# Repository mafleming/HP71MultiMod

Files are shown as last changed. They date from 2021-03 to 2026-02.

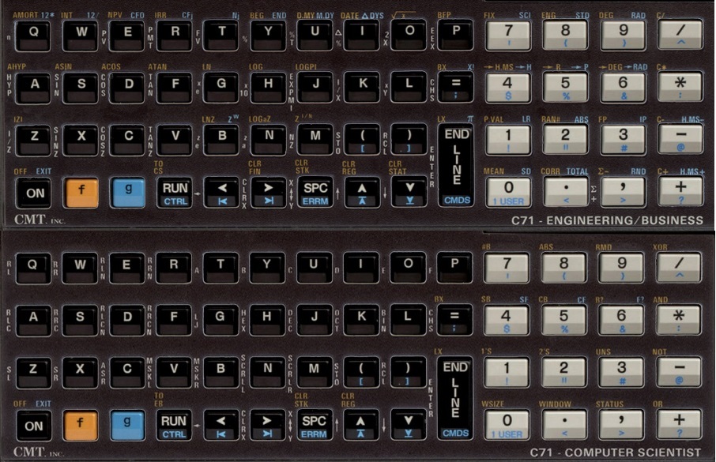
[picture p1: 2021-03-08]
doc/c71_ovl.jpg

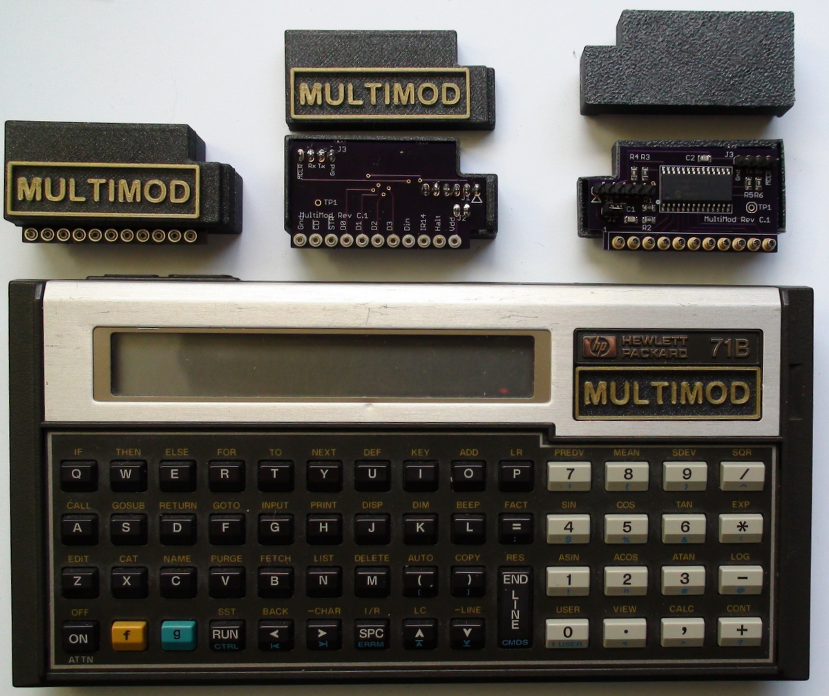
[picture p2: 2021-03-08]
MultiMod Board and Enclosure.JPG

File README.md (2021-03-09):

HP71MultiMod Repository

# A ROM Emulator Board for the HP-71B
This repository contains the source and data files associated with
the MultiMod ROM emulator board. The board fits into the Card Reader
well of the HP-71B and can be used with an optional enclosure.

The emulator is easily programmed using just a USB to TTL Serial cable.
The emulator can enumerate up to 112 KB of ROM images stored in 7 16 KB
"chips" that can be combined to form ROMs of size 16 KB, 32 KB, 48 KB,
or 64 KB.

Further details on the ROM emulator, how it works and how to use it, can
be found in the User Manual.

# Directory structure
- The **BIN** directory will contain ROM images in .BIN format. For the
moment, images of HP ROMs are not present. ROM images available from and
hosted by others will only be added by permission. Links will be provided
in the meantime.
- The data files containing ROM images can be found in the **DAT** directory.
- The **HEX** directory will contain files that can be used to program the PIC
processor in the MultiMod directly using a Microchip programmer and IPE
software.
- The **LIF** directory contains floppy disk images in HP's proprietary LIF
format. These images contain various useful programs.
- The **doc** directory contains documentation for the MultiMod emulator
as well as for some of the ROM images.
- The **utils** directory contains useful utilities, including python scripts
to convert .BIN files into the .DAT files used by the MultiMod serial monitor.
- The **src** directory contains the MPASM assembly source files used to
program the MultiMod PIC processor. Version 5.35 or earlier of the Microchip
MPLAB IDE X is needed to use the MPASM assembler and linker.

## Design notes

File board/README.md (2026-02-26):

HP71MultiMod Repository

# A ROM Emulator Board for the HP-71B
This directory contains the Gerber files for creating a MultiMod PCB
along with PDF files of the schematic and BOM. The original design was
created using Eagle CAD 5.0, a PCB design platform that sadly went
extinct quite some years ago.

The board uses SMD parts so you'll either need a reflow oven (I built
one from the Wizzo kit, link below) or have the fine motor skills needed to
solder the parts yourself. The passives are 0805 in size which is
reasonably large for hand soldering. The part numbers given in the BOM are
from Mouser, but you can substitute manufacturer and supplier while
maintaining proper value. No substitute on the PIC CPU unless you know what
you're doing!

https://www.ebay.com/itm/305219966463

Once a board is assembled you'll need to program the PIC CPU using either
a PICKit-3 or PICKit-4 programmer, and the MPLAB X IPE or IDE software.
I developed the code and program PICs using version 5.50, available for
Windows and Linux.

I've used OSH Park as my PCB supplier and OSH Stencil for the solder paste
application.

## MultiMod Enclosure
Recently added are the STL files for the top and bottom half of the MultiMod
enclosure. Enjoy!

## Press Fit Harwin Sockets
The Sockets.jpg image shows how I press fit the Harwin sockets into a MultiMod
PCB. The three parts of the image show

- (a) The socket holder is a brass piece about 1/4" square. In it are drilled
11 holes 0.15" apart with a #38 or 5/32" drill. The holes are slightly larger
than the socket body and provide a loose fit for the socket tail end.
- (b) I usually start the press fit with the outer six sockets, followed by the
inner five. Note that the socket heads are inserted from the back of the board,
with the socket tails upward from the component side of the PCB.
- (c) Place the board and socket holder in a vise, then press the outer six
sockets for a partial fit. Add the inner five sockets and press all eleven to
final position. Don't press the sockets all the way down, leave about a
fingernail width between the bottom of the socket head and the PCB surface.
This will provide a tight fit in the board without a chance of crushing the
socket body.

The Card Reader pins are 1 mm in diameter. I use the shaft end of a number 61
drill inserted into the socket from the socket head end to clear the sockets
before inserting the board into the Card Reader well.

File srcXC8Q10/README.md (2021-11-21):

MultiModII.X

These source files are suitable for the PIC18F2-Q10 family of processors. The
low power requirements of the Q10 make it suitable for a front port module
implementation. The bootloader and serial port monitor code has been removed.
ROM images and code would be updated using a PICKit-3 or better programmer.

The project is built in a similar way as the main MultiMod code in the src/
subdirectory. Instead of the MPASM assembler, the pic-as assembler in the XC8
compiler package is used. Use the MPLAB X IDE version 5.45 or higher. Create
a standalone project, select the PIC18F27Q10 as the target processor, select the
pic-as assembler as the build tool, and then add these files to the Source Files
folder of the project directory tree in the IDE. Assemble, Link, then program
using a PICKit-3 or PICKit-4 programmer.

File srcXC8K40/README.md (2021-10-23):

HP71MultiMod Repository

# A ROM Emulator Board for the HP-71B
**23-October-2021**

Source files for the MultiMod board. These files
are assembled, linked, and loaded with pic-as v2.32 in MicroChip MPLAB X IDE v5.45.
The assembler is part of the XC8 development compiler. MPLAB X and XC8
can be obtained from Microchip.com in their development tools repository.

This port of the MultiMod application code from MPASM to pic-as has been done
for two reasons; MPASM is no longer supported by Microchip, and the pic-as
assembler is needed to transfer code to more recent PIC microcontrollers.

# Build Instructions
First create a standalone application project with the suggested name of
MultiModK40. Copy all  files to the base project directory.
In the Project Configuration dialog under Loading, add the
BootLoaderK40.X.production.hex file.
Be sure to specify the target processor as PIC18F27K40, then build
the project.

# Errata
Maintenance issues that are addressed are listed here.

- Carriage return for the Commit command defaults to NO rather than YES.
- Detect buffer overrun and terminate ROM image upload for Image command.

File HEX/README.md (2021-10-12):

HP71MultiMod Repository

# A ROM Emulator Board for the HP-71B
HEX files used to program the ROM emulator software using a PICKit
or other PIC programmer will be found here. HEX files containing
the entire PIC flash memory including boot loader are named MMimage
with a four digit version number, while files containing only the
ROM emulator code itself are named MultiMod with a four digit version
number.

Instructions for using the boot loader to update the emulator software
can be found in the User Manual appendix. Files are

- MMimagexxyy.hex     Entire PIC flash image for programming tool
- MultiModxxyy.hex    ROM Emulator software image for bootloader

where xx = major number and yy=minor number.

Version 0103 - fixes ROM table corruption when software flow control is
        not used when sending an image to the serial monitor
Version 0104 - fixes failure to unconfigure ROMs when a RESETX command
        is issued

The file devices.zip contains an updated version of the bootloader client
database of PIC microcontrollers. The PIC18 used in the MultiMod has been
added to the database. Rename the default devices.db and replace it with
the one in this devices.zip file before proceeding with the client update
instructions.

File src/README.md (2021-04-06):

HP71MultiMod Repository

# A ROM Emulator Board for the HP-71B
**27-March-2021**

Source files for the current production release of the MultiMod board. These files
are assembled, linked, and loaded with MPASMX in MicroChip MPLAB X IDE v5.35,
which can be obtained from Microchip.com in their development tools repository.

# Errata
Issues that will be addressed in maintenance and enhancement releases are listed here.

- Carriage return for the Commit command should default to NO rather than YES.
- Detect buffer overrun and terminate ROM image upload for Image command.
- Display software version number in serial monitor.
- Display ROM name in ROM Configuration Table listing.
- Locate serial monitor on sector boundary so it can be updated separately from emulator.
- Allow readback (PEEK$) of MMIO configuration buffer data.
- Make timeout to processor sleep state configurable by user (current default 2.5 minutes).

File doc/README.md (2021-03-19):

HP71MultiMod Repository

# A ROM Emulator Board for the HP-71B

The User Manual for the MultiMod board can be found here along with other
ROM related documentation. Documentation for the HP ROMs can be found in
various locations, but they are also collected together in one place in
the Museum of HP Calculators flash drive. See the link below for details
on ordering a copy

https://www.hpmuseum.org/cd/cddesc.htm

|Filename | Document |
| ----- | ----- |
| C71.pdf | The Soft Forth-based RPN calculator emulator manual |
| doc_lib52.txt | Documentation for J-F's User Library of LEX files |
| symbolix.txt | Joe Horn's Symbolic CAS Basic program documentation |

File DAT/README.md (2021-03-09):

HP71MultiMod Repository

# A ROM Emulator Board for the HP-71B
The following files represent data images of well-known ROMs available
for the HP-71B. The table shows the ROM content of each file. These
data files were created from the original .BIN files using the utility
program bintodat.py

|Filename | HP-71B ROM | Size |
| ----- | ----- | -----  |
| accap.dat | The AC Circuit Analysis ROM | 16K |
| ampi-stat.dat |The Ampi-Statistics ROM | 32K |
| c71.dat | The C71 Forth-based RPN Calculator ROM | 64K |
| curve-fit.dat | The Curve Fitting ROM | 32K |
| data-acq.dat | The Data Acquisition ROM | 64K |
| data-comm.dat | The Data Communications ROM | 16K |
| finance.dat | The Finance ROM | 16K |
| forth1b.dat | The Forth-Assembler ROM | 16K |
| forth1bhrd.dat | The Forth-Assembler Hard ROM | 32K |
| hp41trans.dat | The HP-41 Translator ROM | 16K |
| hp41transhrd.dat | The HP-41 Translator Hard ROM | 32K |
| hpil1b.dat | The HP-IL version 1B ROM | 16K |
| joesbest.dat | A Collection of LEX Files by Joe Horn | 32K |
| joesbest-nokbeep.dat | Joe's Collection Without KBEEP | 32K |
| jpcf05.dat | The JPC ROM Maintained by J-F Garnier | 32K |
| math.dat | The Math Pac ROM | 32K |
| math2b.dat | J-F Garnier's Extension of Math Pac | 32K |
| math-p.dat | | 32K |
| surveying.dat | The Surveying ROM | 16K |
| symbolix.dat | Joe Horn's Symbolix CAS Program | 32K |
| text-edit.dat | The Text Editor ROM | 16K |
| ulib52.dat | J-F Garnier's LEX User Library | 32K |
| ulibcopy.dat | J-F's Library with the ROMCOPY LEX | 32K |

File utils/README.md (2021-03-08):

HP71MultiMod Repository

# A ROM Emulator Board for the HP-71B
Utility and support files are provided in this directory. The most
significant for MultiMod configuration is the python3 script
bin2dat.py which is run using the command

python3 bin2dat.py <.BIN filename> <.DAT file name>

If input and output files are not specified, then they default to
standard input and standard output.

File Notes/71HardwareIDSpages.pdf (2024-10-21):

+------- | ----------------------------------+ -------- | -+

+----- ------- ------------- -----------------+- ----------------+

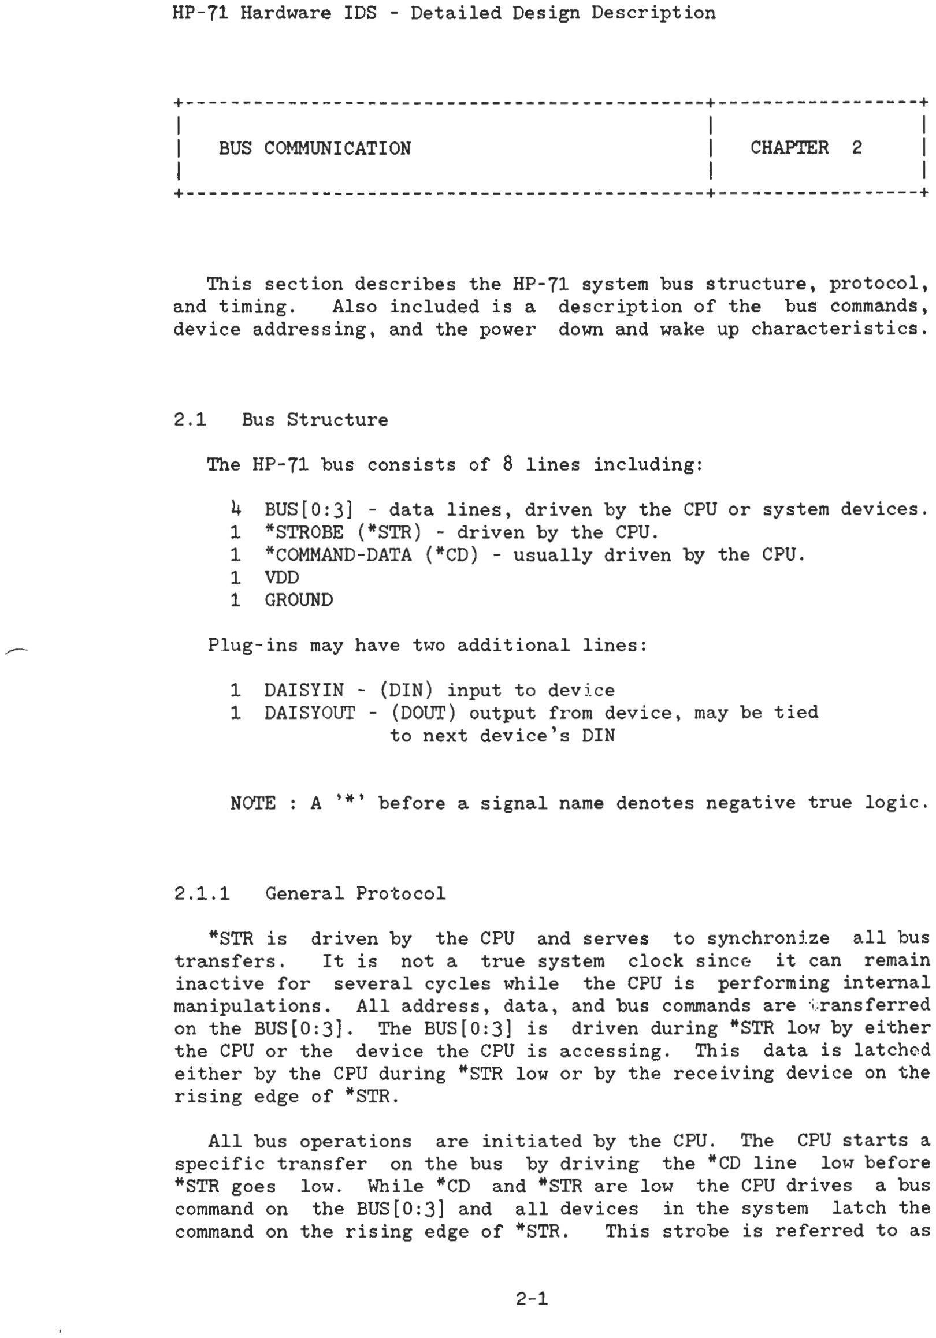
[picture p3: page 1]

Hardware IDS - | Descr | ion
BUS | CHAPTER 2

2.1

The
4
1
1
1
1

section describes the
Also included is a
address ,and the power

Bus Structure

bus structure, | ,
descr | ion of the bus commands,
down and wake up | sties.

bus consists of 8 lines

BUS[O:3] | data lines, | CPU or | devices.
( | ) - driven
( | ) - | the CPU.
VDD
GROUND

ins may have two additional lines:

1 DAISYIN-
1 DAISYOUT | from device, may be tied
to next device's DIN
NOTE | A '*' before a s | name denotes | true
2.1.1 | General Protocol
is driven | the CPU and serves to | ize all bus
transfers. | It is not a true | clock since it can remain
inactive for several | while the CPU is | internal
ions. All addres s , data, and bus commands are ·i.rans ferred
on the BUS[O:3J. The BUS[O:3] is driven | low | either
the CPU or the device the CPU is access | This data is latched
the CPU | low or | the rece | device on the
ris | of
All bus | ions are ini tj.ated | The CPU starts a
ific transfer on the bus | | the | line low before
goes low. While | and | the CPU drives a bus
command on the BUS[O:31 and all devices | latch the
command on the ris | of | This strobe is referred to as
| 2-1

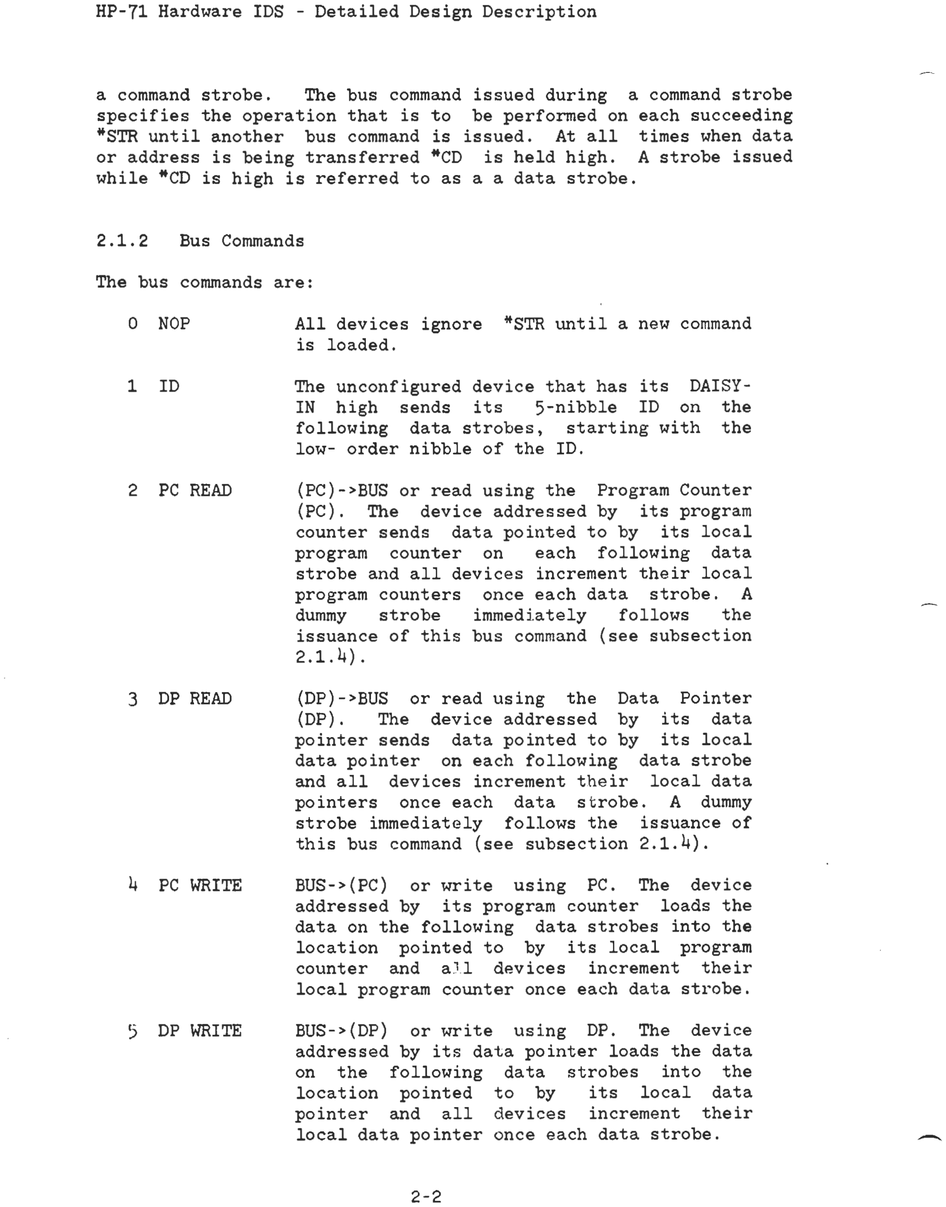
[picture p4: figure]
Hardware IDS - Deta; Des; a command strobe. ies the unt il another or address is be; while; The bus command; a command strobe; that is to; on each; transferred; is held; A strobe issued; is referred to as a a data strobe.; Bus Commands; The bus commands are:; o NOP; 2 PC READ; 3 DP READ; 4 PC WRITE; 5 DP WRITE; All devices is loaded.; until a new command; unconf; device that has its DAISY-; sends its; 5-nibble ID on the; data strobes, start; with the; low- order nibble of the ID.; (PC)->BUS or read us; the; Counter; (PC). The device addressed; program; counter sends data pointed to; its local; program counter on; each; data; strobe; follows; ) >BUS or read us; the Data Pointer; The device addressed; its data; sends data pointed to; data pointer on each; data strobe; pointers once each data strobe. A; strobe immed; follows the issuance of; BUS->(PC) addressed data on the; see subsection 2.1.4).; or write us; PC. The device; its program counter loads the data strobes into the; location; its local program; BUS->(DP) addressed on the location; write us; DP. The device; data pointer loads the data data strobes into the; its local data; pointer and all devices increment their

bus command is issued. At all t when data

strobe and all devices increment their local program counters once each data strobe. A

issuance of this bus command (see subsection

and all devices increment their local data

counter and a.¹.1 devices increment their local program counter once each data stl'obe.

local data pointer once each data strobe.

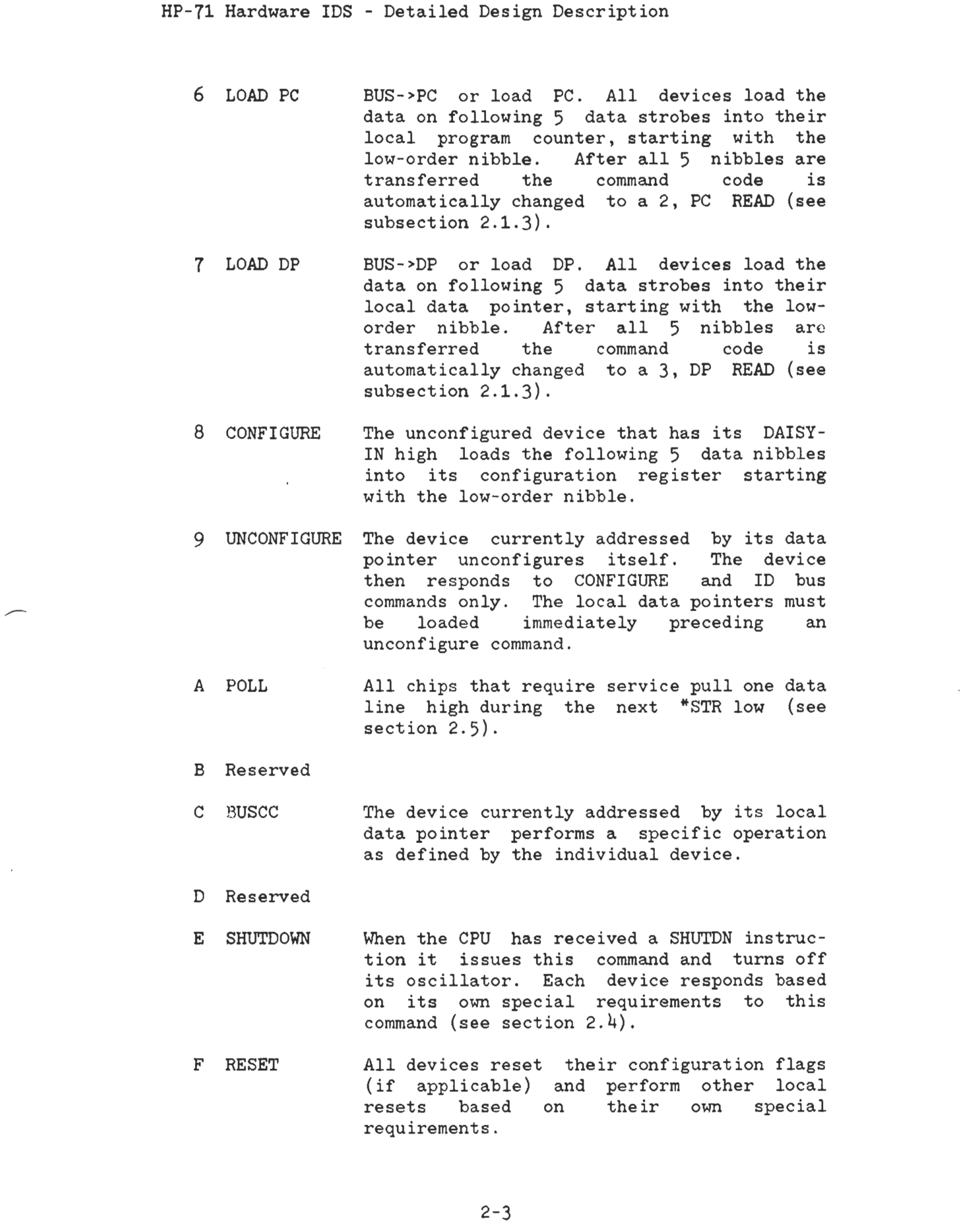
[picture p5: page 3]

Hardware IDS - Detailed Des | Descr | ion

6 LOAD PC

7 LOAD DP

8 CONFIGURE

9 UNCONFIGURE

A POLL

B Reserved

C BUSCC

D Reserved

E SHUTDOWN

F RESET

BUS->PC or load PC. All devices load the
data on | | 5 data strobes | | their
local program counter, | with the
low-order nibble. | After all 5 nibbles are
transferred | the | command | code | is
automat | to a 2, PC READ (see
subsection 2.1.3).
BUS->DP or load DP. All | load the
data on | 5 data strobes into their
local data pointer, start | with the low-
order nibble. | After all 5 nibbles aro
transferred | the | command | code | is
automat | to a 3, DP READ (see
subsection 2.1.3)

The
IN h

that has its DAISY-5 data nibbles
into its
with the low-order

line

immed
command.

section 2.5).

The device

addressed
itself.
CONFIGURE
local

service
next
data pointer | a

its data
The device
and ID bus
must
an

one data
low (see

as defined the individual device.

When the CPU has received a SHUTDN instruc-tion it issues this command and
its oscillator. Each device

turns off
based
on its own special | irements to this
command (see section 2.

All devices reset
(if | )
resets | based
s.

2

their conf
and
on their

ion
other
own

local

Hardware IDS - Detailed Des | ion
2.1.3 | Command Auto-Switch

There exists one special ~nse in which all devices
current bus command. | This is called 'auto"switch'
fo | the load of either the PC or the DP. | On the
of | nibble of address has been loaded
clear bit 2 of their command latch | the bus
a LOAD PC to PC READ or LOAD DP to DP READ.
2.1.4 | Strobe

their
and occurs
ris
all devices
command from

a PC READ bus command, a DP READ bus
command, and a command auto-switch the CPU issues a ' | strobe'.
This | strobe appears as a data strobe | that no data is
transferred | this | not ilJ.:rement their
local address
a full strobe

2.2 Address

sters.
for the

Each device on the HP-local program counter (PC) device is also either
or
address space
reads and writes
on the read or
space.

The HP-

memory devices
first access and therefore allows data

bus has two 20-bit address
and a local data pointer
addressed at a specific address located within
to
(PC or DP

the
data
its | address

allows soft
have address | size from
All devices are | that the | of the
local address | with the | bits of
the device's | or soft). | If these bits
are identical, the devi.ce has an address match and will | to
read and write commands (and the | and BUSCC commands if
). Each device with a given address space size compares
a given number of the | bits of address. For | , a
device with an address space size of 1K | or 2K nibbles
11 bits of address leav | the upper 9 bits for its
ion

2-4

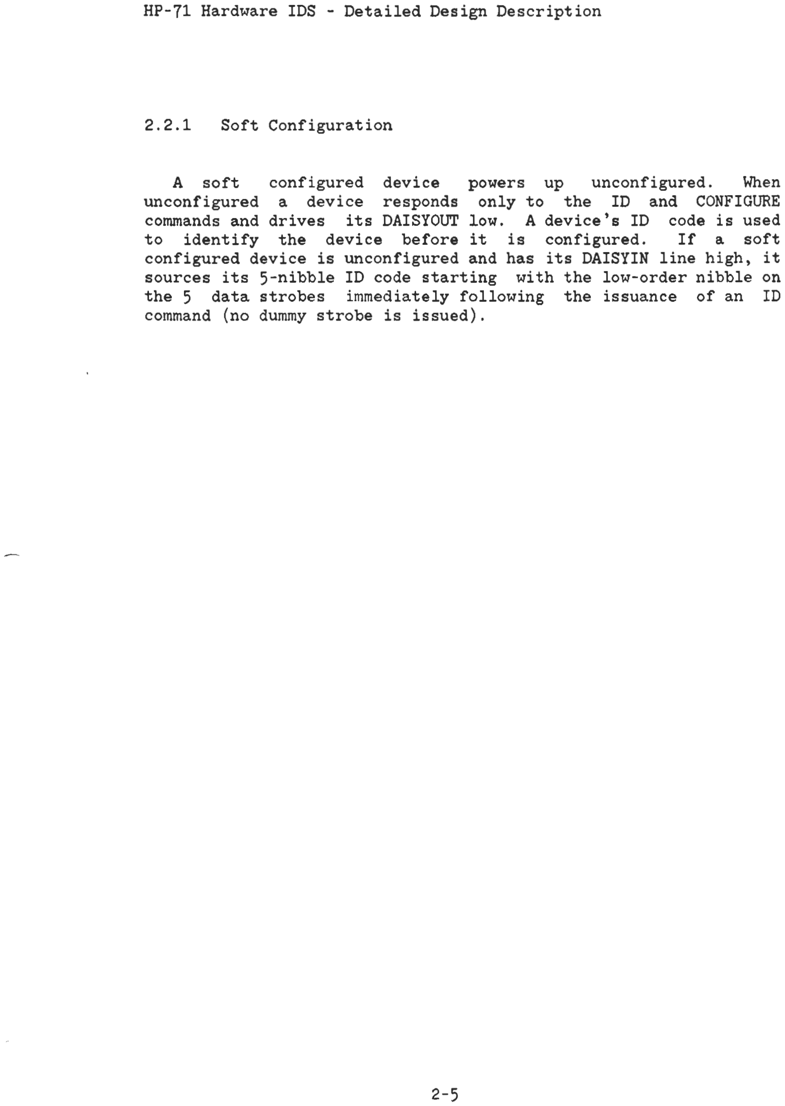
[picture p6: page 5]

HP- | Hardware IDS - Detailed Des | ion
2.2.1 | Soft

sources its
the 5 data
command

ion

device | powers up | When
to the ID and CONFIGURE
DAISYOUT low. A device's ID code is used
device before it | If a soft

2

its DAISYIN line , it
the low-order nibble on
the issuance of an ID

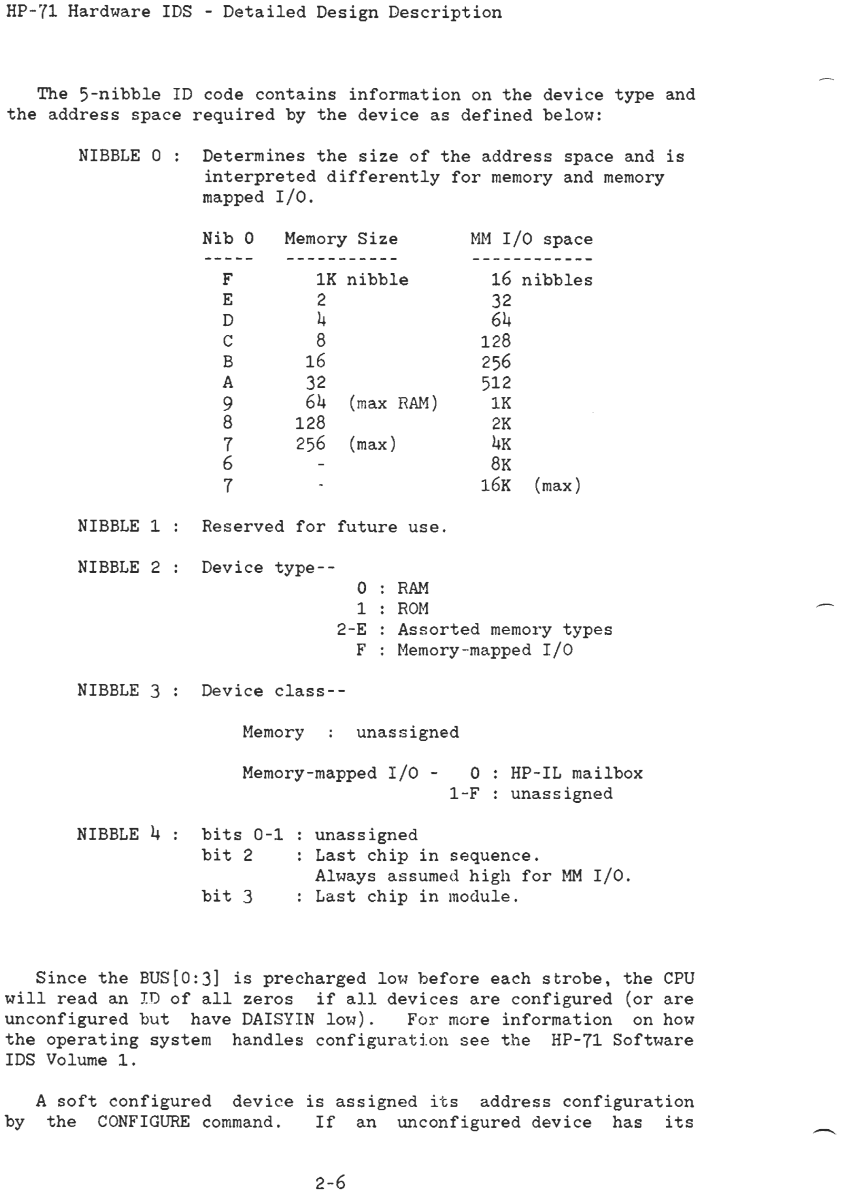
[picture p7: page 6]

Hardware IDS | Detailed Des | ion
The 5-nibble ID code contains information on the device | and
the address space | the device as defined below:
NIBBLE 0 : | the size of the address space and is
d | for memory and memory
Nib 0 | Size | MM | space
F | lK nibble | | nibbles
E | 2
D | 4
C | 8
B
A
9 | RAM) | lK
8 | 2K
7
6
7
NIBBLE 1 | Reserved for future use.
NIBBLE 2 | Device
0 | RAM
1 | ROM
| 2-E
| F
NIBBLE 3 | Device class--
| unass
| I | 0 | HP-IL mailbox:
| | l-F | unass
NIBBLE 4 | bits 0-1 | unass
bit 2 | Last | in sequence.
assumed h | for MM
bit 3 | Last ch | in module.
Since the BUS[O:3] is | | low before each strobe, the CPU
will read an 10 of all zeros if all devices are | are
but have DAISYIN low). | For | on how
handles | | Software
Volume 1.
A soft | device is ass | its address
the CONFIGURE command. | If an | device has its | -..
| 2

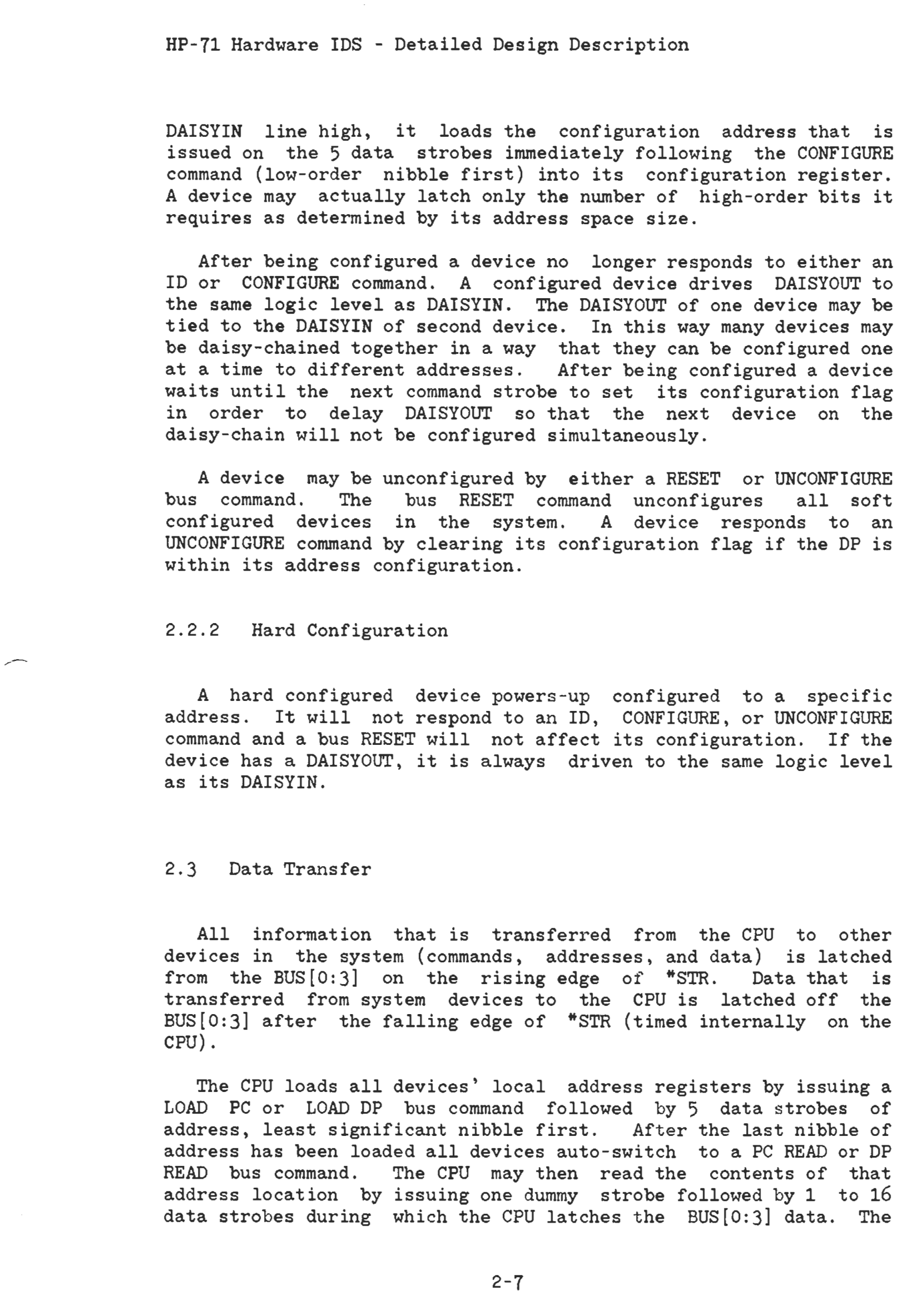
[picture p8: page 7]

HP- | Hardware IDS | Detailed Des
DA1SYIN line | it
issued on the 5 data strobes command (low-order nibble first)
A device may | latch
as determined | its address space size.
After be | conf | to either an
1D or CONFIGURE command. | conf | device drives DA1SYOUT to
the same | level as DAISYIN. The DAISYOUT of one device may be
tied to the DAISYIN of second device. In this way many devices may
be | in a way that | be conf
addresses. | After
next command strobe to set DA1SYOUT so that the
be | simultaneous

A device may be
bus command. The

either a RESET or UNCONFIGURE all soft
devices | to an
UNCONFIGURE command
within its address

2.2.2 Hard

bus RESET
the

command
A device
its | ion | the DP is
A hard | device powers-up | to a spec
address. | It will not
command and a bus RESET will
device has a DA1SYOUT, it is
as its DAISYIN.

to an 1D. CONFIGURE, or UNCONFIGURE
| not affect its | If the
2.3 | Data Transfer

All information
devices in the

that is transferred from
(commands, addresses. and
from the BUS[O:31 on
transferred from system
BUs[o:31 after the
the ris | of
devices to the CPU is
of | (timed

level

the CPU to other
data) is latched
Data that is
latched off the
on the
The CPU loads all devices' local address | is | a
LOAD PC or LOAD DP bus command followed | data strobes of
address, least s | nibble first. | After the last nibble of
address has been loaded all devices auto switch to a PC READ or DP
READ bus command. | The CPU may then read the contents of that
address location | i | one | strobe followed | 1 to
data strobes dur | which the CPU latches the BUS[o:31 data. The
| | 2-7

Hardware IDS - Deta | Des | Des | ion
CPU may read without first | | the local address
a PC READ or DP READ, data strobes. The | | | strobe, followed
the BUS[O:31 low each
goes low. Therefore if no device | the
CPU reads zeros.

The CPU writes the contents of a speciflc addressed location
It is not | to load the local address
before is | PC WRITE or DP WRITE command. The
write command is followed | 1 to | data strobes | the
addressed device latches the BUS[O:3] data.

All devices
data strobe
read | ion
| their local

into another device.
bus may read and write more than
| | a~dress | once each
It is possible for a
one device and cross the
Future controllers on the
| | nibbles at a time.

Two other
5-nibble read with
is a
transfers
DAISYIN line
section 2.5.

of data transfers are
no address load or
write with no address
that a device be
| | ID, which is s | a
strobe, and CONFIGURE,
load. Both these data
| | | and that the
POLL is a un | read and is discussed in

2.4 Power down; Wake up

The | can be shutdown under software control. The
CPU executes a SHUTDN hstruction | a SHUTDOWN bus command
and on the | clock ( | ) and its
own oscillator. While in shutdown mode all data stored in RAM and
CPU resident memory is | 'rlhe CPU is | out of
shutdown mode | either | • or
low.
| is driven low to wake up | | a device in
the | that needs service while the | is | shutdown mode.
If a device wakes up the CPU and the CPU shuts down without
satis | its service | the device will not wake up the CPU
until its service | has been satisfied and it needs
service | This avoids a situation where the
does not know how to handle a device's service
shutdown. For more information on pON"er down and wake up see section 3.5.

2

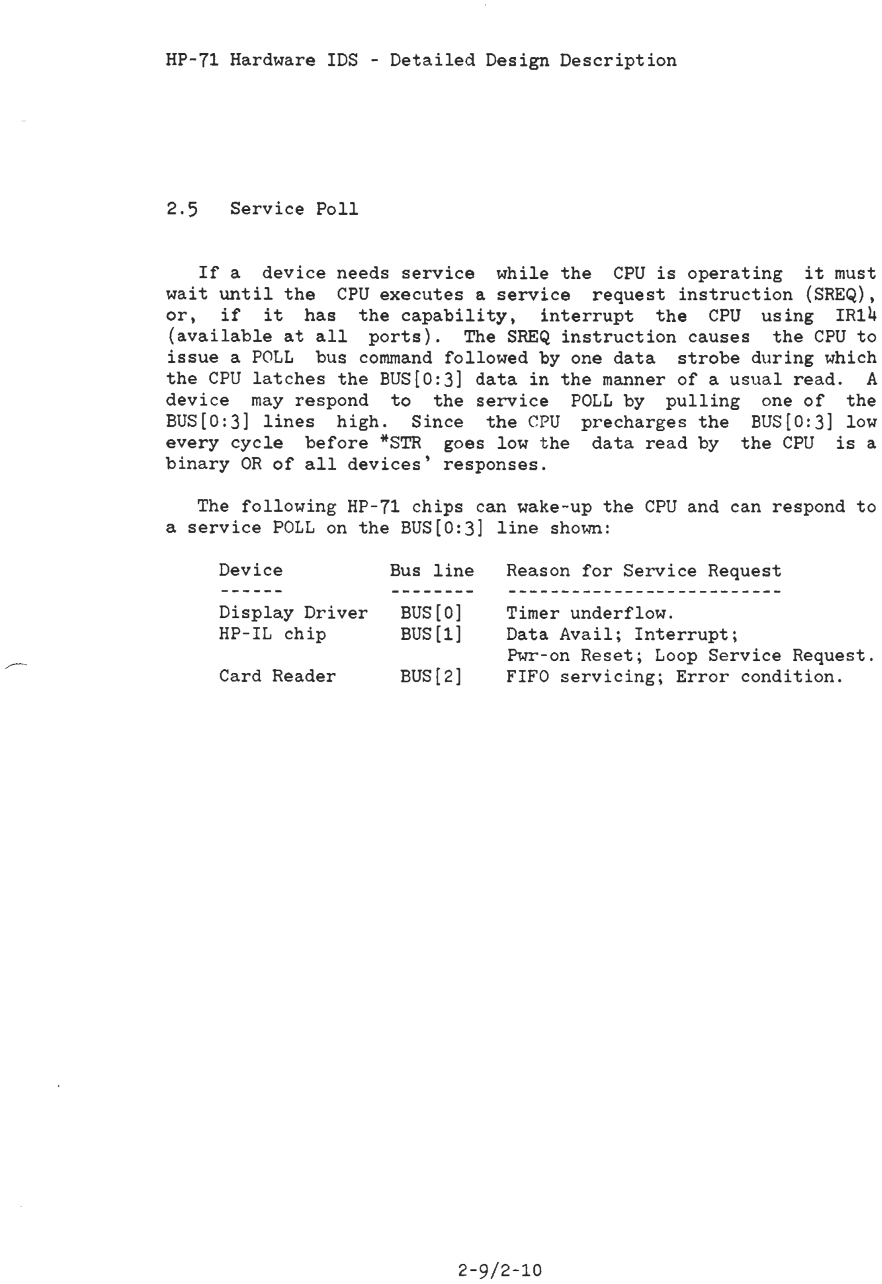
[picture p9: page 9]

Hardware IDS - Detailed Des

2·5 Serv Poll

If a device needs service
until the CPU executes a
or, if it has the
(available at all
issue a POLL bus command followed the CPU latches the BUS[0:3] data in

every

to the service
Since the CPU
goes low the
| devices' responses.

ion

data

The fo | HP- | ch | can | the CPU and can
a service POLL on the BUS 0:3] line shown:

Device

| Driver
HP-IL ch | | Bus line BUS[O] BUS[l] | | Reason for Service Timer underflow. Data Avail; Pwr-on Reset;

it must

to

Card Reader | BUS[2] | FIFO servic | Error condition.

2

+ ------------------------------ ------------+------------------+

+-- ------------------------- ----------------+------------------+

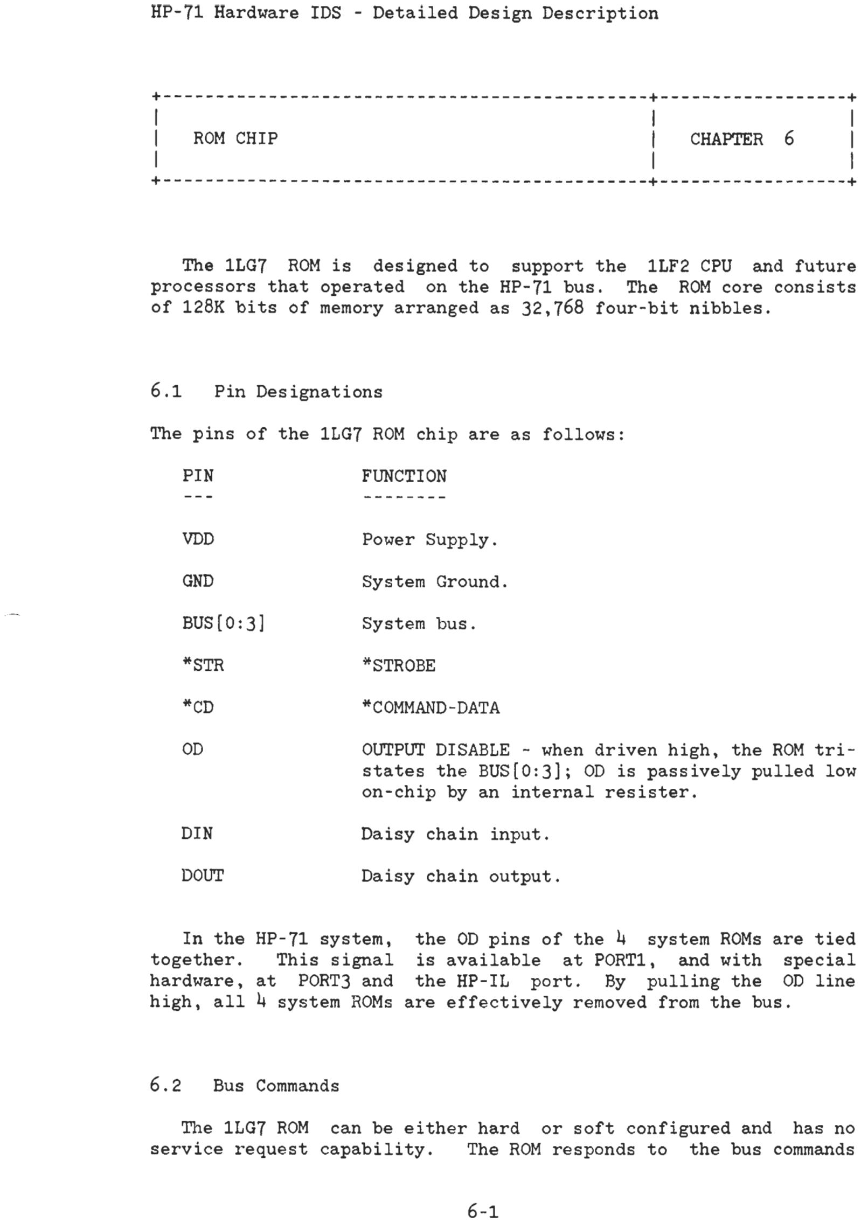
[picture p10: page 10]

Hardware IDS - Detailed Des | Des | ion
ROM CHIP | CHAPTER 6
The | ROM is des | to on the

the ILF2 CPU and future
bus. The ROM core consists four-bit nibbles.

processors that
of | bits of memory | as
6.1 | Pin Des

'l'he pins of the

PIN

VDD

GND

| BUS[O:31

OD

DIN

DOUT

In the

hardware, at
h | , all 4
6.2 | Bus Commands

The
service

ions

ROM are as follows:

FUNCTION

Power

| Ground.
| bus.
OUTPUT DISABLE | when driven
states the BUS[O:3]; OD is pass
on- | an internal resister.

chain

chain

the OD of the 4
is available at PORTI, and the HP-IL

ROMs are
with
the OD
are effect removed from the bus.

tri-low

tied

line

either hard or soft
The ROM

and has no
to the bus commands

6-1

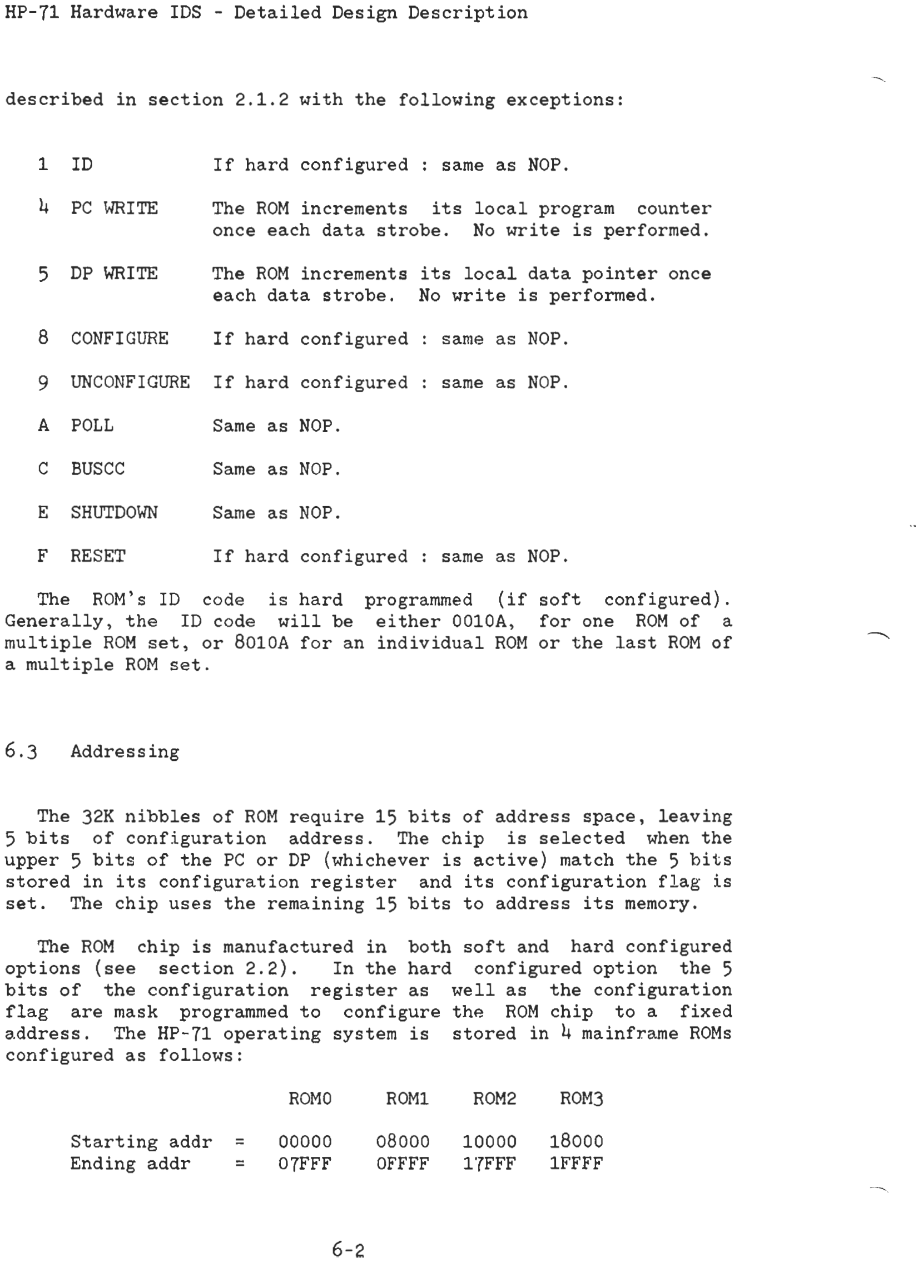
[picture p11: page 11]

HP- | Hardware IDS | led Des | Des | ion
described in section 2.1.2 with the | ions:
1 ID | If hard | : same as Nap.
4 PC WRITE | The ROM increments its local program counter
once each data strobe. No write is
5 DP WRITE | The ROM increments its | once
each data strobe. No write is
8 CONFIGURE | If hard | same as Nap.
9 UNCONFIGURE If hard | same as Nap.
A POLL | Same as Nap.
C BUSCC | Same as Nap.
E SHUTDOWN | Same as Nap.
F RESET | If hard | same as Nap.
The ROM's ID code is hard | soft | ) . , the ID code will be | for one ROM of a
ROM set, or | for an individual ROM or the last ROM of
ROM set.
6.3 | Address
The | nibbles of ROM | bits of address space,
5 bits of
upper 5
stored in
set. The
The | is selected when the

The ROM
(see
bits of the
are
a.ddress.

is active} match the 5 bits

is manufactured in both
section 2.2). | In the hard
its | ion | is
to address its memory.

ion
tha ROM | to a fixed
system is stored in 4 mainframe ROMs as follows:

ROMO

00000

2

ROMl

000
OFFFF

ROM2

10000
lFFFF

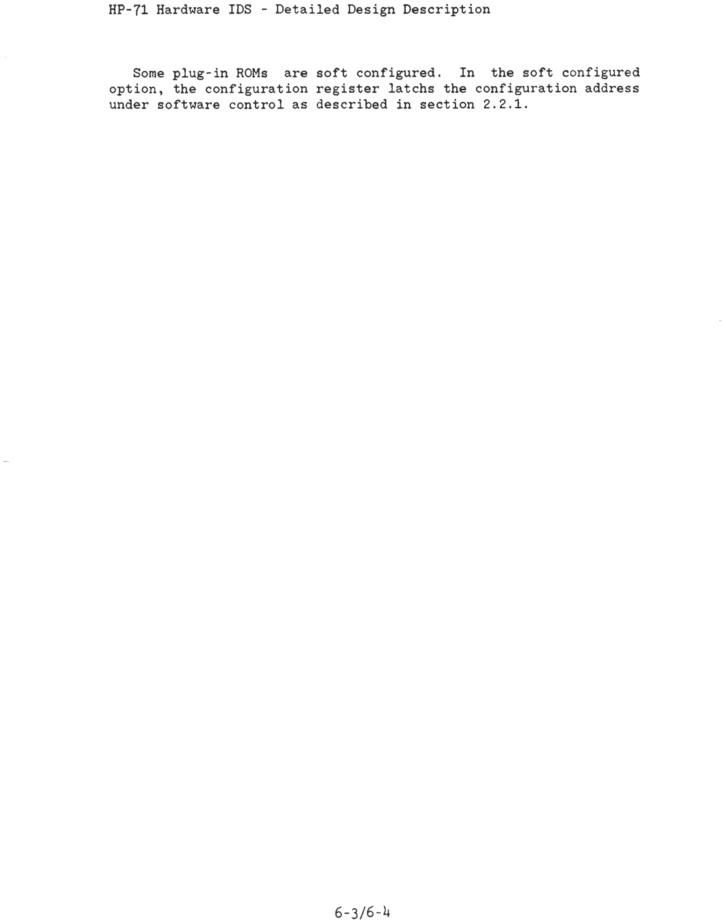
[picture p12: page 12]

Hardware IDS - Detailed Des | ion
Some | in ROMs are soft | In the soft
, the | ion | ster latchs the | ion address
under software control as described in section 2.2.1.

6 4

+--------- ---------------- | ------------+------- --------+
+---------- ---------------------------------+--- | --------+

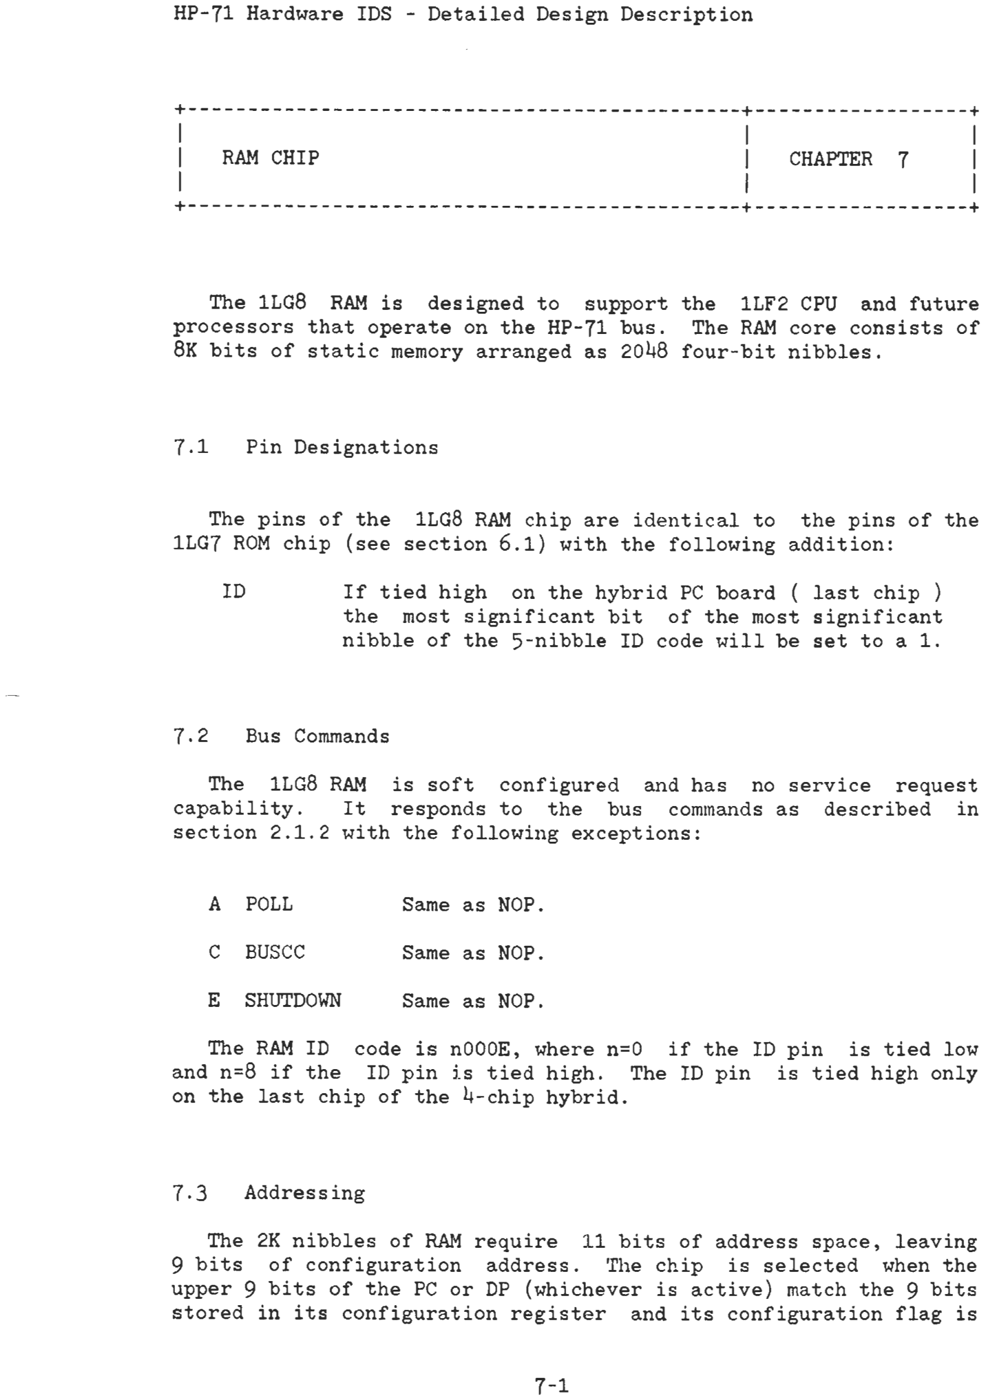
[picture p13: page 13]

Hardware IDS - Detailed Des | ion
RAM CHIP | CHAPTER 7

The

7.1

RAM is des
that

Pin Des ions

the 1LF2 CPU and future
The RAM core consists of
four-bit nibbles.
of the | RAM | are identical to the | of the
(see section
IO | f tied
the most
nibble of

7.2 Bus Commands

section

A POLL

C BUSCC

RAM is soft
It

Same as

Same as

E SHUTDOWN Same as

The RAM IO code
and | if the IO
on the last | of
7.3 | Address
6.1 with the | addition:

on the
ficant bit
5-nibble ID

Nap.

Nap.

Nap.

n=Q

PC board
of the most s
code will be set to a 1.

and has no service
commands as described in
ions!
if the ID | is tied low
The ID | is tied
The 2K nibbles of RAM | | 11 bits of address space,
9 bits of | ion address. 'fhe | is selected when the
upper 9 bits of the PC or OP | is active) match the 9 bits
stored in its | ion | and its conf | is

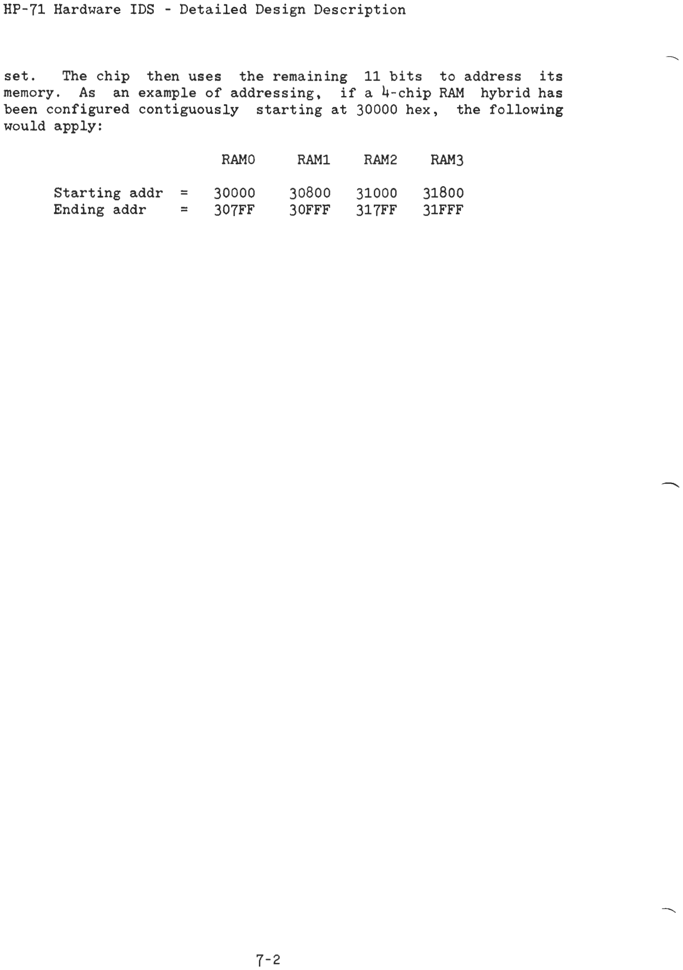
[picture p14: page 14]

HP- Hardware IDS - Detailed Des

set.
memory.
been
would
then | the remain
address
start | at
RAMO | RAM1

2

11 bits to address

RAM 2

RAM
the

its

+-- ------ ------------------------------------+-------------- -- +

+----- | ------------+------------- --+

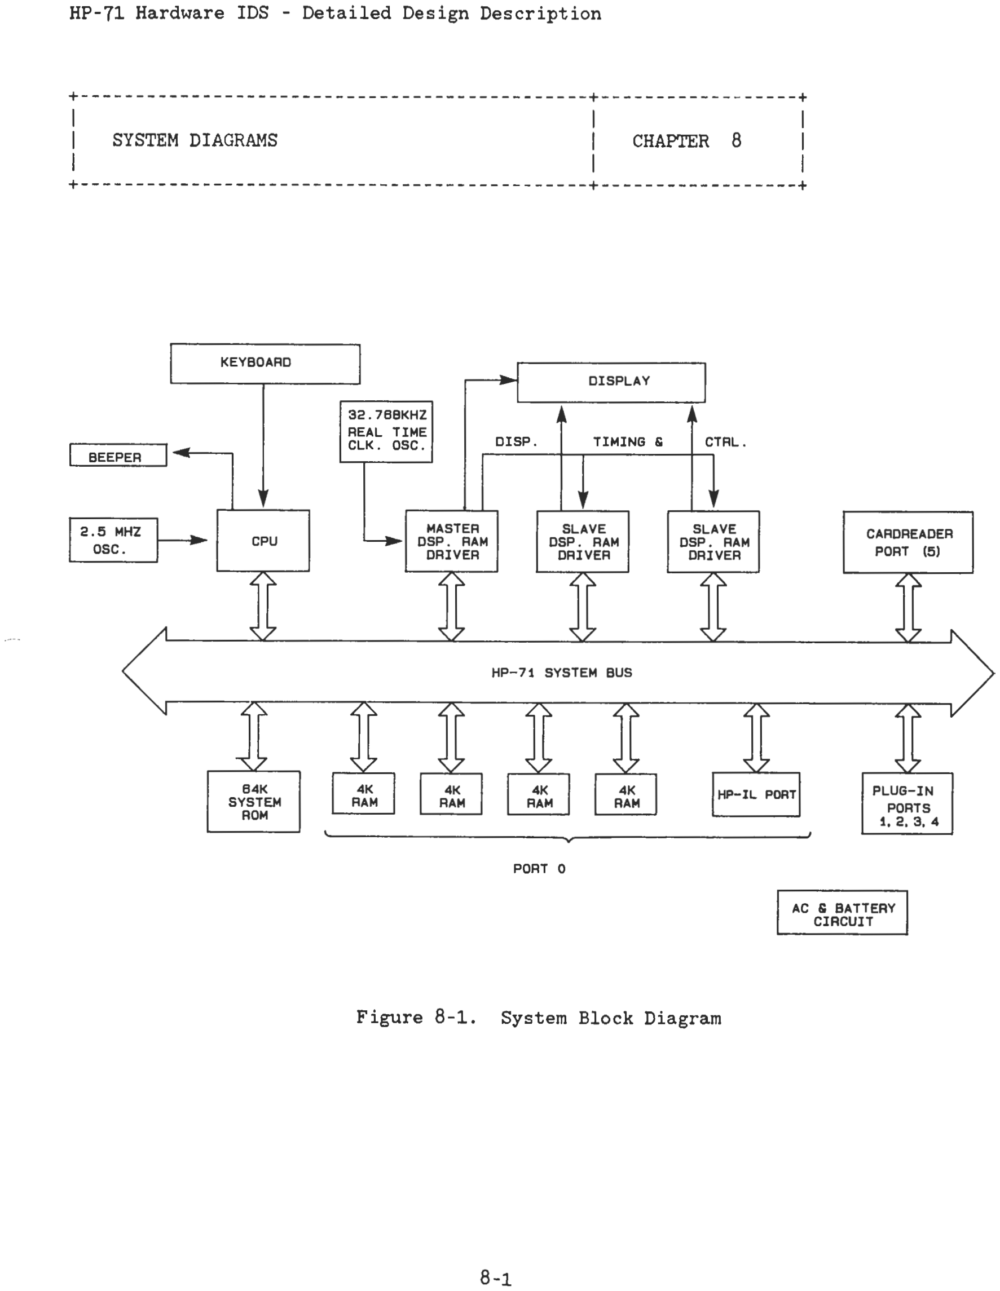
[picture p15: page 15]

Hardware IDS - Detailed Des | Des | ion
SYSTEM DIAGRAMS | CHAPTER 8

KEYBOARD
DISPLAY
OISP. | TIMING &

CPU

HP-71 SYSTEM BUS

PORT 0

F | Block

8-1

CARDREADER
PORT (lS)

PLUG-IN

1.2. 4

+-- | -+ | -- ------------+

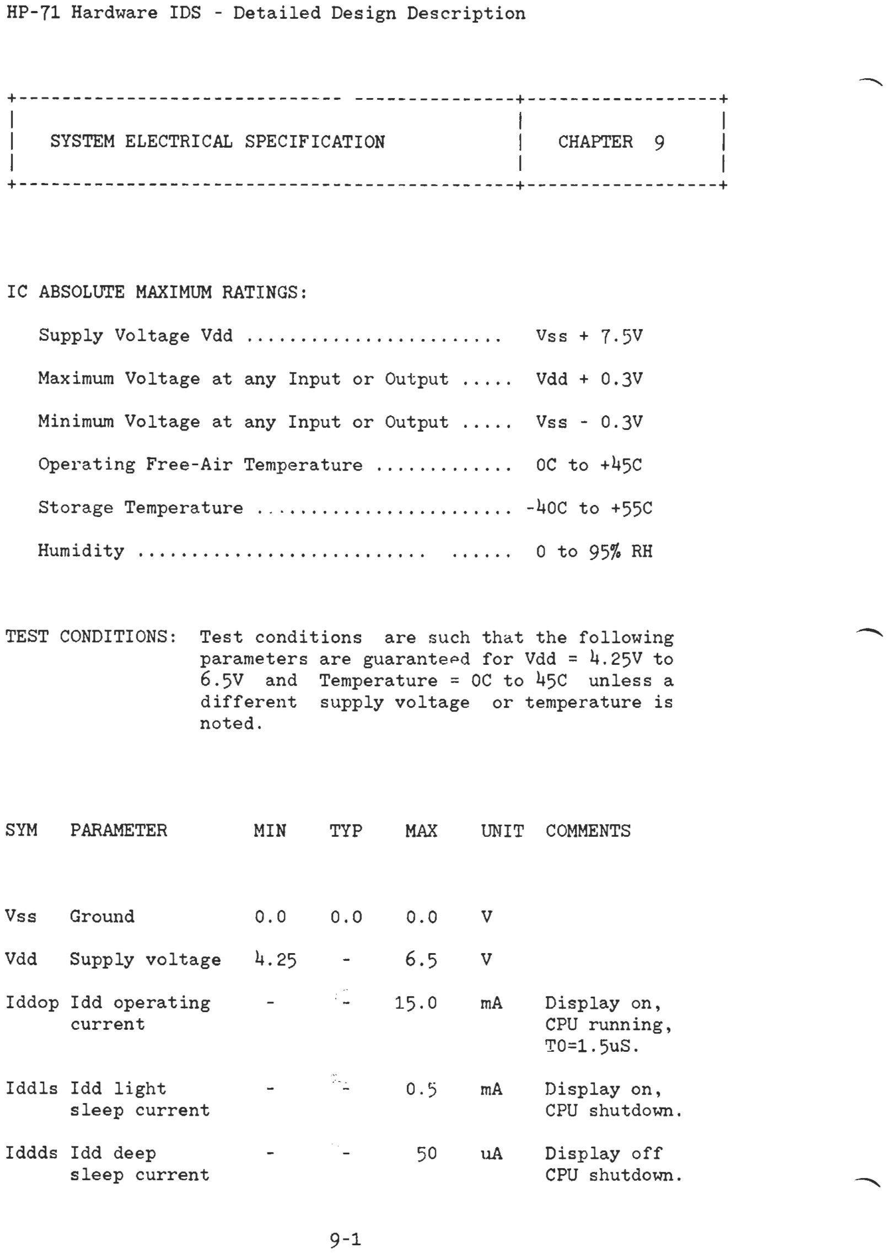
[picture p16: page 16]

Hardware IDS | Detailed Des
+ | -- ----------- -+
SYSTEM ELECTRICAL SPECIFICATION | CHAPTER 9

IC ABSOLUTE MAXIMUM RATINGS:
| Vdd | | Vss + 7.
Maximum | at any | or | Vdd + O.
| at any | or | Vss - o.
| Free-Air | | OC to
| | | to
o to | RH

TEST CONDITIONS: Test conditions are such that the

different
noted.
SYM | PARAMETER | MIN
Vss | Ground | 0.0
Vdd | | 4.
| Idd current

Iddls Idd
s current

Iddds Idd
s current

TYP

0.0

9-1

for Vdd ::
OC to
or | is
MAX | UNIT COMMENTS
0.0 | V
6.5 | V
.0 | rnA
0·5 | rnA | on, CPU shutdown.
| uA | off CPU shutdown.

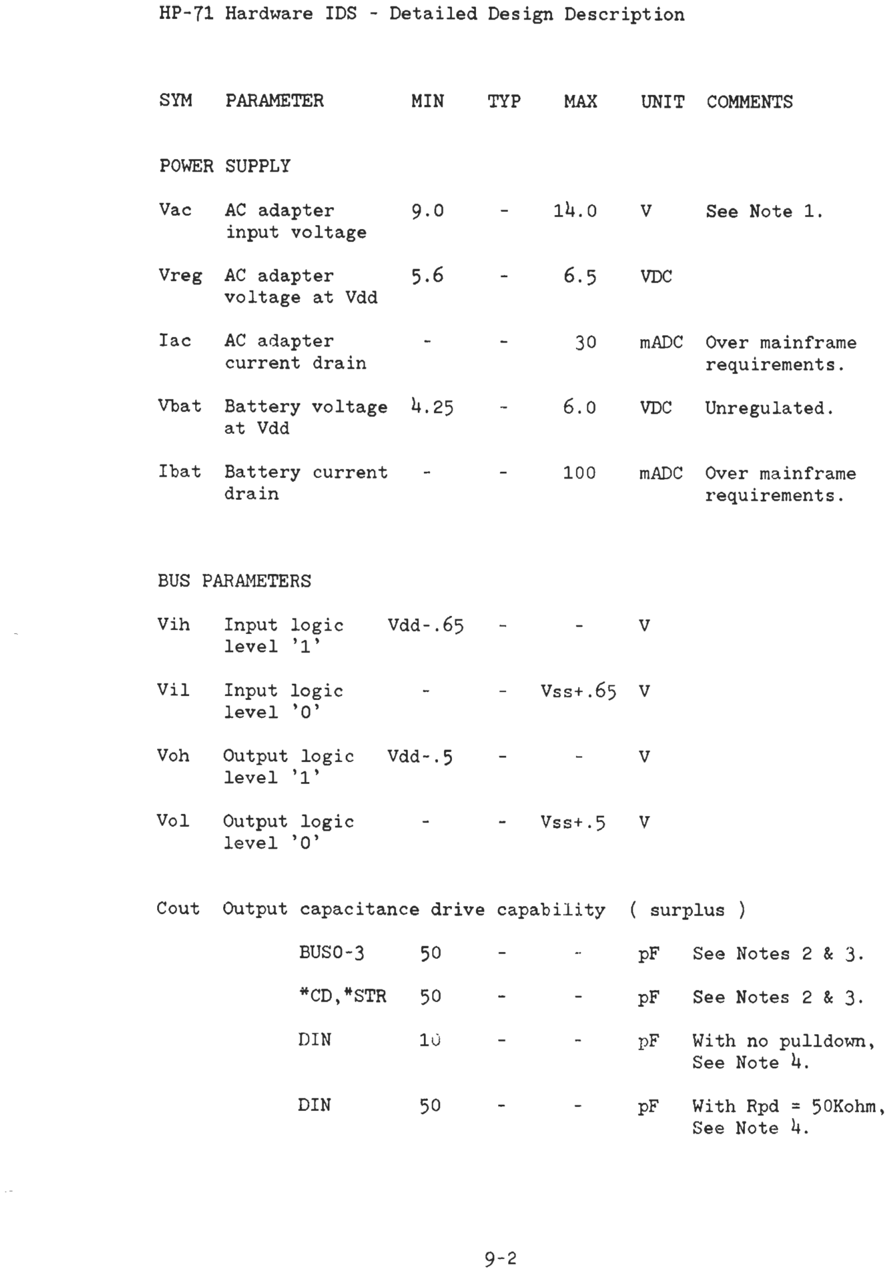
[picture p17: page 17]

HP- | Hardware IDS - Detailed Des | ion
SYM | PARAMETER | MIN | TYP | MAX | UNIT COMMENTS

POWER SUPPLY

Vac | 9·0 | .0 | V | See Note 1.
| | 5.6 | | 6·5 | VDC
Iac | AC | | | 30 | mADC Over mainframe
| current drain
Vbat | | 4. | | 6.0 | VDC
| at Vdd
Ibat | current | | | 100 | mADC Over mainframe
drain | s.

BUS PARAMETERS

Vih | Vdd- . | V
Vi! | Vss+. | V
level '0'
Voh | Vdd-.5 | V
level '1 '
Vol | Vss+.5 | V
level '0'
Cout | capacitance drive
BUSO | See Notes 2 & 3.

See Notes 2 & 3.

DIN | 10 | With no
See Note
DIN | With | ::::
See Note 4.

2

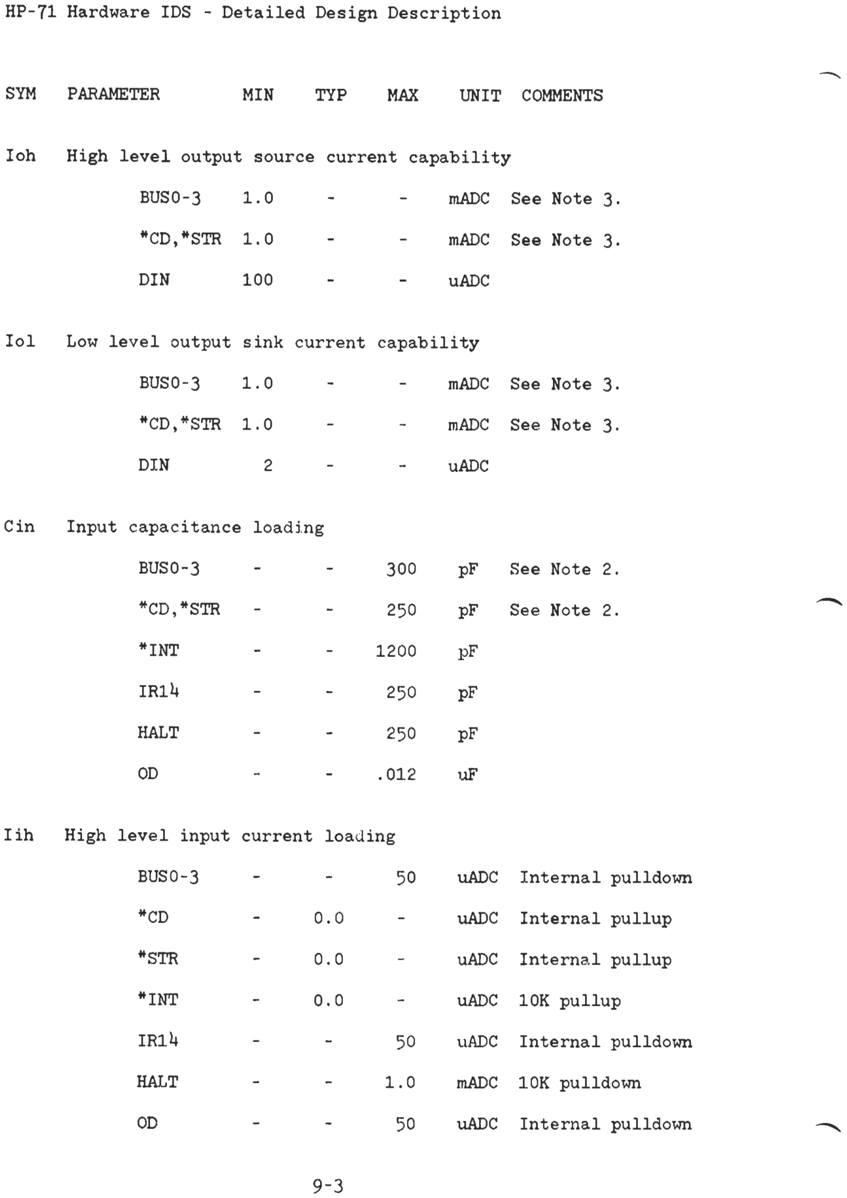
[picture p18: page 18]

Hardware IDS - | Des
SYM | PARAMETER | MIN | TYP | MAX | UNIT COMMENTS
Ioh | level | source current
| | 1.0 | | | mADC See Note 3.
| | 1.0 | | | mADC See Note 3.
| DIN | 100 | | | uADC
101 | Low level | sink current
| BUSO | 1.0 | | | mADC See Note 3.
| | 1.0 | | | mADC See Note 3.
| DIN | 2 | | | uADC

Cin

| | | | | See Note 2.
| | | | | See Note 2
| *INT | | | 1200

HALT

OD | .012 | uF
Iih | level | current
BUS 0 | uADC Internal
0.0 | uADC Internal
0.0 | uADC Interns,l
*INT | 0.0 | uADC 10K

\.lADC Internal

HALT | 1.0 | mADC 10K
OD | uADC Internal

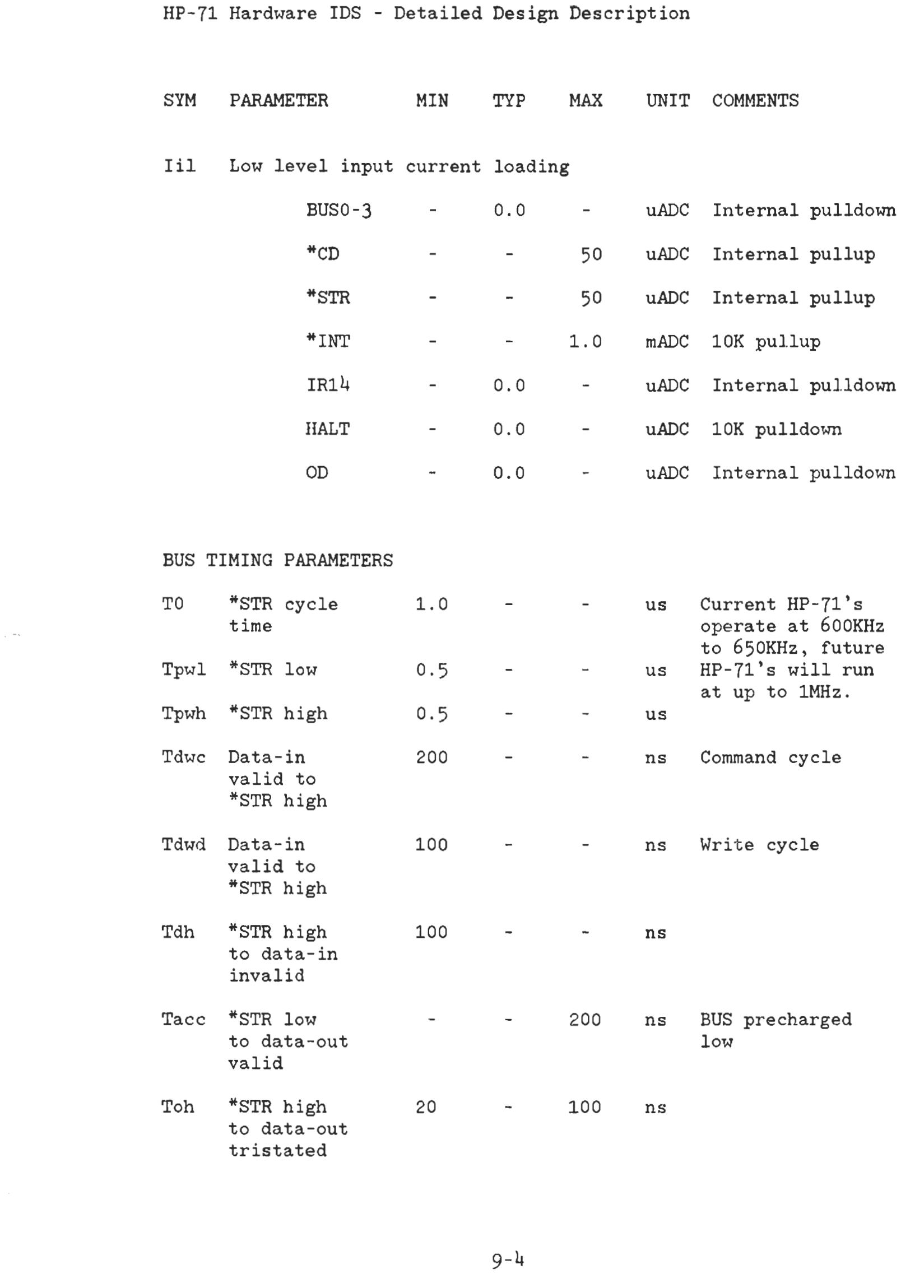
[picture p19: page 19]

Hardware IDS - Detailed Des | ion
SYM | PARAMETER | MIN | TYP | MAX | UNIT COMMENTS
Iil | Low level | current
| BUSO | | 0.0 | | uADC Internal
| | | | | uADC Internal
| | | | | uADC Internal
| | | | 1.0 | mADC 10K
| | | 0.0 | | uADC Internal
| HALT | | 0.0 | | uADC 10K
| OD | | 0.0 | | uADC Internal

BUS TIMING PARAMETERS

TO | 1.0 | us | Current HP-
time
, future
low | 0.5 | us | will run
at up to lMHz.
0·5 | us
Tdwc Data-in | 200 | ns | Command
valid to
Tdwd Data-in | 100 | ns | Write
valid to
h
Tdh | h | 100 | ns
to data-in
invalid
Tacc | low | 200 | ns | BUS
to data-out | low
valid
Toh | h | 20 | 100 | ns
to data-out
tristated

4

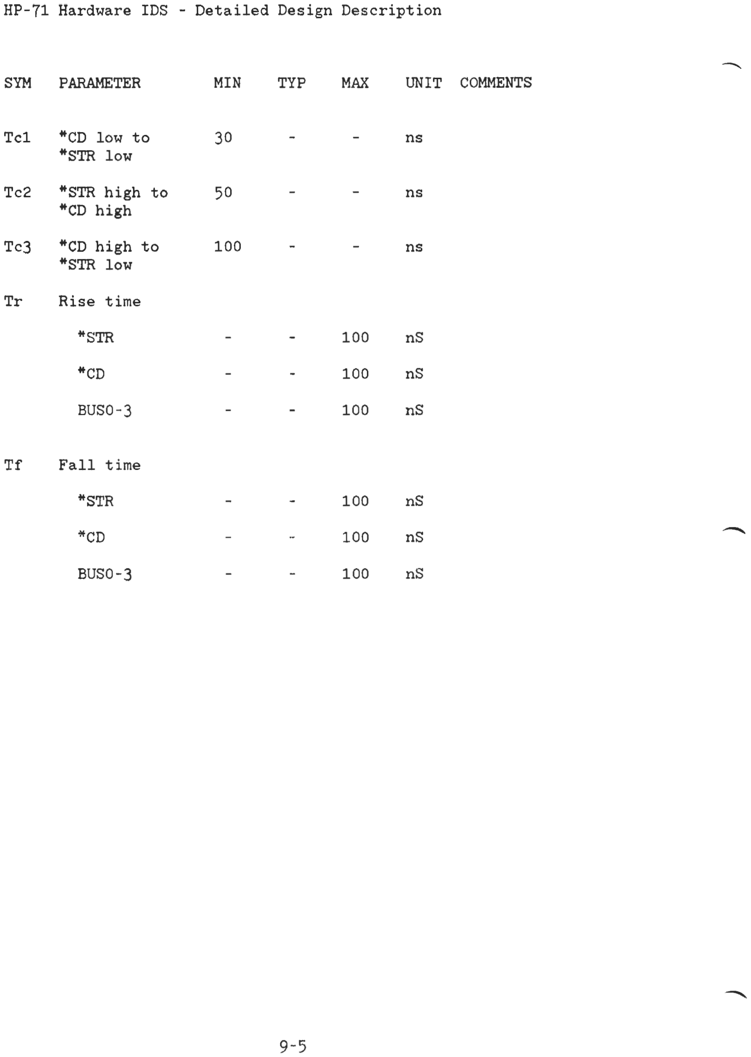
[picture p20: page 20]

Hardware IDS - Deta | Des | Des
SYM | PARAMETER | MIN | TYP | MAX | UNIT COMMENTS
Tel | low to | | | | ns
| low
Te2 | to | ns
to | 100 | ns
Tr | Rise time
| | | | 100 | nS
| | | | 100 | nS
| BUSO-3 | | | 100 | nS
Tf | Fall time
| | | | 100 | nS
| | | | 100 | nS
| BUSO | | | 100 | nS

9 5

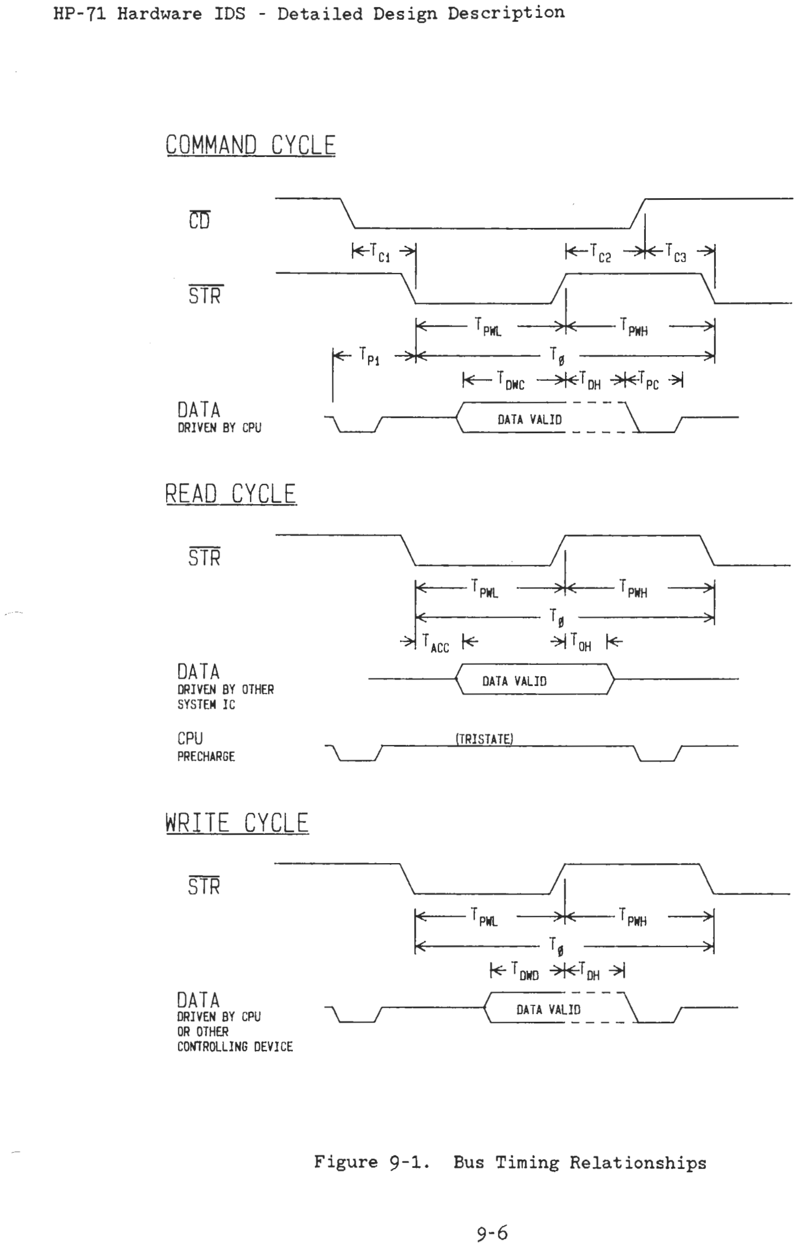
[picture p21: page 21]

HP- Hardware IDS - Detailed Des

DRIVEN BY CPU

DRIVEN BY OTHER
SYSTEI4 Ie
CPU
PRE CHARGE

DRIVEN BY CPU
DR OTHER
CONTROLLING DEVICE

F

ion

Bus | Relat

6

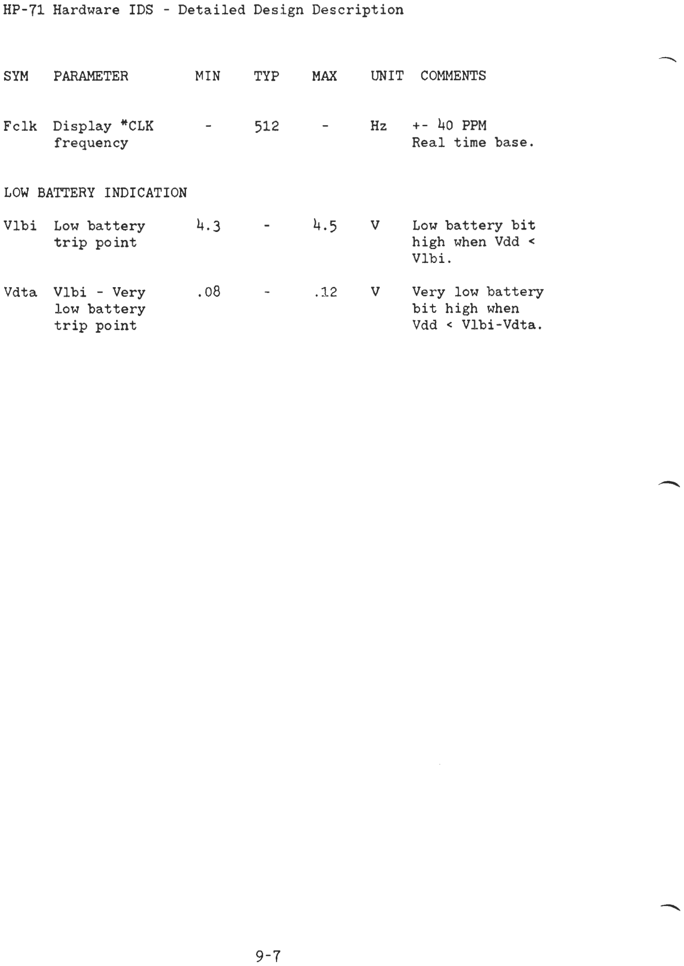
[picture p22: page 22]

Hardware IDS - Detailed Des | Des
SYM | PARAMETER | MIN | TYP | MAX | UNIT COMMENTS
Fclk | Hz | + | PPM
Real time base.

LOW BATTERY INDICATION
Vlbi Low | 4.3 | 4·5 | V | Low | bit
point | when Vdd <
VlbL
Vdta Vlbi - | .12 | V
low
point

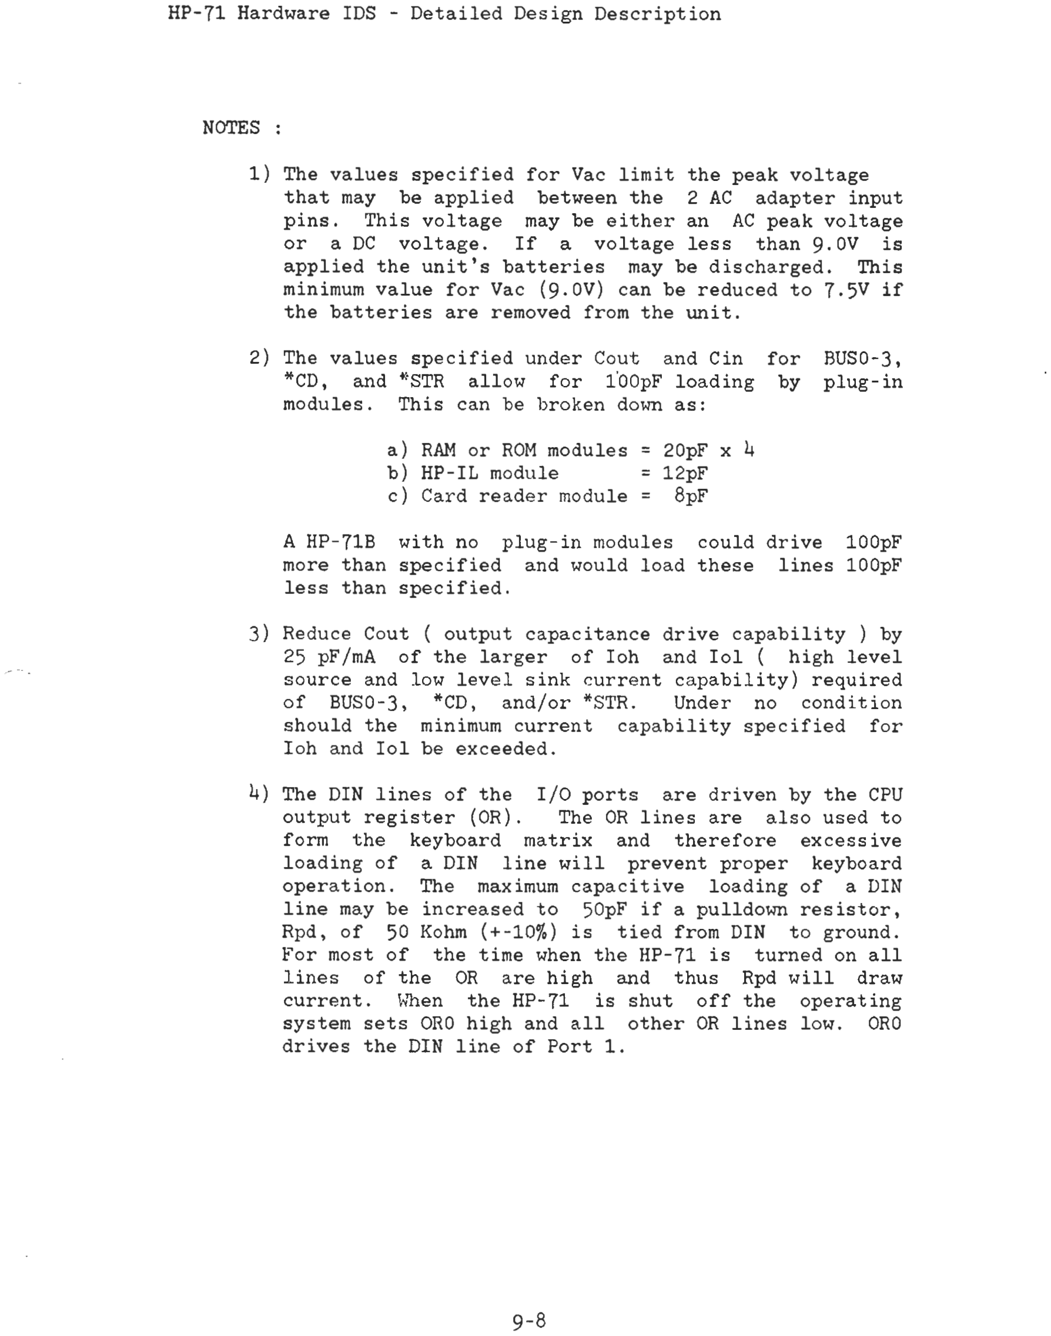
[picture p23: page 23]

Hardware IDS - Detailed Des | ion

NOTES :

1) The values
that may be
This
or a DC

for Vac limit
between the
may be either an
If a | less than 9.0V is
the unit's batteries may be dis minimum value for Vac (9. can be reduced to 7. the batteries are removed from the unit.
2) The values specified under Cout and Cin for
and | allow for
modules. This can be broken down as:
a) RAM or ROM modules | x 4
b) HP-IL module
c) Card reader module
A | with no | in modules could drive
more than specified and would load these lines less than specified.

This
if
3 Reduce | | capacitance drive
of loh and 101 | level
source and low level sink current | 1 | required
of BUS 0 | | | Under no condition
should the minimum current | specified for
loh and 101 be exceeded.
4) The DIN lines of the I | are driven | the CPU
) . The OR lines are also used to and therefore excessive
| of a DIN
The maximum | of a DIN
line may | increased to | resistor,
, of | Kohm (+ | ) is tied | DIN to
For most of the time when the | is turned on all
lines of the OR are | and thus | will draw
current. ~nen | the HP- | is shut off the
system sets ORO | and all other OR lines low. ORO
drives the DIN line of Port 1.

9

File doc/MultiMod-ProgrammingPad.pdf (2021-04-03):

# MultiMod Programming Pad

This document contains a blank summary programming page to plan and document a ROM layout in your MultiMod ROM emulator. Examples are provided to guide your own layout.

The first example is the layout and commands for J-F’s Ultimate ROM. This example illustrates how the ROM structure description consists of different size ROM chips from the HP71B perspective. Each “chip” is the same size as the ROM image it holds, even though it maps to one or more internal 16KB flash blocks.

The second example shows how you can mix chip sizes, as well as create a sequence of 16KB chips to hold a large ROM (64KB C71 ROM in this case). A hard ROM is not needed so the space dedicated to its use can be repurposed to hold other ROMs.

At the end is a blank programming sheet that you can print and fill out for your own layout. The programming sheet consists of three tables. The first table is where you list the ROMs you want your MultiMod to host. You would normally have ROMs that total no more than seven 16KB “chips” but an 8KB ROM can be stored in the top half of flash block 0. It is marked as a 16KB ROM in this and subsequent blocks, even though only 8KB of content can be held.

The second block is the layout of the ROM Enumeration Table as it appears in MultiMod SRAM. Filling this out is somewhat optional, but very useful in visualizing what you are actually presenting to the HP-71B O/S during its startup processing. It also serves as a check on your ROM structure prior to filling out the last two tables.

The last two tables are the serial monitor commands that you use to define the ROM structure and upload the ROM image data. The commands used are separated into two tables because you can often reuse the same structure to hold different ROM content. For example, replacing one ROM in the Ultimate ROM layout would only require the ERASE command and the IMAGE command to upload the new ROM image.

Naming and keeping a sheet for each ROM layout you create is a helpful reminder of what you have, or what you’d like to recreate. Build your own set of favorite layouts and quickly switch from one to the other using just a few serial monitor commands!

Warning! Failure to use Xon/Xoff flow control will cause serious problems when uploading a ROM image! See below for recovery instructions.

Your 71B should be powered on briefly to wake the MultiMod from sleep before proceeding with making a serial connection. Connect a USB to TTL serial port cable to the J3 serial connector on the MultiMod board. You should connect ground to board ground, receive to board transmit (Tx), and transmit to board receive (Rx). Leave the MCLR pin unconnected. Tap return to get into the monitor.

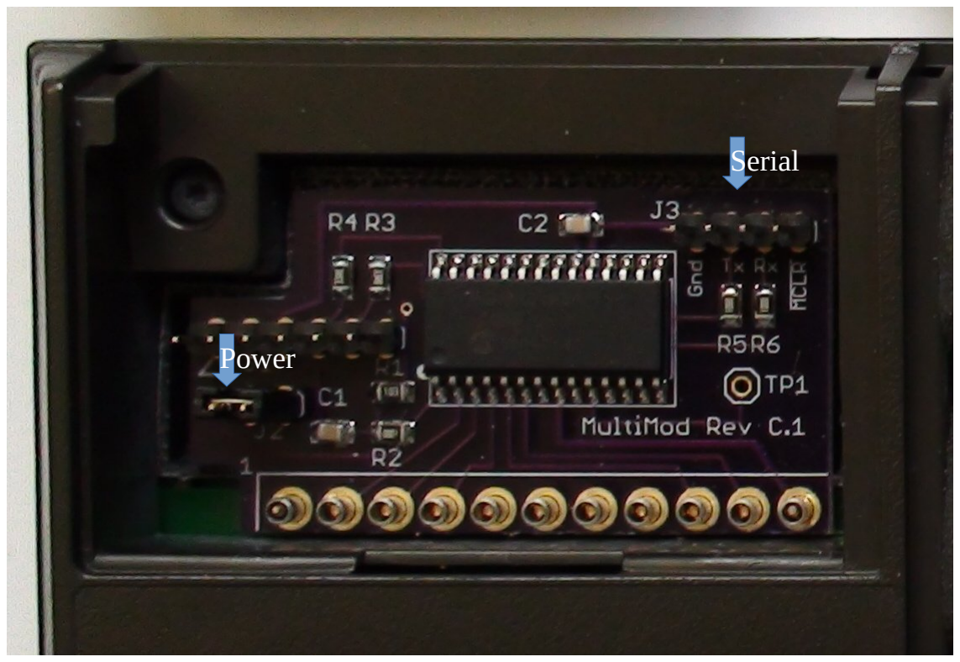
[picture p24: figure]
Serial; Power

Recovery Instructions
Your MultiMod is really a microcontroller system mimicking real ROM hardware. If your MultiMod should fail to respond to the POKE command, try resetting the board. You can do this either by removing the J2 power jumper for 5+ seconds, or by briefly shorting the Gnd and MCLR pins of the J3 serial connector. This is best done while the 71B is off and the bus is quiescent.

The MultiMod will power down into deep sleep mode 2-1/2 minutes after the 71B is turned off. Remember this should you wish to replace the batteries! In deep sleep the MultiMod draws no more current than the 71B, so you can safely replace batteries (quickly, or one at a time), but don’t do so immediately after turning off the 71B or a Memory Lost will occur.

Terminal Emulator Settings
19200 baud
8 data bits, no parity, 1 stop bit (8N1) Xon/Xoff software flow control protocol

MultiMod Programming Pad

Name: J-F’s Ultimate ROM using variable-sized chips

Content:
ROM Image File | ROM Size | # of 16KB Chips
HP-82478A_FORTH-ASSEMBLER_ROM.BIN | 16KB | 1
HP-82478A_FORTH-ASSEMBLER_HRD-FIX.BIN | 32KB | 2
MATH2B.BIN | 32KB | 2
JPCF05.BIN | 32KB | 2
ULIB52.BIN | 8KB | 1

Table Layout
ROM Image Filename | Size | Resv | Type | Class | Last | Flag | Addr | Chip | Line | Field | Data | Desc
forth1b.dat | 0x0a | 0x00 | 0x01 | 0x00 | 0x08 | 0 | 0x00 | 1 | 1 | Size | 0x0A | 16KB
math2b.dat | 0x09 | 0x00 | 0x01 | 0x00 | 0x08 | 0 | 0x00 | 2 | 2 | | 0x09 | 32KB
jpcf05.dat | 0x09 | 0x00 | 0x01 | 0x00 | 0x08 | 0 | 0x00 | 4 | 3 | | 0x08 | 64KB
ulib52.dat | 0x0a | 0x00 | 0x01 | 0x00 | 0x08 | 1 | 0x00 | 0 | 4 | Last | 0x00 | No
empty | 0x0a | 0x00 | 0x01 | 0x00 | 0x08 | 0 | 0x00 | 5 | 5 | | 0x08 | Yes
forth1bhrd.dat | 0x0a | 0x00 | 0x01 | 0x00 | 0x08 | 2 | 0x00 | 6 | 6 | Flag | 0x00 | Cont.
forth1bhrd.dat | 0x0a | 0x00 | 0x01 | 0x00 | 0x08 | 2 | 0x00 | 7 | 7 | | 0x01 | Stop
MMIO Address | 0x00 | 0x00 | 0x00 | 0x0C | 0x02 | 0x00 | 0x00 | 0x00 | 8 | | 0x02 | H-Rom
Command | Display | Content | ROM Structure Commands | Command | Display
R | 1 | 1 | 1 | ROM 1 16K 1 | forth1b | L | 4 | Last 4
R | 2 | 3 | 2 | ROM 1 32K 2 | math2b | H | Y | Hard Yes
R | 3 | 3 | 4 | ROM 1 32K 4 | jpcf05
R | 4 | 1 | 0 | ROM 1 16K 0 | ulib52
R
R
R
Command | Display | ROM Content Commands | Command | Display | File Upload
E | 0 | Erase 0 | I | 0 | IMAGE 0 | ulib52.dat
E | 1 | Erase 1 | I | 1 | IMAGE 1 | forth1b.dat
E | 2 | Erase 2 | I | 2 | IMAGE 2 | math2b.dat
E | 3 | Erase 3 | I | 4 | IMAGE 4 | jpcf05.dat
E | 4 | Erase 4 | I | 6 | IMAGE 6 | forth1bhrd.dat
E | 5 | Erase 5 | I
E | 6 | Erase 6 | I
E | 7 | Erase 7 | I

MultiMod Programming Pad

Name: Example using a multi-chip sequence, no hard ROM

Content:
ROM Image File | ROM Size | # of 16KB Chips
MATH2B.BIN | 32KB | 2
HP-82485A_TEXT-EDITOR_ROM.BIN | 16KB | 1
C71.BIN | 64KB | 4
ULIB52.BIN | 8KB | 1

Table Layout
ROM Image Filename | Size | Resv | Type | Class | Last | Flag | Addr | Chip | Line | Field | Data | Desc
math2b.dat | 0x09 | 0x00 | 0x01 | 0x00 | 0x08 | 0 | 0x00 | 1 | 1 | Size | 0x0A | 16KB
text-edit.dat | 0x0a | 0x00 | 0x01 | 0x00 | 0x08 | 0 | 0x00 | 3 | 2 | | 0x09 | 32KB
c71.dat | 0x0a | 0x00 | 0x01 | 0x00 | 0x00 | 0 | 0x00 | 4 | 3 | | 0x08 | 64KB
c71.dat | 0x0a | 0x00 | 0x01 | 0x00 | 0x00 | 0 | 0x00 | 5 | 4 | Last | 0x00 | No
c71.dat | 0x0a | 0x00 | 0x01 | 0x00 | 0x00 | 0 | 0x00 | 6 | 5 | | 0x08 | Yes
c71.dat | 0x0a | 0x00 | 0x01 | 0x00 | 0x08 | 0 | 0x00 | 7 | 6 | Flag | 0x00 | Cont.
ulib52.dat | 0x0a | 0x00 | 0x01 | 0x00 | 0x08 | 1 | 0x00 | 0 | 7 | | 0x01 | Stop
MMIO Address | 0x00 | 0x00 | 0x00 | 0x0C | 0x02 | 0x00 | 0x00 | 0x00 | 8 | | 0x02 | H-Rom
Command | Display | Content | ROM Structure Commands | Command | Display
R | 1 | 3 | 1 | ROM 1 32K 2 | math2b | L | 7 | Last 7
R | 2 | 1 | 2 | ROM 2 16K 2 | text-edit | H | n | Hard No
R | 3 | c | 4 | ROM 3 CHIP 4 | c71
R | 4 | c | 5 | ROM 4 CHIP 5 | c71
R | 5 | c | 6 | ROM 5 CHIP 6 | c71
R | 6 | 1 | 7 | ROM 6 16K 7 | c71
R | 7 | 1 | 0 | ROM 7 16K 0 | ulib52
Command | Display | ROM Content Commands | Command | Display | File Upload
E | 0 | Erase 0 | I | 0 | IMAGE 0 | ulib52.dat
E | 1 | Erase 1 | I | 1 | IMAGE 1 | math2b.dat
E | 2 | Erase 2 | I | 2 | IMAGE 3 | text-edit.dat
E | 3 | Erase 3 | I | 4 | IMAGE 4 | c71.dat
E | 4 | Erase 4 | I
E | 5 | Erase 5 | I
E | 6 | Erase 6 | I
E | 7 | Erase 7 | I

MultiMod Programming Pad

Name:

Content:
ROM Image File | ROM Size | # of 16KB Chips

Table Layout
ROM Image Filename | Size | Resv | Type | Class | Last | Flag | Addr | Chip | Line | Field | Data | Desc
| | 0x00 | 0x01 | 0x00 | | | 0x00 | | 1 | Size | 0x0A | 16KB
| | 0x00 | 0x01 | 0x00 | | | 0x00 | | 2 | | 0x09 | 32KB
| | 0x00 | 0x01 | 0x00 | | | 0x00 | | 3 | | 0x08 | 64KB
| | 0x00 | 0x01 | 0x00 | | | 0x00 | | 4 | Last | 0x00 | No
| | 0x00 | 0x01 | 0x00 | | | 0x00 | | 5 | | 0x08 | Yes
| | 0x00 | 0x01 | 0x00 | | | 0x00 | | 6 | Flag | 0x00 | Cont.
| | 0x00 | 0x01 | 0x00 | | | 0x00 | | 7 | | 0x01 | Stop
MMIO Address | 0x00 | 0x00 | 0x00 | 0x0C | 0x02 | 0x00 | 0x00 | 0x00 | 8 | | 0x02 | H-Rom
Command | Display | Content | ROM Structure Commands | Command | Display
R | L
R | H
R
R
R
R
R
Command | Display | ROM Content Commands | Command | Display | File Upload
E | Erase | I | IMAGE
E | Erase | I | IMAGE
E | Erase | I | IMAGE
E | Erase | I | IMAGE
E | Erase | I | IMAGE
E | Erase | I
E | Erase | I
E | Erase | I

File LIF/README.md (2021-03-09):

HP71MultiMod Repository

# A ROM Emulator Board for the HP-71B
Various LIF files associated with the MultiMod emulator will be kept
here in this directory.

For a large selection of LIF files created for the HP-71B, be sure to
visit the sites maintained by Joe Horn.

http://holyjoe.net/HP71/index.htm (HP-71B Goodies)

http://holyjoe.net/HP71/TitanFileCompleteCollection.pdf

http://hhuc.us/2014/files/Speakers/08,09%20Joseph%20Horn/Online%20LIF%20Disk%20Project/

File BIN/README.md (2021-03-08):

HP71MultiMod Repository

# A ROM Emulator Board for the HP-71B
Some of the best .BIN ROM images can be found at J-F Garnier's web site

http://http://www.jeffcalc.hp41.eu/index.html

Here you will find the PPC-Paris User Club JPC ROM he maintains. You can
also find his enhanced and extended version of the HP Math Pac ROM. On
the page that documents his DOS-based emu71 emulator program you will also
find other ROMs, such as ULIB52, Symbolix, and Soft Forth with the C71
RPN calculator emulator.

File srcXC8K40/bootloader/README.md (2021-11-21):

HP71MultiMod Repository

# A ROM Emulator Board for the HP-71B
**23-October-2021**
Source files for the MultiMod board bootloader. These files
are compiled, linked, and loaded with XC8 v2.32 in MicroChip MPLAB X IDE v5.45.
MPLAB X and XC8 can be obtained from Microchip.com in their development tools repository.

This bootloader was generated by the MCC tool and is a C implementation of the
AN851 bootloader. The bootloader protocol is simpler than that of the AN1310
bootloader used with the original MPASM-based version of the MultiMod code in
the src directory.

# Build Instructions
First create a standalone application project with the suggested name of
BootLoaderK40. Copy the main.c file from the bootloader subdirectory to the base
directory of the project. Copy all other files to the mcc_generated_files
subdirectory. Be sure to specify the target processor as PIC18F27K40, set the
optimization level to minimize space, then build the project.

The .hex file needed by the MultiMod application project can be found
in the dist/default/production subdirectory.

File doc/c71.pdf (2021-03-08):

### What C71 Does

Section 1

### Getting Started

The C71 module contains a program called C71 that allows your HP-71 to act like a Hewlett-Packard Series 10 calculator. C71 simulates many of the functions found on the HP-11C (Scientific Calculator), the HP-12C (Financial Calculator), the HP-16C (Computer Scientist), and the HP-15C (Advanced Scientific Calculator). With just a few key strokes you can switch from Basic into the calculator and easily enter your calculations.

### Installing and Removing the C71 Calculator Module

The C71 Calculator module can be plugged into any of the four ports on the front of the computer.

### ***************************** CAUTION *******************************

* Do not place fingers, tools, or other foreign objects into any of the ports. Damage to plug-in module contacts and computer's internal circuitry may result. Such actions could result in minor electrical shock hazard and interference with pacemaker devices worn by some people.
* Be sure to tum off the HP-71 (press Cfi[OFFJ) before installing or removing a plug-in module.
* If a module jams when inserted into a pon, it may be upside down. Attempting to force it funher may result in damage to the computer or the module.
* Handle the plug-in modules very carefully while they are out of the computer. Do not insen any objects in the module connector socket. Always keep a blank module in the computer pon when a module is not installed. Failure to observe these cautions may result in damage to the module or the computer.
************************************************************************

To insen the module, orient it so that the label is right-side up, hold the computer with the keyboard facing up and push in the module until it snaps into place. Be sure to observe the precautions described above.

To remove the module, grasp the lip on the bottom of the front edge of the module and pull the module straight out of the pon. Install a blank module in the pon to protect the contacts.

### Starting C71

To enter the calculator type:

C71 [END LINE]

Section 1: Getting Started

the display will clear and then a number and the mode will be displayed. The number will be the value that was displayed the last time you used C71or0 if this is the first time you have used C71.

### Leaving C71

There are two methods for leaving C71: [fl[OFFl and [glfEXITl

Turning the HP-71 Off

Pressing [f]fOFFl will turn the HP-71 off, but will leave the calculator active. The next time ON is pressed, C71 will be reactivated and you will be working in the calculator again. The calculators status is saved prior to turning off and restored upon turning back on. However, if something should happen so the calculator does not come back on, because the status was saved, typing C71 [END LINE] will restart the calculator just where you left it. For more information on the interaction between the calculator and the HP-71 BASIC refer to Appendix D: HP-71 System Usage.
Returning to BASIC

Pressing [gUEXITl will store the current status of C71 and return control of the HP-71 to the BASIC operating system. Pressing C71 [END LINE] will restart the calculator just where you left it.

### Display

Mode

C71 has two basic modes of operation which coincide with the two overlays provided for the keyboard. The first mode is Engineering/ Business mode. When C71 is in this mode an :F will be displayed on the right side of the display. This mode uses floating point numbers. Most operations such as financial, trigonometric, and engineering calculations are done in this mode. In this mode many of the functions found on the HP-11C, HP-12C and HP-15C calculators are simulated.

The second mode of operation is the Computer Scientist mode which simulates many of the functions found on the HP-16C. C71 signifies this mode by displaying a :H, :0, :D, or :Bon the right hand side of the display. These letters signify the various number base formats (hexadecimal, octal, decimal, and binary respectively) available in the Computer Scientist mode. Computer Scientist mode operates only on integers. Refer to the "Number Base Modes" in section 10 for further information.

To switch between modes press [flfRUNl. The display will switch between the :F and :H, :0, :D, or :B to signify which mode the software is in.

While in Engineering/Business mode, you can choose a format in which to display the numbers. They are standard, fixed, scientific and engineering formats. Refer to section 3, Display Control, for further information.
Flags and Annunciators

Your HP-71B display contains five flags (0 through 4) on the right hand side and several annunciators on both the right and the left hand side. These flags and annunciators tell you the

Section 1: Getting Started

status of the computer during certain operations. They are described, with the operations they refer to, in the appropriate sections of this manual.

Negative Numbers

Flag

0
1
2
3
4

Definition

Begin mode (Finance)
M.DY mode (Calendar)
Leading zeros (Computer Scientist) Carry (Computer Scientist) Out-of-Range (Computer Scientist)

To make a displayed number negative--either one that has just been keyed in or one that has resulted from a calculation--simply press CCHSJ (change sign). When the display shows a negative number--that is, the number is preceded by a minus sign--pressing [CHS] removes the minus sign from the display, making the number positive.
Display Clearing: [CLRx] and [ <]

C71 has two types of display clearing operations, [CLRx] (clear X) and .G;l (back arrow). When [CLRx] is pressed, any displayed number is cleared to zero.

Pressing .G;l after executing almost any function clears all digits in the display to zero.

Keystrokes

12
[f][l/x]
[<]

Display
12
.0833
.0000

:F
:F
| | :F | Pressing [ <] after
| | | executing a function clears
| | | all digits in the display
| | | to zero.

After keying in a new number, if you press .G;l before executing a function (that is, before terminating digit entry) the last digit you keyed in is deleted. After you delete one or more digits, you can, if you want, key in new digits to replace them.

Keystrokes | Display
12345 | 12345 | :F
[<] | 1234 | :F
[<] | 123 | :F | When digit entry has not
| | | been terminated, [ <] acts
| | | on each digit separately.
9 | 1239 | :F

Scrolling

In Engineering/Business mode the display does not scroll. The display may be scrolled in Computer Scientist mode. For further information on scrolling in Computer Scientist mode refer to section 10.

Section 1: Getting Started

Overflow and Underflow

C71 uses the HP-71 's operating system and therefore has the same overflow and underflow conditions as the BASIC system does. The way C71 handles an overflow or underflow depends on the DEF AULT settings of the IEEE traps. On a Memory Lost or initial power on condition the HP-71 sets DEFAULT ON. With DEFAULT ON overflows are set to the maximum magnitude value of the machine: 9.99999999999E499. On underflow it defaults to 0. Whenever an overflow or underflow occurs the calculator will beep (unless the beep has been disabled while in the BASIC system). For more information on the behavior of the HP-71 with other DEFAULT settings, on the HP-71 's IEEE math handling, and on the HP-71 's numerical range, refer to section 2 of the HP-71 Owner's manual and to "The IEEE Proposal for Handling Math Exceptions" in the HP-71 Reference manual.

Working

When C71 is calculating a result that takes several seconds, the display will show or flash:

Working •••

to let you know that it is working on your calculation. The functions that will display
Working ... are fil, CIRRl, CBFPl, and CBXJ.

Low Battery Indicator

A low power condition is indicated by the·BA TT annunciator in the upper left hand side of the display. When BA TT is lit, new batteries should be installed. Refer to your HP-71 Owner's Manual for information on replacing the batteries.

Error Messages

If you attempt a calculation using an improper parameter, such as attempting to find the square root of a negative number, an error message will appear in the display.

Keystrokes

4[CHS]
["7x]
[<]

Display

-4
ERR:SQR(NEG)
-4.0000

:F
:F
:F

For a complete listing of error messages and their cause, refer to Appendix A, Error Messages. To clear any error message, press Isl (or any other key), then resume normal operation.

### Memory

Continuous Memory

The Continuous Memory feature of your computer maintains the following even when the computer is turned off and when you exit C71:
* All numeric data stored in C71.

* The display mode and setting.

Section 1: Getting Started

* Flag settings.

* Trig mode (Degree or Radians).

* Calculator mode (Engineering/Business or Computer Scientist).

BASIC System Files

C71 creates two files in your HP-71 RAM:
* FORTHSYS. C71 uses a special variation of the HP-71 FORTH/Assembler ROM for some of its software. FORTHSYS is required by the FORTH system for its storage. Also the X-, Y-, Z-, T-, and LAST X registers are maintained in this file. This file is used by all special ROMFORTH applications. This file requires about 1100 bytes.
* C71RAM is also created by the FORTH system, however its use is exclusive to the C71 software. This is where all C71 related variables and storage registers are maintained. This file requires about 640 bytes.

There are 3 special classes of storage registers maintained in C71RAM:

1. User storage registers Ro through R9.
2. Financial registers n, i, PV, PMT, and FV.
3. Cash flow registers CFo through CF20 and the cash flow group registers No through N20·

Additionally, C71 uses the HP-71 's internal statistical functions and internally maintained statistical arrays. The HP-71 's BASIC system allocates memory for these as required.

You must have about 1800 bytes of free memory as shown by the MEM function in order for C71 to run.
Resetting Memory

Initially, C71 has a set of default values which it saves in C71RAM. If you wish to reset these default values to their original state, type the following:
PURGE C71RAM

while in the BASIC system of the HP-71.

### Keyboard Operation

Overlays

Two overlays are provided with the C71 Calculator pac. The first is the General Functions overlay and the second is the Computer Scientist overlay. These overlays tell you where the C71 functions are available for the C71 Calculator.

Section 1: Getting Started

Primary and Alternative Functions

Most keys on your HP-71B perform one primary and two alternate functions. With C71 two overlays have been provided, because many of the keys have been reassigned to different functions other than the standard HP-71B keyboard functions. The primary function of any key is indicated by the character on the left of the key. It is written in a vertical fashion. If no characters appear to the left of the key, the primary key is what is on the face of the key (for example: 0 through 9 and/,*,-,+). The two alternate functions are indicated by characters above the face of the key.

To select the alternate function printed in gold above the key on the left, first press the gold prefix key ffi, then press the function key; for example (flfBEGl.

To select the alternate function printed in blue above the key on the right, first press the blue prefix key f&l, then press the function key; for example [~][END].

To select the primary function on the face of the key, press only that key, for example: [%].

Clearing Keys

Clear Stack. CCLR STKl clears automatic memory math registers: X, Y, Z, T, and LX.

Clear Registers. CCLR REG] clears the user storage registers Ro through R9.

Clear Financial Registers. CCLR FIN] clears the financial registers: n, i, PV, PMT, FV, CFo through CF20. and No through N10.

Clear Statistics. CCLR ST AT] clears the HP-71 's internally maintained statistical array. <::71 uses the HP-71 's statistical functions and memory arrays.

Clear Prefix. If you make a mistake while keying in a prefix for a function, press the prefix key again to cancel the error.

Apl'endix D

### HP-71 System Usage

This section details the amount of memory required, file names used, variables used, and other technical aspects of C71 's interaction with the HP-71.

### File Names and Memory Usage

The following files are created and used by C71:

File

FORTHSYS
C71RAM
C71FILE

Type

FORTH
FORTH
DATA

Size
1102
640
1292

Used For:

Soft-FORTH system RAM file. C71 Calculator RAM file.
Data file for register exchange with BASIC files from the function ffiXl.

If any files exist in your HP-71 with those names prior to running C71, it will cause unexpected operations. If another file with the name of either of the FORTH files (FORTHSYS or C71RAM) exist, the calculator will give an Invalid File Type error message. If a file named C71FILE exists prior to pressing CBXJ, a File Exists error message will be displayed.

The HP-71 must have enough memory to accommodate FORTHSYS and C71RAM before the calculator can be entered. C71 creates these two files when you first press C71 CEND LINE]. If you never use the CBXJ function, then you do not need memory for C71FILE. C71FILE is created when CBXJ is pressed, and purged by the calculator when the function completes.

As there is some system overhead required to create files, your HP-71 will need a few bytes more than the actual size of the files.

### Variables Used by C71

C71 uses several HP-71 BASIC variables in conjunction with the statistics functions and with CBXJ. The following is a list of the variables and what they are used for.

Statistics:

R7(2) | The statistics array variable, declared using the BASIC STAT command.
RS | Used to get the slope from the BASIC LR function.
R9 | Used to get the intercept from the BASIC LR function.

Appendix D: HP-71 System Usage

fBXl:

R9$[68]

R9

Used to read the string representations of registers from the C71FILE.

Used to read certain HP-AF file format information from the C71FILE.

### Additional Technical Information

Overview

C7 l is based on an interaction of three systems. First, it uses the HP-71 operating system to control all file handling, number control for floating point numbers, statistics, and many of the mathematical operations. Second, it uses an alternative operating system called Soft-FORTH, which is designed to co-exist with the HP-71 native BASIC operating system. Soft-FORTH is a special ROM version of the HP-71 FORTH/ Assembler ROM. This version is designed to be put into application ROMs, and allows multiple Soft-FORTH applications to be present in the HP-
71. Third, the actual calculator--C71--is written in a combination of FORTH and assembly code (FORTH primitives).

The Soft-FORTH uses the FORTHSYS file as its allocated, dedicated RAM area. While C71 uses C71RAM as its allocated, dedicated RAM area. If multiple Soft-FORTH applications are present in your HP-71, they will all use FORTHSYS while they are running. However, only C71 uses C71RAM. Your other Soft-FORTH applications will have their own dedicated RAM areas.

FORTHSYS maintains the FORTH stacks, pointers, and the X-, Y-, Z-, T-, and LAST X
registers. | ·

C71RAM maintains the storage registers, financial registers, internally-used working registers, and some special mainframe-save variables. In order to operate properly, C71 must over-write certain mainframe operating status information. This status information is saved in C71RAM upon entry into the calculator, and restored upon exit. Additional information on what is saved and potential problems are discussed below.

Display Delay

Upon entry, C71 stores the mainframe's delay setting and then sets the delay to DELAY 0,0. When a function is performed that goes into the basic interpreter, the machine's original delay setting is restored. If anything is displayed while in BASIC, the display delay and scrolling set in the BASIC system will be used. The two functions that provide an interface to BASIC are fBXl and [BFPJ.

Statistics and BASIC Variables

While in the BASIC system's main environment, whether you're in £BFPJ, £BXJ, or exited from the calculator, if you do a DESTROY ALL or DESTROY R7, you will have destroyed your statistics array and will get an Invalid stat array error message next time you press a statistic function key, like IL±!. You solve this by pressing the [CLR STAT] key. The statistics will then work just fine. The only statistic function this does not apply to is the [CLR ST ATJ function.
R7 needs to be preserved to maintain a valid stat array entered with the IL±! and IL:l keys from within the calculator. R9$, R9, and R8 are temporary variables that are a don't care on entry.

Any previous value will be lost upon using the above functions, so don't rely on them outside of the calculator.
Purging System Files

Purging the system files while exited from the calculator will cause no problem with the operation of the calculator. However, when the calculator is re-entered, the calculator will be set to its default values.
Purging C71RAM will cause the calculator to re-initialize the stat array the next time the II.±1 key is pressed. The other stat functions may work OK because the stat array is kept by the mainframe and not in C71RAM. I.I.±1 sets a flag in C71RAM when it has created a valid stat array in the mainframe. If C71RAM is purged, the calculator has no way of knowing if there is a valid array or not. So it creates a new array and sets the stat valid flag. CLRST AT clears the stat valid flag.

A copy of the X-, Y-, Z-, T-, and LAST X register are kept in C71RAM when the calculator is exited. So there should be no change in the previous values or status of the calculator if FORTHSYS is purged. FORTHSYS is used only during the actual running of the calculator and not for value storage.

If C71RAM is purged while in CBXJ or CBFPJ, the HP-71 will perform a Memory Lost. The Soft-FORTH system is not able to recreate the file and begin running again. The flags the tell the Soft-FORTH system that it is active and in the middle of the rnxI or CBFPJ routines (the FORTH pointers) are maintained in the FORTHSYS file. However, all of the calculator's status information is maintained in C71RAM, where it was saved prior to executing CBXJ or CBFPJ. So the Soft-FORTH system has no way of recovering the proper operation of the calculator as it tries to reestablish its pointers and begin running again. It gets pointed off into some unknown part of memory and ends up causing a Memory Lost.

If FORTHSYS is purged while in CBXJ or CBFPJ, the Soft-FORTH system will have no way of knowing that it was active. When the mainframe polls to reenter Soft-FORTH, Soft-FORTH will just return leaving the system in BASIC, otherwise undamaged. The Radians setting may be different, however, all of the other BASIC system setting will be properly restored. Refer to the section on the BASIC interface for additional information on the Radians setting.
Display Contrast

The display contrast is constantly being altered. Upon entry into C71, your contrast setting is read and stored. As the calculator operates, you will notice the display being blanked at times. This is done by setting the contrast to 0 and then restoring it. If something really gets fouled up and you can no longer see the display, do an INITl to reset the system to get the display back, purge FORTHSYS and C71RAM, then re-set the display contrast to where you like it. INITl while in the calculator will reset the system back to BASIC. Some of your other system settings may no longer be as you like them as you were returned to BASIC before C71 could restore your BASIC system. Such things as your delay setting, your IEEE defaults, and your display mode may need to be reset.
C71 System Modes

The calculator maintains a separate display mode (fix, sci, ... ) and a separate radians-degrees mode from that of the BASIC system. If you are set to radians mode and fix 2 in the calculator, your BASIC system can be set to degrees and STD. The calculator will keep these separated by saving and restoring them at the proper times.

The one mode that is most likely to get mixed is the radians-degrees mode as the calculator's radians/degrees setting is maintained for CBXl and CBFPl calculations. This is done so you won't have to convert units. Every effort is used to maintain the separate status of these when entering and exiting the calculator. However, if an error occurs such that the calculator cannot recover and you're left in BASIC, then the calculator's mode will be in effect in your BASIC system.
Mainframe State Usage

The calculator tries to use your machine states as much as is reasonable. However some need to be altered for the proper running of the calculator, like the delay setting.

The following settings are modified and maintained separately by the calculator:

Function

Display Delay
Display Mode
Display Width
Radians/Degrees
ATTN key

Calculator's Setting

DELAYO,O
User selectable from within C71 WIDTH80
User selectable from within C71 Disabled

The remainder of the mainframe's states are used by C71. For example, if you have set beep off in BASIC, then it will be off in the calculator.

The state of IEEE math traps and defaults are used by the calculator with the following exception. C71 functions that are calculated using FORTH floating point functions force DEFAULT ON and BEEP OFF. Thus if overflows or underflows occur you will not be continuously beeped at as they are occurring. Overflows occurring during a calculation will not accurately reflect whether the final answer would be an overflow or an underflow. Likewise when these calculations are over no warning message will be given that an overflow or underflow occurred. Also if the final result is an overflow or an underflow, that result will not be displayed as INFs and EPS's but will be displayed as the largest or smallest number the HP-71 uses in DEFAULT ON mode. The beeper status will be restored as well as your default status when the calculation is finished.

The IEEE math trap settings are only applicable to Engineering/Business mode, Computer Scientist mode does not allow for this type of traps or exceptions.

The calculator makes use of the system and user flags. All of the flags are stored away before entering the calculator and restored when leaving (including BX, BFP). So your basic machine should always be in the state you had it before entering the calculator. However in the unlikely event that a really obscure error dumps you into the basic without restoring the basic state, you may have to do some clean-up before getting your system back where it should be.

BASIC system status' used by the calculator:

Warning suppress (flag-1)
beep off (flag -2)
continuous on (flag -3)
beep loud (flag -25)
IEEE traps
round off setting (flags -11,-12)
random number seed

If flag -1 is clear and the beep is set to ON (flag -2 is clear), a normal warning will not be displayed, but the HP-71 will beep. For example, with DEFAULT ON, if you do 2CEND LINEJOffi, the calculator will beep and display the overflow result, but will not display the warning message. Whereas, in BASIC 2/0 would display WRN: /ZERO for the delay setting, and then display the overflow result. If you key in a number too large for the calculator (1E+600) and press CEND LINE], with DEFAULT ON, the calculator will beep and display the overflow number, 9.99999999999E499. If you key in a number too large for the calculator (1E+600) and then press a function key that will increase the number (like IXll), the calculator will beep twice--once as it assigns the overflow number and a second time as CX!l overflows.

The following system status' are preserved, but not used by the calculator:

user defined keys
user flags

The following is a list of the functions that are performed using the FORTH floating point functions and thus, force a DEFAULT ON setting:

AMO RT
INT
n
1

->H
->H.MS
H.MS+
H.MS-
PV
PMT | NPV IRR %
| .1% %T ->P
All the complex number functions All the Hyperbolic functions
FV | ->R

C71 Default Settings

When a new C71RAM file and FORTHSYS file are created, the following are the calculator's default status setting when the calculator first starts:

Delay 0,0 (cannot be changed)
Display mode--STD
Engineering/Business mode
End mode (financial)
Degrees mode
Random number seed--same as mainframe's (uses mainframe's routines) X-, Y-, Z-, T-, LAST X registers are clear
Finance registers are clear
Storage registers are clear
Statistics array -- presumed clear (see note above) IEEE Math traps--same as mainframe's

16 bit wordsize
HEX base
carry clear (flag 3)
out-of-range clear (flag 4) Unsigned complement math
Leading zeros not displayed

ATTN Key
The ATTN key on the HP-71 is normally enabled to interrupt a running program. If the ATTN key were to be pressed while in Soft-FORTH, the Soft-FORTH system would terminate and return you to the BASIC system. The ATTN key, however, can be disabled from interrupting a running program. With all of the keystrokes available around the ATTN key it was felt that there would be too great of a chance of accidentally pressing it. If it were allowed to terminate the running of the calculator, the calculator would not have a chance to restore the BASIC system environment and to save its own. Thus, when the calculator is reentered, the status of the calculator would also be different.

For the above reasons, the ATTN key is disabled during the actual calculator and cannot be used to interrupt the program. If a run-away condition (infinite loop) should occur or the calculator gets into a bad state, an INITl will need to be used to recover.

Any time the calculator is returned to the BASIC environment, the ATTN key is restored to its program interruption capability state. The functions that restore this state are: [f][OFFl, fl:UEXITl, ffJIBFPl, and CflfBXJ.

Program Deallocation

When the calculator times out or you press [f]f OFFl, the calculator is turned off with a BASIC programmable BYE after restoring the BASIC environment and saving the calculator's environment. When the CONJ (ATTN) key is pressed to turn the HP-71 back on, the HP-71 will try to continue running the program that was being run prior to the BYE. However, if a plug-in module is put in or removed while the HP-71 is off from a programmable BYE, the HP-71 deallocates the program and will not try to continue running the program.

Thus, if you turn the calculator and the HP-71 off with a [f]fOFFl, and then plug in a module or remove a module, the calculator will not come back on when you press the A TIN key. You will be left in BASIC. However, as the BASIC state was restored and the calculator state saved, pressing C71 will restart the calculator.

If you turn off the HP-71 while at the basic prompt from IBXl or fBFPl by pressing f OFF or allowing the HP-71 to timeout, the program will also deallocate and you'll be left in the BASIC system. A programmable bye in a basic program or a user-defined function does not deallocate the program.

Cautions

Do not copy or purge LEX files from within a user-defined function executed from IBFPl. Soft-FORTH cannot recover properly and a MEMORY LOST is the final result. Usually, an INITl will set things up for a System Error message. Once this message is given an INIT3 is the only resolution. (Refer to section 12 on the BASIC interface for more detail.)

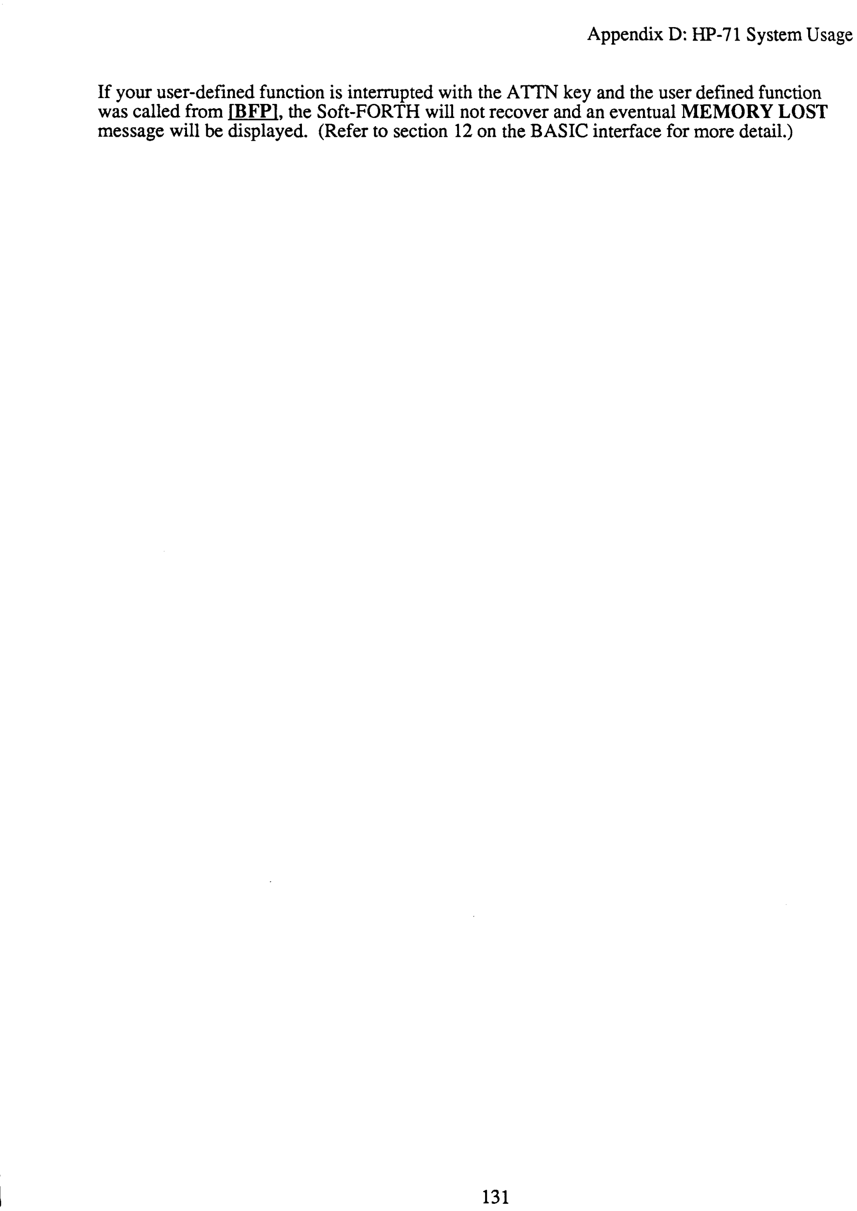
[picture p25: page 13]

If your user-defined function is interrupted with the A TIN key and the user defined function was called from fBFPl, the Soft-FORTH will not recover and an eventual MEMORY LOST message will be displayed. (Refer to section 12 on the BASIC interface for more detail.)

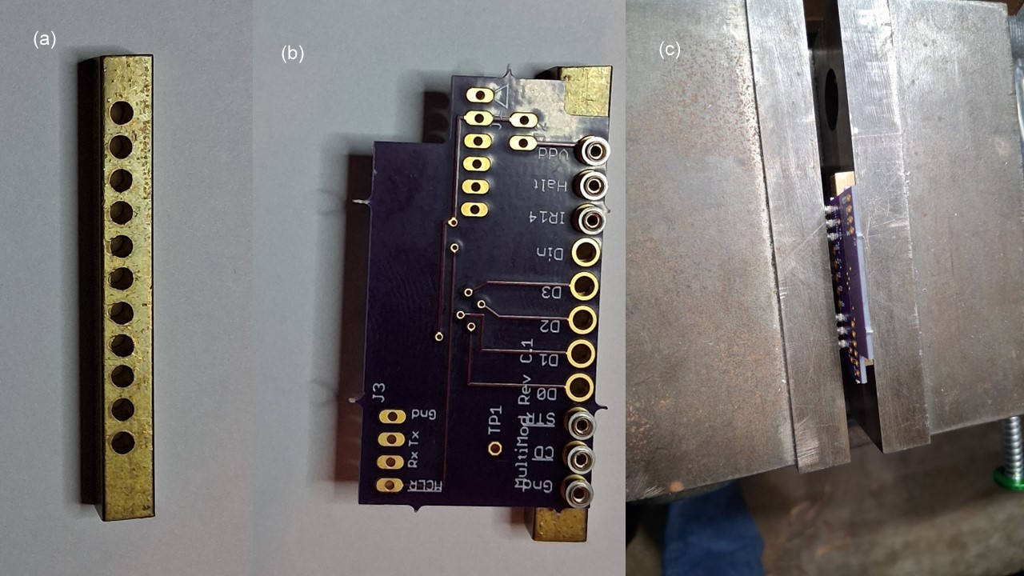
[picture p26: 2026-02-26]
board/Sockets.jpg

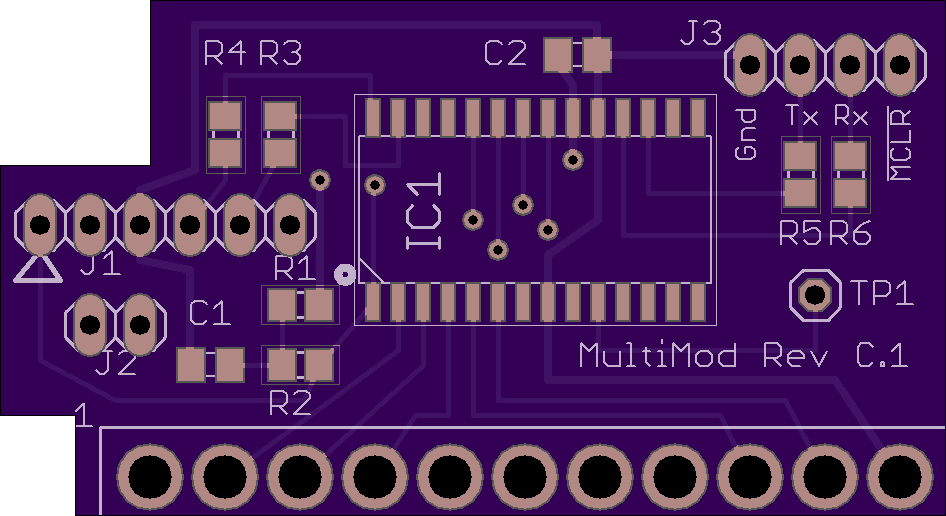
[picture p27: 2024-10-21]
board/front.png

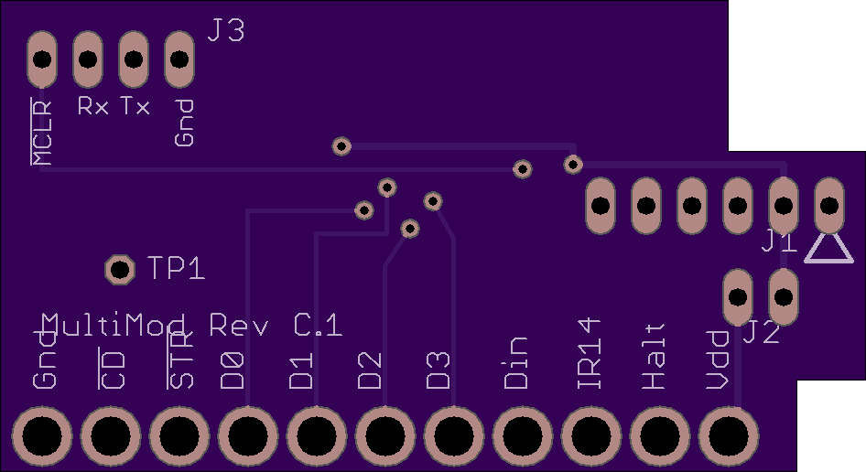
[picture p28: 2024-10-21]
board/back.png

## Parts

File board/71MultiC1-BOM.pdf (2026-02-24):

ID | Part | Package | Mfg # or equivalent | Mfg Description
IC1 | PIC18F27K40-I/SO | SOIC | Microchip PIC18F27K40--I/SO | Microchip MCU
R1 | 10K Ohm | R0805 | Yageo RC0805JR-0710KL | Thick Film Resistors - SMD 10K OHM 5%
R2 | 100 Ohm | R0805 | Yageo RC0805FR-07100RL | Thick Film Resistors - SMD 100 OHM 1%
R3 | 33 Ohm | R0805 | Yageo RC0805FR-1033RL | Thick Film Resistors - SMD 33 OHM 1%
R4 | 33 Ohm | R0805 | Yageo RC0805FR-1033RL | Thick Film Resistors - SMD 33 OHM 1%
R5 | 100 Ohm | R0805 | Yageo RC0805FR-07100RL | Thick Film Resistors - SMD 100 OHM 1%
R6 | 100 Ohm | R0805 | Yageo RC0805FR-07100RL | Thick Film Resistors - SMD 100 OHM 1%
C1 | 0.1 uF | C0805 | Kemet C0805C104K3RACTU | SMD/SMT 25V 0.1uF X7R 0805 10%
C2 | 0.1 uF | C0805 | Kemet C0805C104K3RACTU | SMD/SMT 25V 0.1uF X7R 0805 10%
J1 | Pinheader-6 | | TE Connectivity 826936-6 | Male Header, 0.1" Pitch
J2 | Pinheader-2 | | TE Connectivity 826936-2 | Male Header, 0.1" Pitch
J3 | Pinheader-4 | | TE Connectivity 826936-4 | Male Header, 0.1" Pitch
S1 | PCB Socket (13) | | Harwin H3169-01 | 1 mm PC Board Socket, Tin

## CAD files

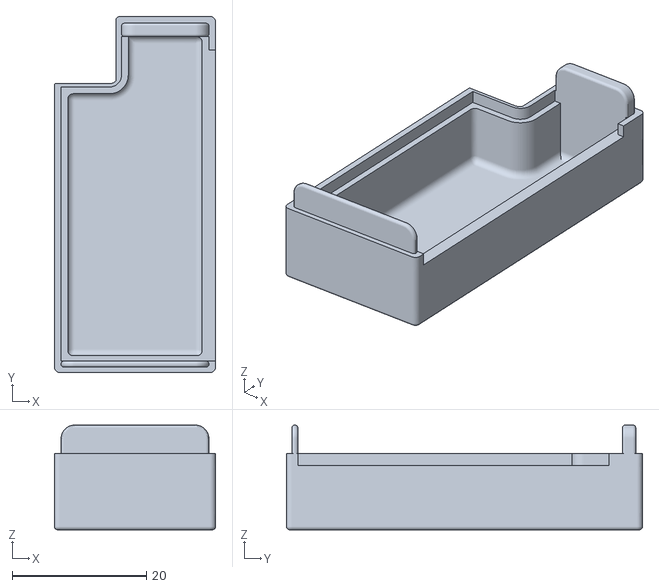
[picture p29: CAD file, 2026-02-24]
board/MM Bottom Half.stl
24.0 x 53.0 x 15.6

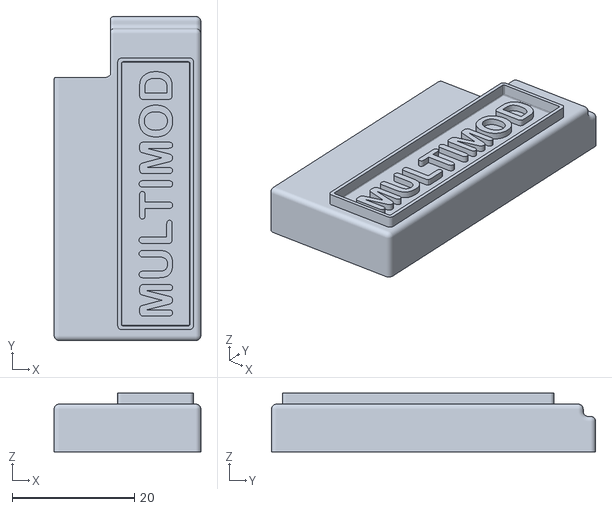
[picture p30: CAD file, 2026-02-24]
board/MM Top Half.stl
24.0 x 53.0 x 9.60

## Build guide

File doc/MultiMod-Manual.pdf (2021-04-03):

Revision: Final Draft | March, 2021

# HP-71B MultiMod ROM Emulator

## User Manual

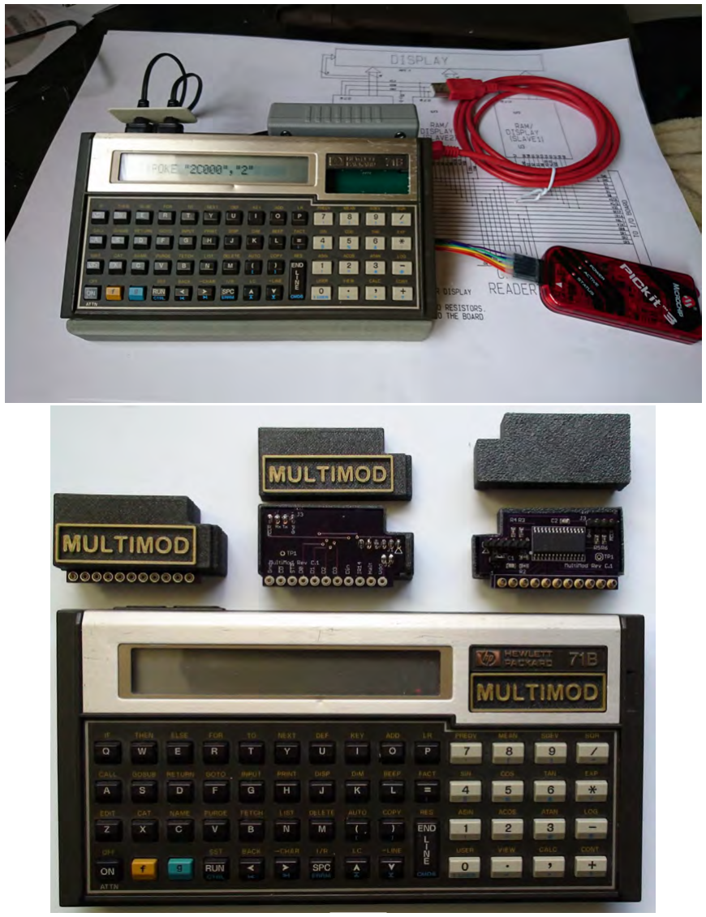
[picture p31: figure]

Every effort has been made to insure the accuracy of the information contained in this document. Descriptions of hardware behavior and operation my be updated from time to time as new software releases become available.

Copyright © 2021, Mark A. Fleming. All rights reserved.

Notice:

“HP-71B” and “HP” are registered trademarks of Hewlett-Packard Inc. or their derivative corporate trademark holder.

Acknowledgments
I wish to thank J-F Garnier, Tony Nixon, and Diego Díaz for their help and advice in making this ROM emulator possible.

## Introduction

The HP-71B MultiMod ROM Emulator gives you the ability to plug in one or more ROM modules on your HP-71B. This is accomplished using a modern microcontroller to emulate the original ROM chip hardware. Using a microcontroller in place of an FPGA hardware implementation allows added programmable functionality that is used to provide a platform-independent means of loading and configuring ROM images. With just a serial connection and suitable terminal emulator like TeraTerm you can quickly add expensive and hard to find ROM modules to your 71B.

## Features

- PIC18F27K40 Microcontroller, 64 MHz (16 MIPS)
- 128 KB Program Flash Memory, 120 KB usable
- Operating voltage 3.3 V to 5.5 V, absolute maximum rating 6.5 V
- 7 mA operating current, 25µA standby
- Power jumper to remove system bus load
- Seven 16 KB “chips” for ROM images
- Serial port interface for configuration and ROM image load
- Write-protected boot loader for software update
- ICSP connector for direct programming

## Contents

Installation
Overview
-ROM Control
-Planning Your Layout
MultiMod Configuration Details Serial Monitor Update Procedure Appendices

WARNING
Use of Alkaline batteries is not recommended, and may reduce the operating life of the PIC processor! Use rechargeable cells such as Eneloop® NiMH or similar.

## Installation

You should follow the usual safety practice when handling static sensitive electronic devices, particularly your HP-71B. Keep yourself grounded when installing or removing the MultiMod board. Handle the MultiMod board by its edges whenever possible, and avoid touching the contact pins in the 71B card reader well. An optional case¹
for the MultiMod board shields the board and makes it easier to insert and remove.

I strongly recommend removing your batteries first, after backing up any content. Though the HP-71B is designed for “hot” peripheral insert/remove, a bare board without an enclosure for pin alignment could result in a Memory Lost event. Remove the back cover over the card reader well, and the plastic header insert if present. Remove the J2 power jumper from the MultiMod board as shown in Figure 1 so that the PIC processor will not present a load on the 71B bus during installation. Insert the
MultiMod board into the card reader well, aligning the pins in the well with the circular contacts on the board. The board should be pressed firmly down to fully engage the pins, but avoid pressing directly on the contacts themselves with your fingers. A plastic tool is a better option for pressing on or close to these contacts. Once the board is firmly fitted you can replace the J2 power jumper, batteries, and the back cover.

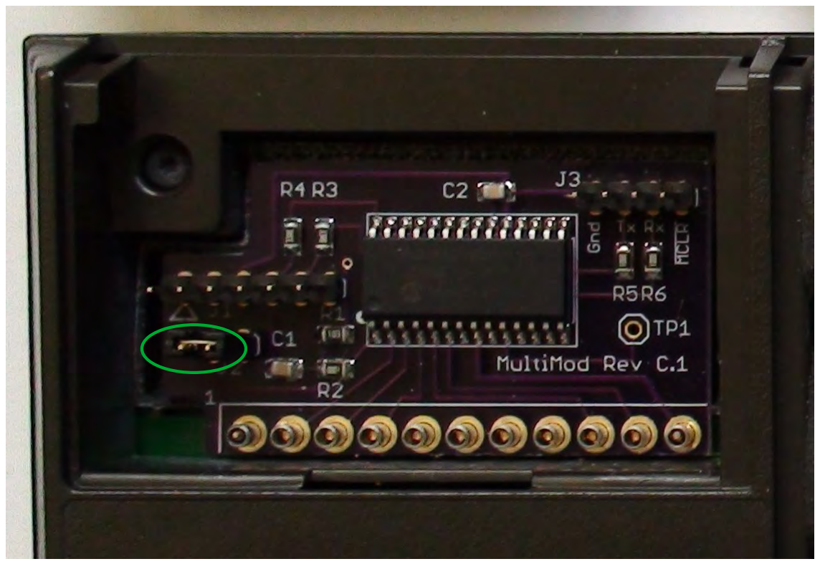
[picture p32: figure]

The MultiMod emulator comes preloaded with a sample ROM configuration. Turn your HP-71B on and type the VER$ command. You should see your current configuration. The MultiMod emulator does

1 Contact Dan Simpson, dan at azgraphixnorth ‘.’ com for ordering details.

Figure 1: Power Jumper not plug in its ROMs by default. You need to tell it to plug in or remove its ROMs using the POKE command. Try the command POKE “2C000”,”1” and then turn the 71B off and back on. Now see what is displayed by the VER$ command. Congratulations, you now have the Forth ROM, and J-F’s marvelous Math 2B and JPC ROMs installed on your HP-71B!

## Overview

The HP-71B MultiMod ROM Emulator can be thought of as seven 16KB flash memory chips, each of which can hold ROM image data of your choosing. A chip can hold a single 16KB ROM, or chips can be combined to hold 32KB, 48KB, or 64KB ROM images. Two chips can even hold a hard configured ROM image located at the 71B memory address E0000h. More than one ROM can be present – as many ROMs can be enumerated in a port as will fit in the seven available chips.

This manual section is focused on how to go about planning the layout of ROM images in the MultiMod emulator. A little background on how ROMs are discovered and configured during startup is provided as part of showing you how to install a set of ROMs of your own. Later sections walk you through the mechanics of loading ROM images and configuring the chips for ROM discovery.

## ROM Control

Each time the HP-71B turns on it probes each port to see what is installed. It does so in two stages, first sending a series of ID commands that ROM or RAM chips respond to with their hardware configuration strings. During this phase each chip is assigned a default address. In the second stage each chip is assigned a final address that it uses throughout the 71B operating session. Between configuration stages the 71B probes the bus to see if a hard configured ROM is present at address E0000h and marks that space as occupied when deciding where to put ROM or RAM chips during the second configuration stage.

You need to plug/unplug and cycle power each time you change your ROM configuration so that the 71B discovers these changes, just as you would when inserting or removing a physical ROM module. Plugging and unplugging the MultiMod emulator ROMs is done using the POKE command. Poking a “0” to address “2C000” will unplug the ROMs after cycling power. Poking a “1” will plug the ROMs back in after a power cycle. If you Poke the value “3” then a hidden 8K ROM, if present, will also be enumerated. Poking a “1” again will unplug the hidden ROM while leaving the other ROMs plugged in.

The PIC controller actually has eight 16KB Program Flash Memory (PFM) blocks numbered 0 to 7, but block 0 holds the write-protected boot block and the emulator software itself. As a convention, we’ll use the term “chip” for these flash memory blocks throughout this section. More hardware-specific detail will follow in the programming section.

Now you’ll next need to understand how to lay out your chosen ROM image data in the PIC flash memory and how to specify the way in which the ROM chips identify themselves to the 71B during the startup process.

## Planning Your Layout

The first task of course is deciding what ROMs you want the MultiMod emulator to host. You can use any combination of ROM sizes as long as the sum of sizes does not exceed the total size of the seven 16KB chips. All ROM images must fit in an integral number of 16KB chips, that is, a 16KB ROM or smaller will fit into a whole 16KB chip; all ROMs start at the beginning of a 16KB chip, and ROMs larger than 16KB must occupy adjacent 16KB chips. This means whole ROM images can’t be scattered about the chips, nor can they overlap within a chip. Finally, if you want to provide a hard configured ROM image, then that image must go into the last two chips, 6 and 7.

Simple enough. As a working example, let’s use a configuration similar to that which comes with the MultiMod emulator. For this configuration we’ll need the following files.

ROM Image File | ROM Size | # of 16KB Chips
HP-82478A_FORTH-ASSEMBLER_ROM.BIN | 16KB | 1
HP-82478A_FORTH-ASSEMBLER_HRD-FIX.BIN | 32KB | 2
MATH2B.BIN | 32KB | 2
JPC05.BIN | 32KB | 2

Note that the number of chips used equals the number of chips available. Not by accident! The next task is to map the ROM images we have to the seven available chips. The mapping process assigns ROM image content²
to one or more of the seven chips using the rules first specified in this section. Let’s assign the above images to chips in the order of image appearance, keeping in mind the rule for assigning a hard configured ROM image. The assignment appears below.
ROM Image | Chip Number
Forth Assembler (16K) | 1
Math 2B (32K) | 2
Math 2B (32K) | 3
JPC05 (32K) | 4
JPC05 (32K) | 5
Forth Hard ROM (32K) | 6
Forth Hard ROM (32K) | 7

2 We’ll see later the importance of distinguishing between ROM content in flash memory versus the structure of ROMs held in memory.

The 16KB ROM image goes into the first chip and the 32KB ROM images go into adjacent 16KB chips. The hard configured Forth ROM image goes in chip numbers 6 and 7. If you are not using a hard ROM then those two chips are available for any other ROM(s) you might want.

Another thing to keep in mind while laying out your ROM images is that ROMs are enumerated in the order they appear in the table. ROMs will appear in the above listed order when using the SHOW PORT command. So the Forth ROM will appear as PORT(5.00), the Math ROM as PORT(5.01) and the JPC ROM as PORT(5.02). Try using the command CAT :PORT(5.02) to see the content of the JPC ROM.

The above structure is suitable for other ROM arrangements. For example, if you wish the JPC ROM to appear first in your version command list, you can simply swap the ROM content between chip sets 2&3 and 4&5. An even more interesting arrangement if you have a version 1A of the HP-IB module, is to override its built-in ROM by placing the 16KB HP-IB 1B version just before the JPC ROM image. One such arrangement is shown here.

ROM Image | Chip Number
HP-IB 1B (16K) | 1
JPC05 (32K) | 2
JPC05 (32K) | 3
Math 2B (32K) | 4
Math 2B (32K) | 5
Finance ROM (16K) | 6
Text Editor ROM (16K) | 7

This is all the information needed before programming your own ROM emulator arrangement. Use the scratch table below to layout the ROMs you need.

ROM Image | Chip Number
| 1
| 2
| 3
| 4
| 5
| 6
| 7

## MultiMod Configuration Details

When configuring the MultiMod it’s important to differentiate between the structure and the content of ROMs in the MultiMod. The structure outlined in the previous section consisted of a 16K ROM, two 32K ROMs, and a hard ROM, all residing in a set of seven 16KB chips. That structure is stored in an internal table that can be altered using serial monitor commands.

The ROM image content of a given chip is actually stored in the seven³
16KB Program Flash Memory
blocks of the internal microcontroller as shown in the memory layout below. When you specify a chip number, you are pointing to an internal flash memory block.
ROM Table | | Program Flash | ROM Content
Forth ROM | 1 | 04000h - 07fffh | “forth1b.dat”
MATH ROM | 2 | 08000h - 0bfffh | “math2b.dat”
MATH ROM | 3 | 0c000h - 0ffffh
JPC ROM | 4 | 10000h - 04fffh | “jpc05.dat”
JPC ROM | 5 | 14000h - 07fffh
Forth Hard ROM | 6 | 18000h - 1bfffh | “forth1bhrd.dat”
Forth Hard ROM | 7 | 1c000h - 1ffffh

The next section will illustrate how to use the serial monitor built into the MultiMod ROM Emulator software to configure the number and size of the ROMs in your MultiMod, and how to upload ROM images to the MultiMod flash memory. You will be working with an internal ROM Configuration Table that provides information on the ROMs you create in your MultiMod. The internal table contains the configuration string each ROM chip returns for an ID command (shown in bold) along with other control values. A illustrative representation of the table is shown next.

ROM Image Filename | Size | Resv | Type | Class | Last | Flag | Addr | Chip | Line | Field | Data | Desc
| | 0x00 | 0x01 | 0x00 | | | 0x00 | | 1 | Size | 0x0A | 16KB
| | 0x00 | 0x01 | 0x00 | | | 0x00 | | 2 | | 0x09 | 32KB
| | 0x00 | 0x01 | 0x00 | | | 0x00 | | 3 | | 0x08 | 64KB
| | 0x00 | 0x01 | 0x00 | | | 0x00 | | 4 | Last | 0x00 | No
| | 0x00 | 0x01 | 0x00 | | | 0x00 | | 5 | | 0x08 | Yes
| | 0x00 | 0x01 | 0x00 | | | 0x00 | | 6 | Flag | 0x00 | Cont.
| | 0x00 | 0x01 | 0x00 | | | 0x00 | | 7 | | 0x01 | Stop
MMIO Address | 0x00 | 0x00 | 0x00 | 0x0C | 0x02 | 0x00 | 0x00 | 0x00 | 8 | | 0x02 | H-R

3 As we’ll see later, half of program flash memory block 0 is available for a “hidden” 8K ROM.

## Serial Monitor Update Procedure

You can use an ordinary USB to Serial cable, either 5V (preferred) or 3.3V logic level. Series resistors in the transmit and receive lines protect a 3.3V interface. Configure your terminal emulator for 19200 baud, 8-bit data, no parity, 1 stop bit, and XON/XOFF flow control. The monitor uses a Carriage Return for line termination so configure your terminal to convert CR to CR-LF (“Auto” in TeraTerm for the Receive Setting). Connect the serial lines to the four pin header J3 as shown in Figure 3.

Serial Connector Pin Assignment
Pin | Ground | Rx | Tx | MCLR
Serial Cable | Ground | Tx | Rx | RTS (optional)

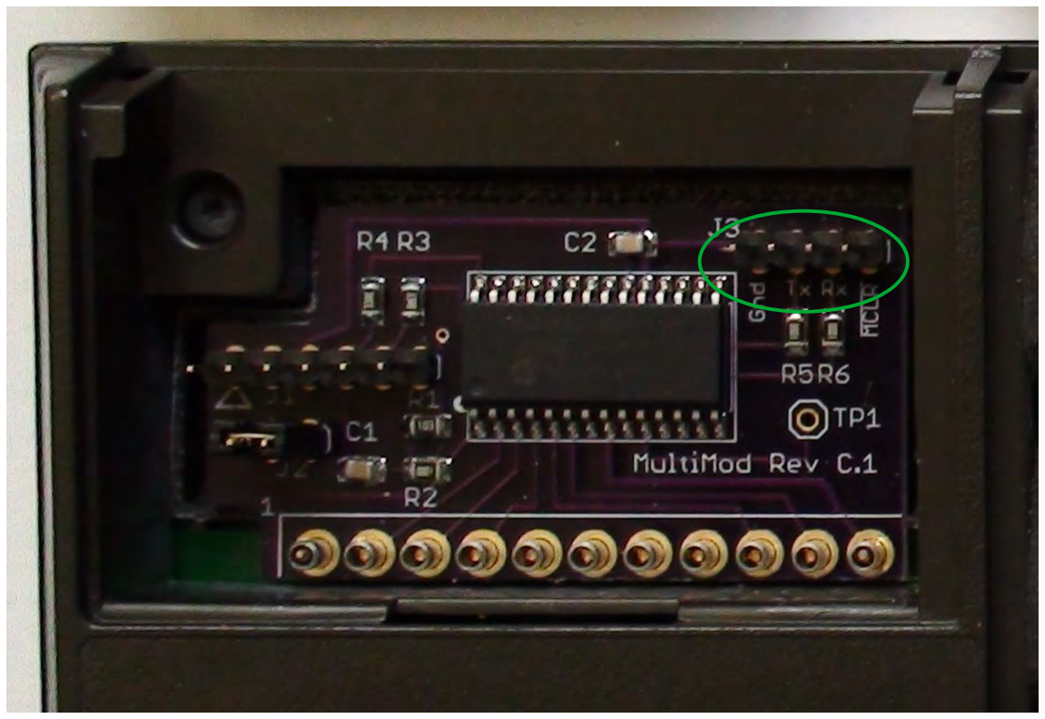
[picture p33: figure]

Before starting a serial monitor session it is best to unplug your ROMs using the POKE command. Your HP-71B should be off when communicating with the MultiMod emulator since the 71B bus is ignored while the serial monitor is active. Press the Return key to transfer control to the serial monitor. It should respond with the message Press ? For Help. Let’s have a look at the available commands. Press ‘?’ for a quick list of commands.

Don’t forget to unplug ROMs whenever you make changes to ROM structure or content in the MultiMod and cycle power afterwards. Failure to do so could result in confusion on the part of your HP-71B and the likelihood it won’t recognize your changes. If so unplug with POKE “2C000”,“0” cycle power and plug your ROMs back in.

Figure 2: Serial Port Connector

Command | Argument(s) | Description
ROM | Configuration or none Configures a given table entry; No arguments list all entries
ERASE | Block # (0-7) | Erases the flash memory of the specified flash block
IMAGE | Block # (0-7) | Uploads a ROM image, starting in the specified flash block
LAST | Entry # (1-7) | Indicates the last table entry to be enumerated
HARD | Y or N | Indicates whether a hard ROM is present
COMMIT | Confirm Y or N | Commits a configuration to permanent flash
PLUG | Y or N | Sets the flag to plug or unplug ROMs when the 71B turns on
QUIT | none | Exit serial monitor, return to normal processing

Below is an arrangement of ROM table entries that contains some of the default content of your MultiMod ROM emulator. Each table entry points to a 16KB “chip” or program flash memory block. This table is used to represent the structure of ROMs stored in the MultiMod flash memory.

ROM Image Filename | Size | Resv | Type | Class | Last | Flag | Addr | Chip | Line | Field | Data | Desc
Forth1B | 0x0A | 0x00 | 0x01 | 0x00 | 0x08 | 0x00 | 0x00 | 1 | 1 | Size | 0x0A | 16KB
Math2B | 0x0A | 0x00 | 0x01 | 0x00 | 0x00 | 0x00 | 0x00 | 2 | 2 | | 0x09 | 32KB
Math2B | 0x0A | 0x00 | 0x01 | 0x00 | 0x08 | 0x00 | 0x00 | 3 | 3 | | 0x08 | 64KB
JPC05 | 0x0A | 0x00 | 0x01 | 0x00 | 0x00 | 0x00 | 0x00 | 4 | 4 | Last | 0x00 | No
JPC05 | 0x0A | 0x00 | 0x01 | 0x00 | 0x08 | 0x01 | 0x00 | 5 | 5 | | 0x08 | Yes
Forth1B hard | 0x0A | 0x00 | 0x01 | 0x00 | 0x08 | 0x02 | 0x00 | 6 | 6 | Flag | 0x00 | Cont.
Forth1B hard | 0x0A | 0x00 | 0x01 | 0x00 | 0x08 | 0x02 | 0x00 | 7 | 7 | | 0x01 | Stop
MMIO Address | 0x00 | 0x00 | 0x00 | 0x0C | 0x02 | 0x00 | 0x00 | 0x00 | 8 | | 0x02 | H-R

Let’s walk through this example to familiarize ourselves with the serial monitor commands before giving a detailed definition for each. Connect your USB serial cable as shown and tap return. After you see the opening prompt, type “r” followed by return. An important feature to note is that the serial monitor is not case sensitive and that it uses command auto-completion. When you typed “r” the monitor echoed ROM plus a space. Auto-completion saves time and avoids typing errors. You would see the output below.

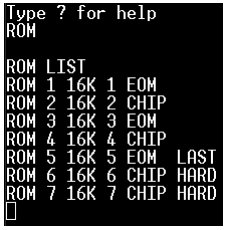
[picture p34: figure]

The first column in the listing is the table entry number, referred to as “Line” in the above table. The second column shows the size of the chip that the table entry represents (“Size”). The third column shows which program flash memory block the table entry points to for ROM image content (“Chip”). The fourth column indicates if the table entry (“Last”) holds a complete ROM image or is part of a sequence of chips making up a complete ROM entry.

Notice that chip 5 is marked LAST to indicate it is the last ROM that will be enumerated during startup. Since we have a Forth hard configured ROM present, the last two table entries are marked HARD. If you were now to type the command LAST 3 and turn your 71B back on and plug the ROMs in, only the first two ROMs would be enumerated. The VER$ command would show that the Forth and Math 2B ROMs were present but the JPC ROM would no longer be present.

If we were creating this ROM structure, the commands would be as follows. Note the difference between what is displayed as you type and the actual keystrokes you enter. That’s auto-completion!

Keystrokes | Command Display | Description
r·1·1·1 | ROM 1 16K 1 | A single 16K ROM in one Chip
r·2·c·2 | ROM 2 CHIP 2 | The first of a two-chip sequence for a 32K ROM
r·3·1·3 | ROM 3 16K 3 | The last 16K chip in a 32K ROM sequence
r·4·c·4 | ROM 4 CHIP 4 | The first of a two-chip sequence for a 32K ROM
r·5·1·5 | ROM 5 16K 5 | The last 16K chip in a 32K ROM sequence
r·6·1·6 | ROM 6 16K 6 | Two chips for a hard-configured ROM, the ID
r·7·1·7 | ROM 7 16K 7 | String is not relevant for hard ROM
l·5 | LAST 5 | The last table entry is 5
h·y | HARD YES | There is a hard ROM in entries 6 & 7

Figure 3: ROM Table Listing

The serial monitor is not case sensitive so it is perfectly acceptable to use lowercase letters as shown in the keystrokes column. If we were creating a ROM structure for the first time then the ROM content would need to be uploaded. To show that process, why not replace the Forth ROM with the HP-41 Translator ROM? This example will illustrate how you might use the same ROM structure to hold different ROM content. The process is quite simple; Erase blocks 1, 6, and 7 then upload your content. The commands are as follows.

Keystrokes | Command Display | Description
e·1 | ERASE 1 | Erase flash memory block 1 (“chip” 1)
e·6 | ERASE 6 | Erase flash memory block 6
e·7 | ERASE 7 | Erase flash memory block 7
i·1 | IMAGE 1 | Upload ROM image to block 1
i·6 | IMAGE 6 | Upload ROM image to block 6, continuing to 7

So how do you actually upload ROM content? When you type the Image command followed by the flash block (“chip”), the serial monitor responds with a carriage return and waits for you to send ASCII hex strings that encode the ROM binary content. Hex values are not case sensitive and the monitor will ignore non-hex characters such as space or comma. The Hex strings are broken into lines marked by carriage return or linefeed. The monitor will buffer the data until the end-of-line (CR or LF) character is received and then write the content to program flash. The process is terminated when the monitor sees multiple CR characters. The monitor will write data to the block you specify and continue with the next block if there is more data sent. This is what happens when you send the 32KB hard ROM for the HP-41 Translator to blocks 6 and 7.

Where does the data come from? You should already have a number of .DAT files containing the data for the publicly available ROMs in .BIN format. You can create a DAT file using the Python program as shown.

python3 bin2dat.py HP-82478A_FORTH-ASSEMBLER_ROM.BIN forth.dat

You send the DAT file content without any sort of transmission protocol other than the XON/XOFF handshake. In the TeraTerm terminal emulator you’ll find this as “Send File” in the File menu. Once the file is uploaded hit the Return key a couple of times.

Turn your HP-71B on, plug the ROMs back in and cycle power. After the VER$ command try typing HP41 and see what happens. In the HP-41 emulator type BASIC to return to the regular BASIC prompt, then unplug ROMs before turning off the 71B. This illustrates how ROM content can be uploaded to a particular ROM structure in the MultiMod. Try for yourself loading other 32K ROM images in the two available 32K ROMs, or a 16K ROM in the single 16K ROM structure.

To further illustrate the difference between content and structure, let’s try to create the following structure.

ROM Image Filename | Size | Resv | Type | Class | Last | Flag | Addr | Chip | Line | Field | Data | Desc
Forth1B | 0x0A | 0x00 | 0x01 | 0x00 | 0x08 | 0x00 | 0x00 | 1 | 1 | Size | 0x0A | 16KB
Math2B | 0x09 | 0x00 | 0x01 | 0x00 | 0x08 | 0x00 | 0x00 | 2 | 2 | | 0x09 | 32KB
JPC05 | 0x09 | 0x00 | 0x01 | 0x00 | 0x08 | 0x01 | 0x00 | 4 | 3 | Last | 0x08 | 64KB
empty | 0x0A | 0x00 | 0x01 | 0x00 | 0x00 | 0x00 | 0x00 | 4 | 4 | | 0x00 | No
empty | 0x0A | 0x00 | 0x01 | 0x00 | 0x08 | 0x00 | 0x00 | 5 | 5 | | 0x08 | Yes
Forth1B hard | 0x0A | 0x00 | 0x01 | 0x00 | 0x00 | 0x02 | 0x00 | 6 | 6 | Flag | 0x00 | Cont.
Forth1B hard | 0x0A | 0x00 | 0x01 | 0x00 | 0x00 | 0x02 | 0x00 | 7 | 7 | | 0x01 | Stop
MMIO Address | 0x00 | 0x00 | 0x00 | 0x0C | 0x02 | 0x00 | 0x00 | 0x00 | 8 | | 0x02 | H-R

Here we have the same arrangement of a 16K ROM and two 32K ROMs with a hard configured ROM. The difference lies in the fact that we’re telling the HP-71B that the 32K ROMs are held in a single 32KB chip. Two of the internal 16KB program flash blocks (“chips”) are still needed to hold ROM content as can be seen by the chip number assigned to the two table entries. The content location of the two 32K ROMs is unchanged. The Last flag changes to indicate ROM enumeration ends with the third ROM table entry. So here are the commands used to create this structure.

Keystrokes | Command Display | Description
r·1·1·1 | ROM 1 16K 1 | A single 16K ROM in one Chip
r·2·3·2 | ROM 2 32K 2 | A single 32K ROM in a 32K Chip (2 flash blocks)
r·3·3·4 | ROM 3 32K 4 | A single 32K ROM in a 32K Chip (2 flash blocks)
r·6·1·6 | ROM 6 16K 6 | A single 16K ROM in one Chip
r·7·1·7 | ROM 7 16K 7 | A single 16K ROM in one Chip
l·3 | LAST 3 | Last table entry is 3
h·y | HARD YES | There is a hard ROM in entries 6 & 7

If you turn the 71B back on and plug the ROMs in again you’ll see the original configuration with Forth, Math and JPC ROMs. Nothing has changed as far as content and its location in program flash memory. Only the structure of ROMs contained in the MultiMod has changed.

To finish this extended example, let’s access the so-called “hidden” ROM. As mentioned earlier, block 0 of program flash memory contains the write-protected boot loader and the ROM Emulator software. There is sufficient room left over to hold 8 KB of 71B ROM image data. For technical reasons this must be represented in the configuration table as a 16KB ROM. You can load the content with the IMAGE command but be warned, uploading more that 8 KB of data will overwrite what you have in block 1 (or worse, if you fail to erase the block!) Try the following command sequence to create and upload data to block 0.

Keystrokes | Command Display | Description
r·4·1·0 | ROM 4 16K 0 | A single 16K ROM in block 0
l·4 | LAST 4 | Last table entry is 4
e·0 | ERASE 0 | Erase flash memory block 0
i·0 | IMAGE 0 | Upload ROM image to block 0

Use the ulib.dat file to upload the content of J-F’s ULIB LEX library ROM. Turn the 71B back on, plug in ROMs and cycle power. You now have J-F’s Ultimate ROM!

## Serial Monitor Commands

Hopefully the previous extended example illustrates how you can configure MultiMod to support whatever ROMs you’d like to have at hand on your 71B. The serial monitor makes it easy to change ROM content by, for example, replacing the 32KB JPC ROM with the 32KB AmpiStats ROM. Or you can alter the structure by turning one of the 32 KB ROM entries into two 16 KB entries and uploading the Finance and Text Editor ROMs.

Let’s have a detailed look at each of the available commands and the parameters each use.
Command Nomenclature
<entry> | ROM Enumeration Table entry number; Value 1 – 7
<size> | ROM size; 16K, 32K, 64K or CHIP (16K)
<chip> | Flash chip number; Value 0 - 7
[ … ] | Optional parameters

ROM [<entry> <size> <chip>]
The ROM command by itself with no parameters will list all of the entries in the ROM Configuration Table. This is useful as a check following any changes you have made. With three parameters, the ROM Enumeration Table is updated with the values given. Be sure any ROMs you define don’t overlap in program flash memory, and be sure to mark the last table entry using the LAST command.

You can use the ESCAPE key to cancel a command. If your terminal emulator interprets escape sequences, you may need to press the RETURN key after ESCAPE.

Any <size> value used sets the End-of-Module flag (EOM) telling the HP-71B that any chip that follows is another flash module. For a sequence of 16K chips, use one or more CHIP size and finish the sequence with a 16K size that sets the EOM flag. Terminating a sequence with any other size will likely yield odd results.

LAST <entry>
The LAST command marks the end of the defined ROMs that the MultiMod will enumerate on startup. Failure to mark the last entry could cause garbage to be presented to the 71B O/S, which usually will ignore anything that doesn’t have a valid ROM signature. In the worse case however, the O/S has been known to get stuck in an infinite enumeration loop and never show the command prompt. Such a condition may require an INIT command after you remove the MultiMod power jumper, so take care to examine your new configuration before you try it!

HARD Y|N
The HARD command will mark the ROM Configuration Table’s last two entries as having or not having a hard-configured ROM that will appear at address E0000h. Enter ‘Y’ or ‘N’ (case ignored) to set or clear this feature of the MultiMod. The 71B will check for the existence of a ROM in that location by reading the first nibble but will do nothing to validate the ROM content. Failure to provide the hard ROM to the Forth Application ROM will result in an interesting crash when the app is invoked.

ERASE <chip>
The ERASE command is needed to prepare a “chip” (program flash memory block) for new data. Failure to erase a non-empty flash block before using the IMAGE command will result in garbage. The only appropriate warning here is to be sure you are erasing the right block. Hit Escape to back out.

IMAGE <chip>
The IMAGE command is used to send a ROM binary content in an ASCII hexadecimal format. Characters ‘A’ through ‘F’ can be in either case, and any non-hex character (spaces or commas, for instance) is ignored. The hex strings sent must be broken up into lines terminated by either CR or LF (or CR-LF). The data that is sent is converted to binary and stored in a buffer, and that buffered data is written to flash on receipt of the end of line character.

Warning: Failure to limit the amount of data sent in a line will cause the buffer to overwrite system variables and crash the emulator. Failure to use the XON/XOFF protocol when sending data is likely to put the serial monitor in an unresponsive state. Both conditions will likely require resetting the MultiMod as outlined in the Recovery section in the Appendix.

COMMIT Y|N
The COMMIT command will write the ROM Configuration Table that resides in RAM back to flash. When the MultiMod first powers up or is reset, it copies a table held in program flash memory into RAM where it is subsequently used each time the MultiMod responds to initialization. The serial monitor alters this temporary copy in RAM. If that copy should prove to be seriously invalid, it can be restored to its initial state by resetting the MultiMod.

The COMMIT command rewrites the table in flash with the (altered) content held in RAM. The command should never be used without testing the configuration first. Remember that the
ROM content is kept in program flash memory and survives a reset. If you want the structure to survive a reset, use the COMMIT command to make it permanent.

QUIT
The QUIT command exits the serial monitor and returns control to the normal ROM emulator functionality. Always use Quit to exit the serial monitor or the ROM Emulator will not respond when you use your 71B.

PLUG Y|N
The PLUG command allows you to plug in (Y) or unplug (N) the ROMs. The command can be used to unplug ROMs if you forgot to do so before entering the serial monitor. If you did unplug them, you can plug them back in, saving time when you turn the 71B back on.

A Note On Error Checking
A certain amount of error checking and data validation is done in the serial monitor and in the emulation code that uses the data altered by the monitor. The limitations of available program flash memory dictate an approach which assumes the user of the monitor understands what is being done and is adept at making appropriate changes. Some effort is made to simplify usage, through auto-completion for instance, but little is done to support a casual user. That support is rightfully delegated to an external program tool that uses the serial monitor commands to alter configuration, erase blocks, and upload image data. A GUI interface to the MultiMod could be written in Python or Java so that the user need only drag and drop BIN files to a panel, move them about to establish enumeration order, then program them into a MultiMod with a single button.

## Appendices

## Appendix A. Operation, Update, and Recovery

Operation
The Microchip PIC processor used in the MultiMod is rated for normal operation between 2.3V and 5.5V, requiring at least 3.0V to function at its designed operating frequency. The absolute maximum supply voltage, beyond which damage will occur, is 6.5V. What does this mean as far as using the MultiMod in an HP-71B? The following table of measured voltage at the card reader pins should help.
Condition | MultiMod Out | MultiMod In
AC Adapter, no batteries | 5.55V | 5.51V
Freshly charged NiMH batteries | 5.38V | 5.26V
Alkaline batteries (fresh Everyready Gold) | 6.04V | Not Measured
AC Adapter, NiMH batteries | 5.55V | 5.49V
AC Adapter, Alkaline batteries | 6.04V | Not Measured

The supply voltage when an HP 82069D AC Adapter is used tends to be the higher of the voltage from batteries or adapter. With any of the measured values with the MultiMod in, the supply voltage seen by the PIC processor is no more than a few percent higher than its recommended maximum operating voltage. Does this mean you can use regular alkaline cells in your 71B with a MultiMod installed?

Perhaps, but as they say, Your Mileage May Vary. These measures could change somewhat with the load from installed front port & HP-IL modules, and from different brands of alkaline cells, hence the warning to stick with rechargeable cells versus disposable ones. There is headroom between the 5.5V recommended operating maximum versus the 6.5V absolute maximum supply voltage, but use of alkaline batteries might possibly shorten the processor operating life. Only you can find out for sure!

The good news is, long term operation using the AC adapter with/without NiMH cells is perfectly OK.

The MultiMod consumes approximately 7mA when operating and 25µA after entering sleep mode several minutes after the HP-71B is turned off. According to the HP-71B Owner’s Manual, the 71B 30µA when off, so with the MultiMod inserted and in sleep mode, power consumption roughly doubles. The 71B consumes approximately 0.75mA when on but not running and 10mA when running a program. The presence of the MultiMod would raise Idle current to 7.75mA when the 71B is on, and 17mA when running a program. Reduced battery life can be expected, but when the MultiMod isn’t needed its power jumper can be removed to eliminate its impact on battery life.

Recovery
What do you do if something goes wrong with a configuration you’ve loaded? In most cases you just won’t see the ROMs you expect in the output of the version command. If altering the configuration doesn’t help, then it’s possible the PIC processor is hung. You can try turning the 71B off, remove the J2 jumper for at least 5 seconds⁴
before replacing the jumper, then turn the 71B back on. A more reliable way of resetting the processor is to briefly short the Ground and MCLR pins. This is done by shorting the leftmost and rightmost pins of the J3 serial connector.

If the PIC processor in the MultiMod should “run wild” then there is a very real chance of bus collisions as both the PIC and Saturn processors try to drive the bus. That will definitely cause the Saturn processor to crash. Hard. Pressing the ON button in this scenario will have no effect, nor will pressing the INIT key sequence (ON and ‘/’ at the same time). I’ve only ever observed this behavior during development, but it’s still worth mentioning. Recovery from this scenario, if a direct reset doesn’t work, would involve removing the batteries from the 71B for a while.

The only way to muddle things up so that the operation of the MultiMod is compromised⁵
would be to
overwrite the emulator code itself. This can only be done using the boot loader or a PICKit3 programmer, and it would likely need to be more than a little intentional.

If the emulator software is no longer functional then you can’t expect the application to transfer control to the boot loader client when it sees the Break condition. You’ll need force the boot loader to respond. First, remove the J2 jumper. Now connect the serial cable, run the boot loader client, and use it to assert Break. Put the J2 jumper back in so that the PIC processor goes through the boot loader during the power-up reset sequence. The boot loader will respond to the Break by not transferring control to the emulator application. You can then press the button to connect to the boot loader and restore the emulator software from the source Hex file.
Update
You’ll find a Hex file named MULTIMODvxxx.HEX in the src subdirectory. The ‘xxx’ indicates the version number of the MultiMod emulator software. Occasional updates will be available with newer version numbers. Once enhancement and other changes are greatly reduced in frequency, the source itself will be released.

Updating the system software involves loading the latest system Hex file into the boot loader client and writing the software to the processor flash memory. Follow the serial monitor directions for connecting a USB to serial cable to the MultiMod. Launch the “AN1310ui.exe” program and set its configuration as shown.

4 A 0.1 µF capacitor needs to discharge.
5 Someone somewhere will no doubt prove me wrong by finding some other way to munge things up. Let me know how.

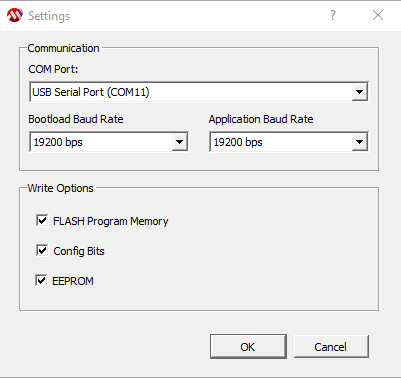
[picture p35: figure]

Once the client is configured, press the blue Pause button to send a Break to the MultiMod board so that control is transferred to the boot loader, then press the red Stop button to establish a connection. Use the File/Open or folder icon to read in the Hex file you wish to program into the processor’s flash memory. All that’s needed now is to press the red-arrow down Write button to download your content.

Figure 4: Boot Loader Client Settings

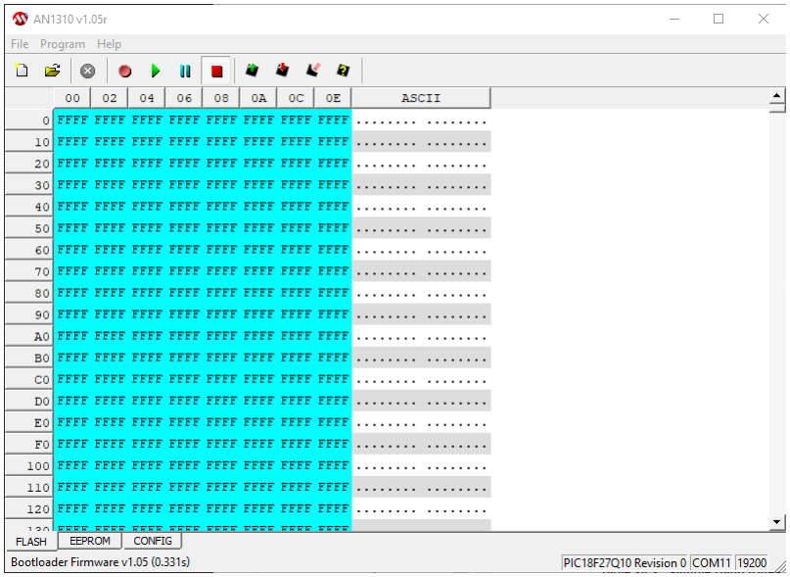
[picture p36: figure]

Once the new version of the MultiMod ROM Emulator software is installed you can exit the boot loader client. You may need to reset the MultiMod PIC processor by removing and replacing the J2 power jumper or resetting the processor as detailed in the Recovery section.

Figure 5: Client Main Page

Note: A platform independent Python3 version of the Microchip® boot loader client is under development. The Microchip client source code is available for those adventurous souls who care to venture into unsupported territory. Just ask.

## Appendix B. Making Your Own ROM

My thanks to Bob Prosperi for explaining how this is done. I’ve used Christoph Gießelink’s Emu71⁶ emulator for Windows to build my own ROM images, and you can too. You’ll need to install the emulator as well as Anaconda/Miniconda for pyilper⁷
. A LIF disk image containing files needed can be found in the LEX directory.

To begin, decide what size ROM you want to make and add an independent RAM of that size to your Emu71. Steps for doing so are

- Turn off the emulator
- Select Port Configuration from the Edit menu and pick an empty port (Port 2 in this example)
- Press Add. A default 32KB RAM is shown. Change the size appropriately, then press Apply
- Exit configuration and turn the emulator on
- Use the command FREE PORT(2) to create the independent RAM (IRAM)

At this point you’re ready to copy the files you want on your ROM over to the IRAM you just created. Start the Anaconda shell and type pyilper. I’ll assume you have a similar pyilper device setup as shown below. I’ll use the following device assignment in the example

ASSIGN IO “:P1,:D1,:D2,:T,:PL”

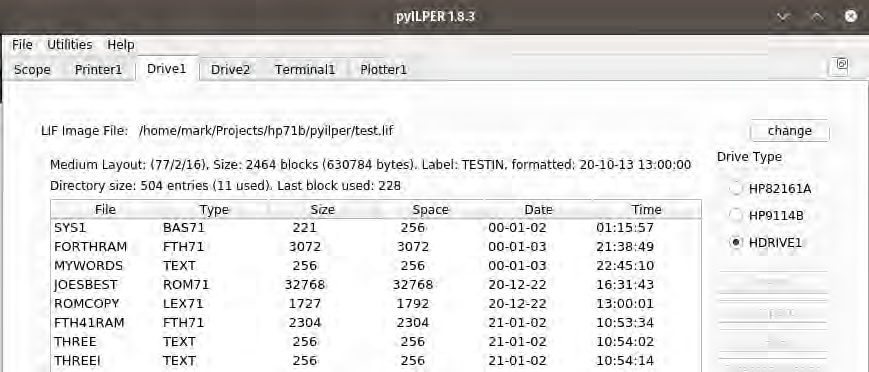
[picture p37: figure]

I generally use Drive1 as my working drive and Drive2 to hold what I’m working with at the moment, so this example will assume you’ve loaded the working LIF image in Drive1 and the LIF image(s) you’re using for your ROM in Drive2.

6 https://hp.giesselink.com/emu71.htm
7 https://github.com/bug400/pyilper/

The next step is to copy the files for your ROM to the IRAM you created. This is a three step process that can be a bit tedious if you have a lot of files, so consider writing a BASIC program to automate the task. The steps are to copy the desired file to main RAM, then copy it to IRAM, then purge the file from main RAM using the commands

COPY “MYROMFILE:D2”
COPY MYROMFILE TO “:PORT(2)”
PURGE MYROMFILE

Once copying is complete it’s a good idea to back up your IRAM in case you want to change the content later. Go back to Port 2 in the Edit/Port Configuration view. Click to select the IRAM you created then right-click and select the Save Memory Data… command. Save the IRAM content as a BIN file. Give it a name to remind you it is RAM not ROM, i.e. MYIRAM.

When you are done, load the ROMCOPY LEX file from drive 1 and use the following commands to create a ROM image

COPY “ROMCOPY:D1”
ROMCOPY “:PORT(2)” TO “MYROM:D1”
ROMCOPY “MYROM:D1” TO “:PORT(2)”
PURGE “MYROM:D1”
ROMCOPY “:PORT(2)” TO “MYROM:D1”

Now for the ROM BIN file. Go back to Port 2 in the Edit/Port Configuration view. Select the IRAM you created then right-click and select the Save Memory Data… command. Save the ROM you created as a BIN file with a name such as MYROM.BIN to use later. You can validate the BIN file by going to another port (port 3 for example) and use Add & Apply to create a ROM using your BIN image. Use the command CAT :PORT(3) to confirm your files are present.

With that ROM tested and ready to load, use the bin2dat.py program to convert the file to a format suitable to the serial monitor. Use the monitor to load the ROM into your MultiMod ROM emulator. Enjoy!

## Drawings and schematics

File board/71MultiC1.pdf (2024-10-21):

## ESD Protection

## PICkit 3 Programmer

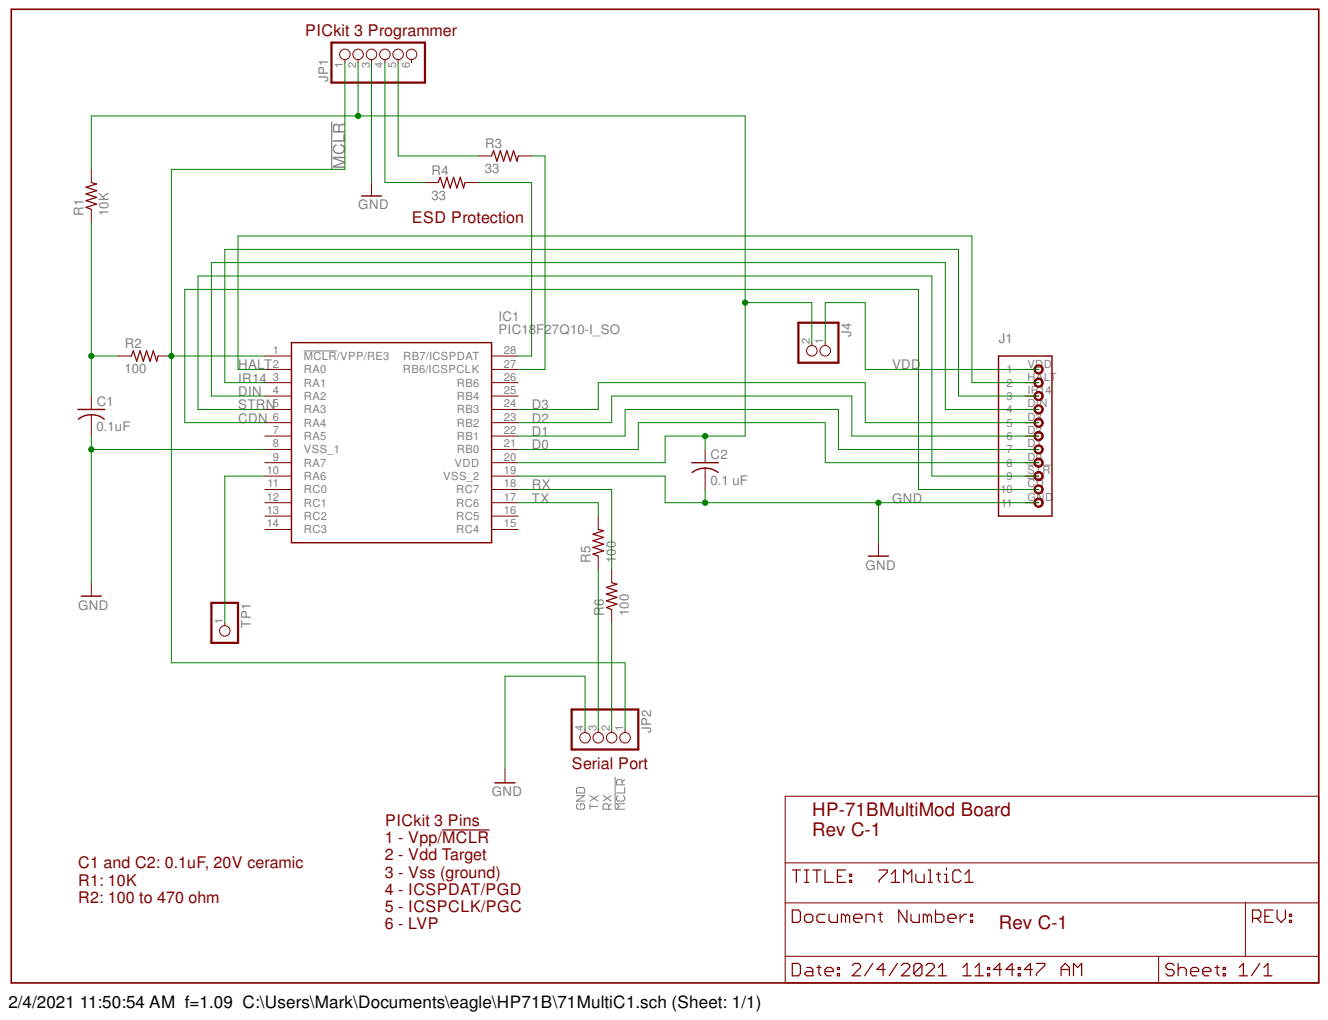
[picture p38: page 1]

2/4/2021 11:50:54 AM f=1.09 C:\Users\Mark\Documents\eagle\HP71B\71MultiC1.sch (Sheet: 1/1)

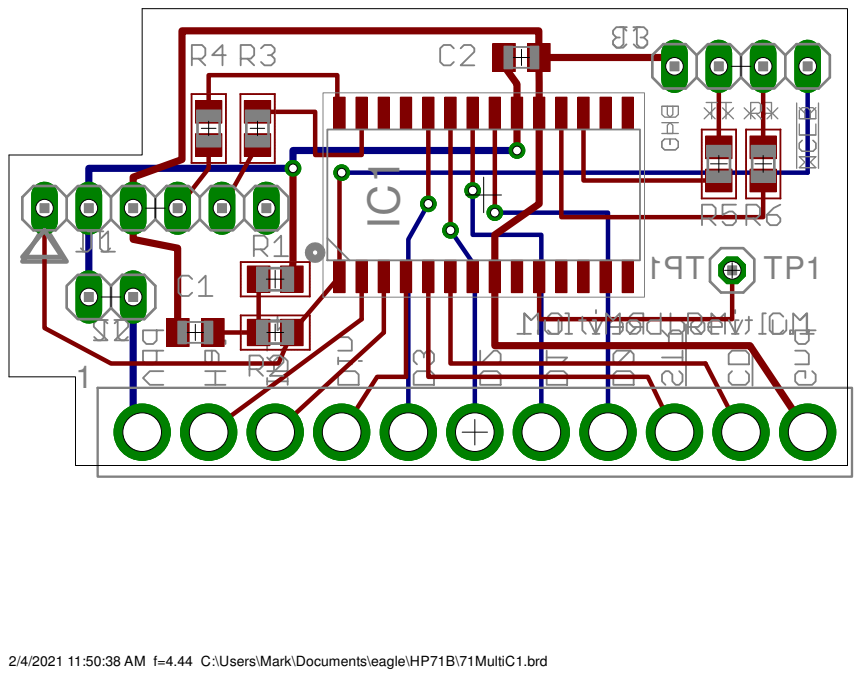
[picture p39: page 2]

2/4/2021 11:50:38 AM f=4.44 C:\Users\Mark\Documents\eagle\HP71B\71MultiC1.brd

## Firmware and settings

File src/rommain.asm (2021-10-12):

;*******************************************************************************
;                                                                              *
;    Filename:      rommain.asm                                                *
;    Date:          July 25, 2020                                              *
;    File Version:  1.0                                                        *
;    Author:        Mark A. Fleming                                            *
;    Company:                                                                  *
;    Description:   Emulate HP-71B ROM memory                                  *
;                                                                              *
;*******************************************************************************
;    Notes:                                                                    *
;      7/25/2020, Couldn't get relocatable mode directives to work so I set    *
;      mpasm option to work in absolute mode.                                  *
;      7/28/2020, By default, RAM access is by the Bank Select Register,       *
;      denoted by 0. I want the Access Bank mode which requires a 1 instead.   *
;      Anyplace that references an SFR, including WREG, must have a trailing   *
;      ,0 (here and in macro.inc)                                              *
;      8/7/2020, Annotate code with number of instruction cycles taken in      *
;      each half of a clock cycle. At 650KHz clock speed, there are only       *
;      770 ns per cycle half. At a PIC clock speed of 64 MHz that means just   *
;      12 instruction cycles per bus clock cycle half.                         *
;      8/12/2020, Rework how TBLPTR is used based on actual bus operations.    *
;      Precompute TBLPTR whenever PC or DP is loaded. When switching from      *
;      DP to PC, save TBLPTR and load new TBLPTR value.                        *
;      8/13/2020, Bus timing is critical in regard to when and how long a      *
;      device should drive the command bus. For the ID and two READ commands   *
;      I'm driving the bus immediately after the falling edge of STRn and      *
;      releasing it immediately after the rising edge of STRn. Hopefully I'm   *
;      within the limits of Tacc and Toh.                                      *
;                                                                              *
;*******************************************************************************
;                                                                              *
;    Revision History:                                                         *
;    1.0  25-July-2020                                                         *
;    2.0  1-October-2020                                                         *
;*******************************************************************************


;*******************************************************************************
; Theory Of Operation
;  The following sections provide a brief summary of how the HP-71 communicates
;  with devices plugged into it and the way this software emulates a ROM plugin
;  in particular.
;  
; Program Memory Map
;  0 0000 - 0 0007   RESET Vector
;  0 0008 - 0 0017   High Priority Interrupt Vector
;  0 0018 - 0 0027   Low Priority Interrupt Vector
;  0 0030 - 0 07FF   Primary Bootloader (memory protected)
;  0 0800 - 0 0FFF   Secondary Bootloader
;  0 1000 - 0 10FF   Program Constants
;  0 1100 - 0 117F   High Priority Interrupt Service Routine
;  0 1180 - 0 11FF   Low Priority Interrupt Service Routine
;  0 1200 - 0 3FFF   Application Code
;  0 4000 - 0 7FFF   ROM Block 1
;  0 8000 - 0 BFFF   ROM Block 2
;  0 C000 - 0 FFFF   ROM Block 3
;  1 0000 - 1 3FFF   ROM Block 4
;  1 4000 - 1 7FFF   ROM Block 5
;  1 8000 - 1 BFFF   ROM Block 6
;  1 C000 - 1 FFFF   ROM Block 7
;  
; Special Function Register Usage
;  
;  BSR E Addressed   BSR F Addressed   Access Bank Addressable
;  EA1    INT0PPS    F0A    IOCAF      F81    NVMCON1
;  EA2    INT1PPS    F0B    IOCAN      F82    NVMCON2
;  EB5    RX1PPS     F0C    IOCAP      F83    LATA
;  EBA    IPR0       F0D    INLVLA     F84    LATB
;  EC2    PIE0       F0E    SLRCONA    F85    LATC
;  ECA    PIR0       F0F    OSCONA     F88    TRISA
; *ECD    PIR3       F10    WPUA       F89    TRISB
; *ED7    CPUDOZE    F11    ANSELA     F8A    TRISC
;  ED8    OSCCON1    F15    INLVLB     F8D    PORTA
;  EDA    OSCCON3    F16    SLRCONB    F8E    PORTB
;  EDC    OSCEN      F17    ODCONB     F8F    PORTC
;  EDD    OSCTUNE    F18    WPUB       F99    RC1REG
;  EDE    OSCFRQ     F19    ANSELB     F9A    TX1REG
;  EE1    PMD0       F1D    INLVLC     F9B    SP1BRGL
;  EE2    PMD1       F1E    SLRCONC    F9C    SP1BRGH
;  EE3    PMD2       F1F    ODCONC     F9D    RC1STA
;  EE4    PMD3       F20    WPUC       F9E    TX1STA
;  EE5    PMD4       F21    ANSELC     F9F    BAUD1CON
;  EE6    PMD5       F2D    WPUE       FD8    STATUS
;  EFD    RC6PPS                       FD9    FSR2
;                                      FD9    FSR2L
;                                      FDB    PLUSW2
;                                      FE1    FSR1
;                                      FE1    FSR1L
;                                      FE3    PLUSW1
;                                      FE8    WREG
;                                      FE9    FSR0
;                                      FE9    FSR0L
;                                      FEB    PLUSW0
;                                      FEE    POSTINC0
;                                      FEF    INDF0
;                                      FF2    INTCON
;                                      FF3    PRODL
;                                      FF5    TABLAT
;                                      FF6    TBLPTRL
;                                      FF7    TBLPTRH
;                                      FF8    TBLPTRU
;                                      FF9    PCL
;                                      FFA    PCLATH
;                                      FFD    TOSL
;                                      FFE    TOSH
;  
;  Most of the Special Function Registers outside of the Access Bank addressing
;  mode range are only referenced during initialization. These need an explicit
;  BSR addressing mode bit set in instructions.
;  
;  Only two of the Special Function Registers (SFRs) in Bank E, marked with an
;  asterisk, need the 'banksel' command to switch to access them. All of the
;  commonly used SFRs in Bank F need an explicit Access Bank addressing mode
;  bit set in an instruction.
;  
; Pointer Usage
;  There are four pointers used in the emulator software; The TBLPTR pointer
;  into Program Flash Memory and the three pointers into data SRAM, FSR0, FSR1,
;  and FSR2. All four are used during initialization. During ROM Emulator
;  operation, the pointers in use are
;  
;  TBLPTR  Used to address PFM byte holding the next nibble to return by a
;          PCREAD or DPREAD command. The address is computed by the LOADPC or
;          LOADDP command and s saved after every use to locations PPTR or DPTR.
;  FSR1    Used by the PCWRITE and DPWRITE functions to write data to the
;          command buffer, starting at ROMNUM, and holding up to 16 nibbles
;  FSR2    Points to the Mapping Table MAPTAB, used during the mapping process
;          from the 20-bit Saturn address to the 17-bit PFM address.
;  
;  
; PIC18F Hardware Operation
;  The PIC18F used by this software has a 64 MHz internal clock that is
;  accurate to 1%. The CPU can execute 16 million instruction cycles per second
;  and the majority of instructions require only one cycle. The HP-71 CPU
;  operates at a nominal clock speed of 625 KHz, meaning about 25 instructions
;  per host clock cycle. As a hard real-time system, this software must perform
;  any required operation within the specified time limits, or fail.
;  
;  The PIC18F controller is connected to a 4-bit wide bidirectional command/data
;  bus and three control signals. Interrupts are used to speed response time in
;  place of spin-waits where timing is critical.
;  
; HP-71B Bus Operation
;  The authoritative source of information on the operation of the HP-71B
;  hardware can be found in the "Hardware Internal Design Specification for the
;  HP-71" from Hewlett Packard. A copy of the document can be found on a flash
;  drive from the Museum of HP Calculators. Consult the following web page
;  https://www.hpmuseum.org/cd/cddesc.htm
;  
; ROM Image Layout
;  The Program Flash Memory (PFM) of the PIC18F processor is organized as eight
;  8 KWord (16 KByte) blocks, for a total of 64 KWords (128 KBytes). Each PIC
;  instruction is one word (16-bits) in length. An important feature of this
;  mid-range controller is the ability to alter any location in flash on a byte
;  by byte basis. This allows the software to load ROM images or rewrite the
;  software itself without the need for a specialized programming device.
;  
;  ROM images are supported in four sizes; 16KB, 32KB, 48KB, and 64KB. The 16KB
;  PFM blocks can be thought of as seven 16KB "chips" into which a ROM image
;  can be placed. A ROM image can occupy one or more consecutive blocks
;  depending on its size. Each of the "chips" can be enumerated separately
;  with the ID string dividing the chips into sequences for each separate ROM
;  image. Nibble 3 of the ID string is used to denote the end of ROM sequnce and
;  distinguish one sequence from another.
;  
;  An alternative scheme is to directly encode the ROM size in the first ID
;  nibble. This would use a single table entry to encode 16K, 32K or 64K ROMs.
;  Either approach is supported, though the multi-chip approach is faster.
;  
; ROM Image Access
;  When the DP or PC register is loaded with an address, the software constructs
;  a pointer into PFM based on the register value. Subsequent reads are done
;  using the pointer if the register address is within the range of the ROM's
;  assigned base address. This is done by using the top five bits of the
;  register address to look up a value that is used in PFM addressing. If the
;  value is zero then the register does not address one of the seven 16KB PFM
;  blocks. Once the PFM pointer is constructed, it is saved across all nibble
;  reads. Importantly, this means the pointer-based reads can cross PFM block
;  boundaries, as would be expected with multi-chip ROM images. Boundary
;  crossing is not checked for, rather it is assumed ROM content would not
;  intentionally run off the end of a ROM resulting in invalid memory accesses.
;  
; Application Task Organization
;  The ROM emulator application can be thought of as a set of tasks whose
;  execution is controlled by interrupt dispatch or direct transfer of control.
;  In reality of course, these are really just States in a State Machine.
;  Nonetheless, this documentation will continue with the fiction of tasks.
;  These tasks are
;  
;  - Initialize Device. Initiated by the low priority interrupt generated by the
;    rising edge of the Daisy-In (Din) control line. Disables interrupts,
;    responds to the ID and CONFIGURE commands, then enables interrupts and
;    transfers control to the Idle task.
;  
;  - Command Dispatch. Initiated by the high priority interrupt generated by the
;    falling edge of CDn. A jump table is used to vector to the right code
;    segment based on command value and ROM size.
;  
;  - Idle. When the emulator is not loading a register or serving ROM content
;    it spends its time in the Idle task. The task can reduce power usage or
;    check the serial port for input from the user. A software counter is
;    started each time Idle is entered. The timer will expire after 2-1/2
;    minutes and the CPU will enter sleep mode to save power (~6 uA drain).
;  
; Command Processing
;  A command cycle begins when the CDn signal falls, then the STRn strobe clock
;  falls and then rises, marking a write cycle for the command. The falling
;  edge of CDn generates an interrupt that directs processor control to a
;  command dispatch routine. The interrupt was necessary because a command cycle
;  can begin in the midst of a series of Read or Write cycles. Timing
;  constraints proved too tight to simple check the state of the CDn signal
;  after a spin-wait on STRn going low.
;  
; Timing Considerations
;  As previously mentioned, all processing must complete during a 71B host
;  cycle. The first half of a cycle is marked by STRn going low and the second
;  half by STRn going high. Data from the CPU or ROM is stable by STRn rise
;  and is sampled there. The timing diagrams in IDS section 9 implies ROM data
;  must be stable within 200 ns of STRn fall, but this is not necessary for
;  ROM data output. On the other hand, early Saturn CPUs took considerably
;  longer before output data was stable, which caused invalid reads if data was
;  sample too early before STRn rise.
;  
;  A spin-wait macro is used to wait for STRn to go high or low, marking entry
;  into one of the host half-cycles. This spin-wait can be as little as 2
;  instruction cycles (IC) long or as much as 4 IC depending on whether the
;  STRn state is true or false at the time it is sampled. This introduces some
;  indeterminism or jitter in timing.
;  
;  Each of the spin-wait macros is annotated with the number of PIC instruction
;  cycles which follows it before the next spin-wait macro. These annotations
;  help in determining if processing is within cycle boundaries. Occasionally
;  the first and second half-cycles are "merged" by commenting out the spin-wait
;  for STRn rise.
;  
; Timing Failure Points
;  A 71B host timing cycle is long enough for about 25 PIC instruction cycles
;  at the nominal host frequency. There is natural variation from machine to
;  machine which could reduce the number of PIC instructions that can be used.
;  
;  The CDn falling edge that marks the begining of an command cycle causes
;  an interrupt that could cut off PIC processing before the end of a host
;  cycle. A repetitive series of cycles, as in Read and Write cycles, needs to
;  leave some timing slack at the end of the second host half-cycle.
;  CDn falling edge occurs about two instruction cycles before the falling edge
;  of STRn.
;  
;  A Load DP or Load PC command can be followed by another instruction,
;  even perplexingly by a Read command. This means processing in the Load
;  command must complete and leave some slack at the end. One cannot just
;  assume the Load command will be followed by a dummy cycle and one or more
;  read cycles.
;  
;  Possible Timing Fault Points in the Code
;  
;  - LOADREG macro. The last cycle that reads the high nibble of an address has
;    its half-cycles merged, resulting in an instruction count of 2~4 + 19. A
;    CDn interrupt here could possibly result in TBLPTRU being incorrectly set.
;  Addressed Dec. 12, 2020: Reduced to 2~4 + 18. Still tight!
;  
;  - PCREAD/DPREAD routine. The main loop that handles a series of nibble reads
;    has its half-cycles merged. Instruction coult is 2~4 + 19/20. A CDn
;    interrupt would only cause the next unneeded nibble to be lost or the
;    branch to the top of the loop to not be executed.
;  
; User Interaction
;  When first powered on the software does not enumerate a ROM image. If a hard
;  configured ROM image is stored, it will always respond to a probe of its
;  content by the HP-71B. To enumerate any other ROM image, use the POKE
;  command and store any non-zero hex digit to address 2C000h. Turn the 71B off
;  then on again to make the ROM images available. If a value of zero is
;  written and power is cycled then all ROM images will be unavailable.
;  
;*******************************************************************************    


    TITLE "HP71B ROM Emulator"

;*******************************************************************************
; Conditional Compilation Configuration Settings
; 
; If using an external bootloader usch as the one in AN851 or AN1310, define
; both XTRNBOOT and SERMON.
; If an internal monitor is part of the build, define SERMON.
; 
;*******************************************************************************    
#define XTRNBOOT
#define SERMON

; My development working microcontroller
#ifdef __18F27Q10
#include p18f27q10.inc
    LIST P=PIC18F27Q10
#endif

; Substitute chip, better flash programming
#ifdef __18F27K40
#include p18f27k40.inc
    LIST P=PIC18F27K40
#endif

#ifndef XTRNBOOT
    #include config.inc
#endif
#include macros.inc

;*******************************************************************************
; System Constants
;*******************************************************************************    
    CONSTANT    cmdNOP=         0x0
    CONSTANT    cmdID=          0x1
    CONSTANT    cmdPCREAD=      0x2
    CONSTANT    cmdDPREAD=      0x3
    CONSTANT    cmdPCWRITE=     0x4
    CONSTANT    cmdDPWRITE=     0x5
    CONSTANT    cmdLOADPC=      0x6
    CONSTANT    cmdLOADDP=      0x7
    CONSTANT    cmdCONFIGURE=   0x8
    CONSTANT    cmdUNCONFIGURE= 0x9
    CONSTANT    cmdPOLL=        0xA
    CONSTANT    cmdRESERVED1=   0xB
    CONSTANT    cmdBUSCC=       0xC
    CONSTANT    cmdRESERVED2=   0xD
    CONSTANT    cmdSHUTDOWN=    0xE
    CONSTANT    cmdRESET=       0xF

    ; Constants associated with ROM configuration table
    CONSTANT    teID1=          0x00
    CONSTANT    teID2=          0x01
    CONSTANT    teID3=          0x02
    CONSTANT    teID4=          0x03
    CONSTANT    teID5=          0x04
    CONSTANT    teFLAG=         0x05
    CONSTANT    teADDR=         0x06
    CONSTANT    teBANK=         0x07
    CONSTANT    te16K=          0x0a
    CONSTANT    te32K=          0x09
    CONSTANT    te64K=          0x08
    CONSTANT    teEOM=          0x03
    CONSTANT    teLAST=         0x00
    CONSTANT    teHARD=         0x01

    ; Constants associated with ROM configuration nibble ROMNUM
    CONSTANT    cfMAIN=         .0
    CONSTANT    cfHIDDEN=       .1

    ; 7 ROMs (plus add one for MMIO address)
    CONSTANT    NROMS=          0x7
    ;; ROMLEN MUST BE EVEN!
    CONSTANT    ROMLEN=         0x8
    ; The table offset to first of two Hard ROM slots
    CONSTANT    HRDSLOT=        0x5
    ; The mask for the MMIO address
    CONSTANT    MMIOMASK=       0x0f

; EEPROM memory can be read using NVM registers or TBLPTR
; ORG 0x310000
;ROM1 DE 0x0a, 0x00, 0x01, 0x00, 0x08
    

;*******************************************************************************
; Variable Declarations
; ALL variables are in Bank 0
; For Access Bank addressing, variables must be in the range of 00 - 5Fh
; 
; Access Bank SPR's used in this program
; 
; 
; 
; 
;*******************************************************************************

CMD     EQU     0x00                ; Command register (nibble)
RDY     EQU     0x01                ; Module ready flag
ADDR    EQU     0x02                ; Configuration address (20 bits, 3 bytes)
PCREG   EQU     0x05                ; PC register (20 bits, 3 bytes)
DPREG   EQU     0x08                ; DP register (20 bits, 3 bytes)
;ROMBANK EQU     0x0b                ; Which of 8 PFM banks is active ROM
ROMSIZ  EQU     0x0c                ; Temporary used in initialization
MAPVAL  EQU     0x0d                ; Temporary used in initialization
ARANGE  EQU     0x0e                ; Address range bits 19 downto 15
DRANGE  EQU     0x0f                ; DP register range bits 19 downto 15
PRANGE  EQU     0x10                ; PC register range bits 19 downto 15
CNTR    EQU     0x11                ; General use counter
APTR    EQU     0x12                ; Not used except as scratch
DPTR    EQU     0x15                ; TBLPTR for DP register
PPTR    EQU     0x18                ; TBLPTR for PC register
IDSENT  EQU     0x1b                ; Flag that ID has been sent, ignore ID cmd
TEMP    EQU     0x1c                ; Temporary variable
MIOVLD  EQU     0x1d                ; Address is in MMIO address range
MIOADR  EQU     0x1e                ; MMIO register to read/write
ADIGIT  EQU     0x1f                ; Temporary location for a digit (ASCII 0-8)
ROMNUM  EQU     0x20                ; ROM Configuration nibble @ 2C000h
CMDBUF  EQU     0x21                ; MMIO (16 bytes)/Command Buffer (6 bytes)

ROMDAT  EQU     0x30                ; ROM configuration initialized on start
        ; 5 nibble address of Memory-mapped I/O device
MMIO   EQU     ROMDAT+ROMLEN*NROMS

MAPTBL  EQU     0xe0                ; Top 32 registers of page 0

DATABUF EQU     0x0100              ; Use SRAM page 1 for serial buffer
SECTBUF EQU     0x0200              ; Use SRAM page 2 for sector buffer

;//<editor-fold defaultstate="open" desc="No External Bootloader">
        IFNDEF  XTRNBOOT
;*******************************************************************************
; Protected Bootloader
;*******************************************************************************

;*******************************************************************************
; Reset Vector
;*******************************************************************************

RESVEC  ORG     0x0000              ; processor reset vector
        goto    START               ; go to beginning of program

;*******************************************************************************
; Interrupt Service Vectors
;*******************************************************************************
IV1     ORG     0x8
        goto    ISVHI
    
IV2     ORG     0x18
        goto    ISVLO

        ENDIF   ; end of #ifndef XTRNBOOT
;//</editor-fold>
;//<editor-fold defaultstate="open" desc="External Bootloader">
        IFDEF  XTRNBOOT
#include bootloader.inc
        ENDIF   ; end of #ifdef XTRNBOOT
;//</editor-fold>
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

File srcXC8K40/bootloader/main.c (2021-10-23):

/**
  Generated Main Source File

  Company:
    Microchip Technology Inc.

  File Name:
    main.c

  Summary:
    This is the main file generated using PIC10 / PIC12 / PIC16 / PIC18 MCUs

  Description:
    This header file provides implementations for driver APIs for all modules selected in the GUI.
    Generation Information :
        Product Revision  :  PIC10 / PIC12 / PIC16 / PIC18 MCUs - 1.81.7
        Device            :  PIC18F27K40
        Driver Version    :  2.00
*/

/*
    (c) 2018 Microchip Technology Inc. and its subsidiaries. 
    
    Subject to your compliance with these terms, you may use Microchip software and any 
    derivatives exclusively with Microchip products. It is your responsibility to comply with third party 
    license terms applicable to your use of third party software (including open source software) that 
    may accompany Microchip software.
    
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
    IN NO EVENT WILL MICROCHIP BE LIABLE FOR ANY INDIRECT, SPECIAL, PUNITIVE, 
    INCIDENTAL OR CONSEQUENTIAL LOSS, DAMAGE, COST OR EXPENSE OF ANY KIND 
    WHATSOEVER RELATED TO THE SOFTWARE, HOWEVER CAUSED, EVEN IF MICROCHIP 
    HAS BEEN ADVISED OF THE POSSIBILITY OR THE DAMAGES ARE FORESEEABLE. TO 
    THE FULLEST EXTENT ALLOWED BY LAW, MICROCHIP'S TOTAL LIABILITY ON ALL 
    CLAIMS IN ANY WAY RELATED TO THIS SOFTWARE WILL NOT EXCEED THE AMOUNT 
    OF FEES, IF ANY, THAT YOU HAVE PAID DIRECTLY TO MICROCHIP FOR THIS 
    SOFTWARE.
*/

#include "mcc_generated_files/mcc.h"

/*
                         Main application
 */
void main(void)
{
    // Initialize the device
    SYSTEM_Initialize();

    // If using interrupts in PIC18 High/Low Priority Mode you need to enable the Global High and Low Interrupts
    // If using interrupts in PIC Mid-Range Compatibility Mode you need to enable the Global and Peripheral Interrupts
    // Use the following macros to:

    // Enable the Global Interrupts
    //INTERRUPT_GlobalInterruptEnable();

    // Disable the Global Interrupts
    //INTERRUPT_GlobalInterruptDisable();

    // Enable the Peripheral Interrupts
    //INTERRUPT_PeripheralInterruptEnable();

    // Disable the Peripheral Interrupts
    //INTERRUPT_PeripheralInterruptDisable();

    while (1)
    {
        // Add your application code
    }
}
/**
 End of File
*/

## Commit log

2021-03-08 Data And Utility Files
    Initial content for getting started with programming a MultiMod board.
2021-03-09 File Corrections
    Spelling mistakes and fix .gitingore filtering out the HEX file.
2021-03-27 Source Production Release, v1.0
    Source code for currently released MultiMod boards.
2021-04-15 Remove Two Vulnerabilities
    Prevent buffer overrun. Prevent corruption of ROM Table in flash if software flow control not used.
2021-05-09 Missing Boot Loader File
    The devices.inc file was missing. Updated the bin2inc.py utility program.
2021-10-06 Updated AN310 devices.db File for Bootloader Operation
    The default bootloader client database does not have the microcontroller used in the MultiMod. Database updated for MultiMod support.
2021-10-12 Unconfigure ROMs When RESETX Command Received
    A RESETX command precedes configuration and should have unmapped all ROMs by clearing the Mapping Table. Failure to do so results in Memory Lost when a MultiMod ROM is mapped to 80000h and clashes with RAMs mapped there during configuration checks.
    [rommain.asm]
2021-10-12 Fix Timing Error In RESETX Command Handler
    A CDn interrupt was vectoring control to another handler before the RESETX code could finish. Disable interrupts first, then do the code processing.
    [rommain.asm]
2021-10-23 XC8 Compatible MultiMod Source Code
    The MultiMod application code has been ported to the XC8 assembler in order to run on more recent PIC devices that are not supported by MPASM.
2021-10-30 XC8 Source Version Release
    This MultiMod code release is for the XC8 assembler.
2022-09-23 Added Development Notes
    Some working documentation used during software development.
    [Timing_Budget.xlsx]
2024-10-21 Added Development Notes
    PDF files used during development and a timing budget spreadsheet.
    [Timing_Budget.xlsx]
2024-10-21 PCB Board Files
    PDF files for BOM and schematic, along with Gerber files.
    [71MultiC1.GBL, 71MultiC1.GBO, 71MultiC1.GBS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]
2026-02-24 Added Enclosure STL Files, Updated BOM
    Added the Harwin sockets to the BOM along with Dan's enclosure files.
    [MM Bottom Half.stl, MM Top Half.stl]
2026-02-26 Harwin Socket Press Fit Instructions
